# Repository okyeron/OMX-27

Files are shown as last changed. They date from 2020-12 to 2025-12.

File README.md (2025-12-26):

# OMX-27 version 3



OMX-27 is a compact DIY hardware MIDI controller and sequencer with RGB LED backlit mechanical key switches.

Version 3 of the hardware is based on the RP2040 microprocessor

Kits and specs are [available here](https://www.denki-oto.com/).

Information and code for earlier heardware versions is included in the [Archive](Archive/ReadMe.md) directory.

Dimensions:  313mm x 65mm  

## Docs

[New Documentation](https://okyeron.github.io/OMX-27/docs/)

[Old Documentation](<Docs.md>)

## Firmware 

Kits are shipped with the current firmware already flashed.

The OMX-27 firmware is Open Source and current uses PlatformIO (Arduino)

See [below](<#Firmware-Development>) to compile the firmware yourself.  

## Build

[Build Guide](<build/Build-Kit.md>)

## Web Configurator

[Online Configurator](https://okyeron.github.io/OMX-27/webconfig/index.html)

## BOM

OMX-27 v3 comes with SMD parts pre-assembled. Some alternate thru-hole parts are listed in the [Bill of Materials](<build/BOM.md>) for reference 

## Firmware Development  

Currently the firmware is best worked on with PlatformIO and VSCode. This may change in future.

### PlatformIO / VSCode

Ensure Homebrew in installed. [Instructions](https://brew.sh/)  
Install PlatformIO CLI tools. [Detailed Instructions](https://platformio.org/install/cli)

```sh
# Mac OSX
brew install platformio

# check out the project
git checkout https://github.com/okyeron/OMX-27.git

# go to the project directory
cd OMX-27-RP2040

# compile the project (this may take a while the first time)
pio run

# upload to hardware (press reset and boot and release reset before boot)
pio run -t upload
```

(optional) Install PlatformIO IDE VSCode extension. [Instructions](https://platformio.org/platformio-ide)

Install EditorConfig extension for your text editor. [Instructions](https://editorconfig.org/)
 
To open the project in VSCode :
- open a new window
- select the PlatformIO icon from the Primary Side Bar (left toolbar)
- use the "Pick a folder" button to select the OMX-27 folder you created above

## FAQ

Q: What key switches are recommended?  
A: The board uses a dual-footprint for either Cherry MX or Kailh Choc V1 switches. 

Q: Can I use other key switches?  
A: Yes - as long as they have the same footprint as Cherry MX or Kailh Choc V1 switches and a window/opening for the LED to shine through. NOTE - __Cherry Low Profile__ or__ Kailh Choc V2__ switches have a different footprint and will not work.

Q: What about recommended Keycaps if I want to customize?  
A: Also listed in the [BOM](<build/BOM.md>). It depends on which switches you use. You want a "shine thru" cap with a window for the LED.

Q: Does this project require soldering?  
A: Yes. Thru-hole soldering is required (Pots and switches).  

Q: Can I get the Gerbers or order the pcbs myself?  
A: No. Not open source at this time.

Q: Can I get some of those windowed keycaps you're using?  
A: Yes (send me an email).

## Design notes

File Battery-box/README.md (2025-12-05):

# Optional battery

A lipo battery can be added to OMX-27 v3.   

[This battery from tinycircuits is recommended](https://tinycircuits.com/products/lithium-ion-polymer-battery-3-7v-290mah). Also available from [Mouser](https://www.mouser.com/ProductDetail/TinyCircuits/ASR00007?qs=5aG0NVq1C4wXuuIqe7syiw%3D%3D) or [Digikey](https://www.digikey.com/en/products/detail/tinycircuits/ASR00007/7404517). [Octopart link](https://octopart.com/asr00007-tiny+circuits-84715901)  

The battery plug on the PCB is a JST SH connector (2 pin, 1.0 mm pitch) or you can solder the battery wires directly to the PCB. Please note the PCB markings for polarity. Looking down at the device, the red (+) terminal is on the left.  

A quick test gave about 4 hours of constant use on a single charge of the 290mah battery.  

3D printable battery box models are available below:

The parts are designed to use heat-set inserts for mounting - I used M2.5 4mmx4mm inserts - and then you can just use the same screws inserted from the bottom to attach everything.  

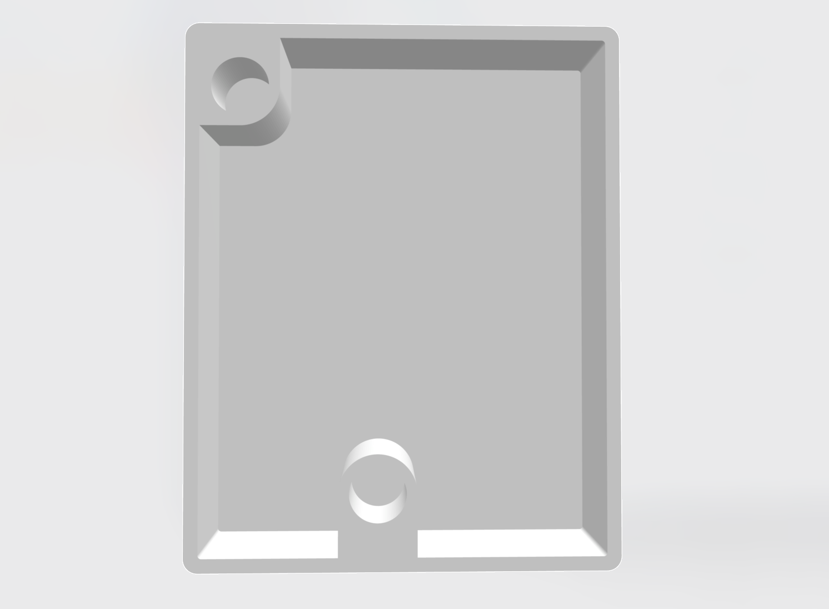
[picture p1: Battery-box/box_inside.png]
<# alt text #> box_inside


[Rectangular box](omx-27_battery_box_1a.stl)
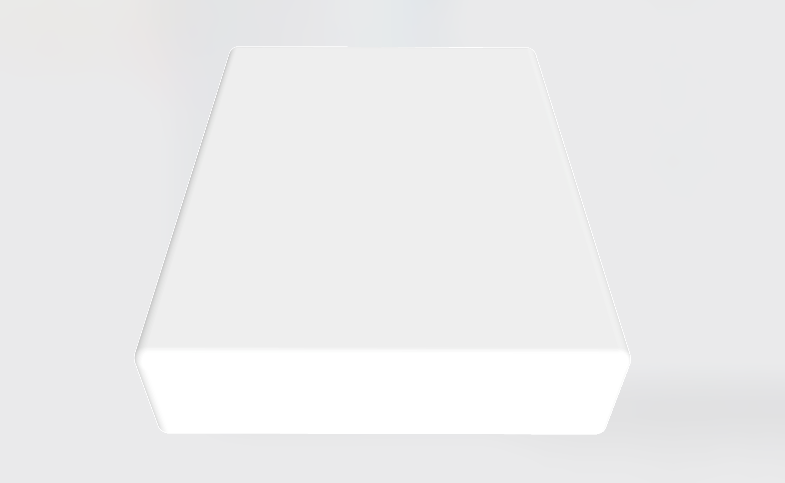
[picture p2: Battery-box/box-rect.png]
<# alt text #> box-rect


[L-shaped box](omx-27_battery_box_1b.stl)
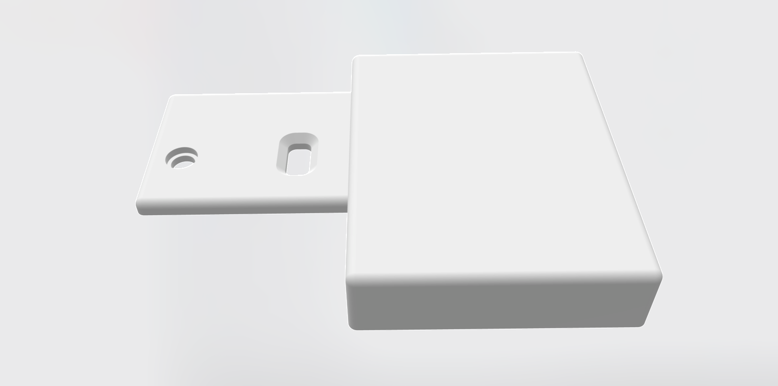
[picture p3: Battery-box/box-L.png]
<# alt text #> box-L


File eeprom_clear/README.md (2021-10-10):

# eeprom-clear

Quick sketch to reset the Teensy eeprom.

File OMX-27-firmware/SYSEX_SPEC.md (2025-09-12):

# OMX Sysex spec

The OMX-27 interfaces with its editor via MIDI Sysex. This document describes the supported messages.

_Work in progress, porting from 16n faderbank editor_

## `0x1F` - "1nFo"

Request for OMX-27 to transmit current state via sysex. No other payload.

## `0x0F` - "c0nFig"

"Here is my current config." Only sent by OMX-27 as an outbound message, in response to `0x1F`. Payload of 32 bytes, describing current EEPROM state.

## `0x0E` - "c0nfig Edit"

~~"Here is a new complete configuration for you". Payload (other than mfg header, top/tail, etc) of 80 bytes to go straight into EEPROM, according to the memory map described in `README.md`.~~ not implemented

## `0x0D` - "c0nfig edit (Device options)"

"Here is a new set of device options for you". Payload (other than mfg header, top/tail, etc) of 32 bytes to go straight into appropriate locations of EEPROM, according to the following map:
```
	//  64 bytes of data:
	//  0 - EEPROM VERSION
	//  1 - Current MODE
	//  2 - Sequencer PlayingPattern
	//  3 - MIDI mode MidiChannel 
	//  4 - 28 - Pots (x25 - 5 banks of 5 pots)
	//  29 - MIDI Macro Channel
	//  30 - MIDI Macro Type
	//  31 - Scale Root
	//  32 - Scale Pattern, -1 for chromatic
	//  33 - Lock Scale - Bool
	//  34 - Scale Group 16 - Bool
	//  35 - midiSettings.defaultVelocity
	//  36 - clockConfig.globalQuantizeStepIndex
	//  37 - cvNoteUtil.triggerMode
	// 	38 - actvie pot bank
	
	//  XX - 63 - Not yet used

```
Example: 
`F0 7D 00 00 0D 09 00 00 00 15 16 17 18 07 1D 1E 1F 20 21 22 23 24 25 26 27 28 29 2A 2B 5B 5D 67 68 69 00 00 00 F7`

## `0x0C` - "c0nfig edit (usb options)"

~~"Here is a new set of USB options for you". Payload (other than mfg header, top/tail, etc) of 32 bytes to go straight into appropriate locations of EEPROM, according to the memory map described in `README.md`.~~ not implemented

## `0x0B` - "c0nfig edit (trs options)"

~~"Here is a new set of TRS options for you". Payload (other than mfg header, top/tail, etc) of 32 bytes to go straight into appropriate locations of EEPROM, according to the memory map described in `README.md`.~~ not implemented

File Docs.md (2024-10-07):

# OMX-27 Documentation

# Table of contents
1. [Concepts](#concepts)
   1. [Layout](#layout)
   2. [Encoder](#encoder)
   3. [AUX Key](#auxkey)
   4. [Potentiometers](#potentiometers)
   5. [Key Switches](#keyswitches)
   6. [Changing Modes](#changingmodes)
   7. [Sub-Modes](#subparagraph1)
   8. [Saving Session State](#savingsess)
2. [Modes](#modes)
   1. [MI - Midi Keyboard](#mimode)
   2. [DRUM - Drum Keyboard](#drummode)
   3. [CH - Chord Keyboard](#chordsmode)
   4. [S1 - Sequencer 1](#s1mode)
   5. [S2 - Sequencer 2](#s2mode)
   6. [GR - Grids Sequencer](#gridsmode)
   7. [EL - Euclidean Sequencer](#elmode)
   8. [OM - Organelle Mother](#organellemode)
   9. [Screensaver](#screensaver)
3. [Hardware](#hardware)

# Concepts 

OMX-27 is a MIDI Keyboard and Sequencer. Both USBMIDI (in/out) and hardware MIDI out (via 1.8" TRS jack) are supported. Various "modes" can be accessed with the encoder and specific functions, parameters or sub-modes can be accessed with the encoder or key-presses/key-combinations.

Sequencer modes have 8 patterns (tracks). Sequencer modes currently send MIDI clock and transport control (start/stop) by default.

CV pitch output is limited to about 4.3 octaves.

USBMIDI should be plug-and-play with any USBMIDI compatible host. iPad works great with the camera connection kit or a [lightning to usb micro cable](https://www.amazon.com/gp/product/B09KLXNYHL). Hardware MIDI TRS output jack is switchable between Type-A and Type-B.

## Layout 

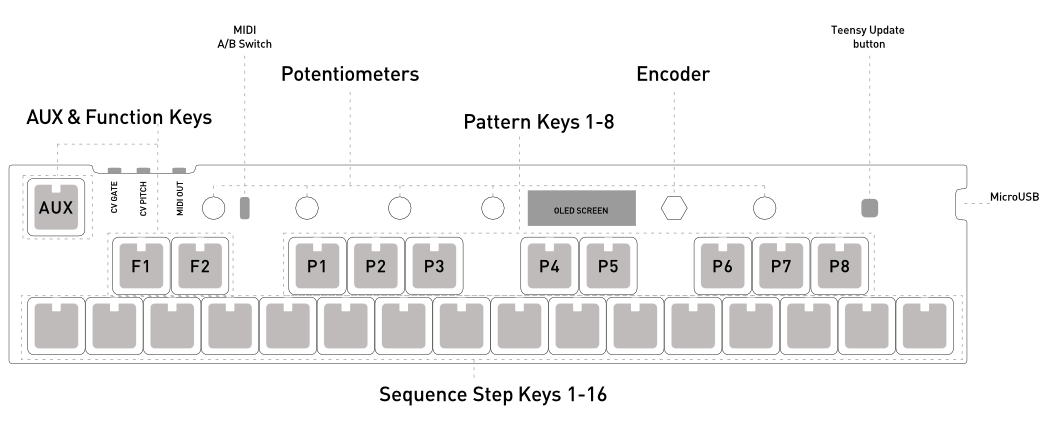
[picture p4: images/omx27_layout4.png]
omx27_layout3


## Encoder 

The encoder is the knob directly to the right of the display.

You can use the encoder to modify parameters and change the selected parameter and page. 

Short press the encoder once to toggle between selecting parameters and editing them. The selected parameter will be highlighted to reflect which mode you are in. 

Long press the encoder to change to a different mode. Once in mode selection, turn the encoder, then short-press to enter the selected mode.

## AUX Key 

The top left key is the AUX Key. 

In the MIDI Keyboard and Chords modes, holding this key gives you access to shortcuts. 

In the sequencer modes, this key is a dedicated start stop button. 

This key is also used in many places to quickly edit a parameter. To do this, hold down aux and turn the encoder to quickly edit the selected parameter without needing to press the encoder. If the encoder was already pressed, it is locked in edit mode and the aux shortcut won't work until you exit by pressing the encoder again.

If you are in a submode, the AUX Key can be used to exit out to the main mode. 

## Potentiometers 

The OMX-27 has 5 potentiometers which are mapped to send continuous controller MIDI messages (CCs). There are 5 banks of CCs available. You can switch banks using the PBNK parameter in the MI and DRUM Modes. 

Bank A is selected by default with the CCs set to controller numbers 21, 22, 23, 24 and 7 (volume). 

The CC's can also be reconfigured on device in the [CC Config page](#ccconfig), which is found on the last page of the MI Mode parameters. You can also configure the CC banks all at once via the [web configurator](https://okyeron.github.io/OMX-27/webconfig/index.html).

## Key Switches 

The functions of the key switches changes depending on which mode you are in. 

In MI Mode, the key switches work like a normal MIDI keyboard. 

In other modes, the keys have specific functions depending on the mode or submode. Most key interactions should also light up that key's LED.

In this documentation keys will be referred to by number, from left to right and position, top or bottom. Mentions of "White" or "Black" keys are in reference to a standard piano keyboard layout.

### "Black keys" (sharp/flat keyboard keys)

The top row (black) keys are referenced as **Top 1-10**.

The first 2 black keys are Function Keys (FUNC)
- F1 - First black key
- F2 - Second black key

FUNC keys are used to perform various shortcuts depending on the mode. 

The other black key functions depend on the current mode.

### "White keys" (bottom row)

The bottom row (white) keys are referenced as **Bottom 1-16**.

These have different functions depending on the current mode. For example, in sequencer modes, these are the sequencer step on/off keys.

## Changing Modes 

The OMX-27 has multiple modes. Each is independent - only one mode can be used at a time. 

Long press the encoder to change modes. 

## Sub-Modes 

Certain actions will cause you to enter a sub-mode, some examples could be editing MidiFX, configuring the pots, or saving/loading presets. If you are in a sub-mode, the AUX key will typically be flashing or red. A quick press of the AUX key will exit the sub-mode. 

## Macro-Modes 

Macro modes are like sub-modes in that they are an alternate mode. Macro-modes can take over the keys, display, encoder, and pots. 

Macro modes are specialized modes designed to be used to control external gear like the M8, Norns, and Deluge. 

You can enter and exit macro modes by double clicking the AUX key in the root level mode. 

Learn more about macro modes [here](#mimacromodes)

## Saving Session State 

To save your current session to memory, first enter Mode Select by holding the encoder. While this is active press AUX to save. 

The next time you restart your device, your last active mode will be loaded, and saved patterns and settings will be recalled. 

Saving is a long operation and not recommended to do while in the middle of a performance. 

---

# Modes 

The OMX-27 has multiple modes. Each is independent - only one mode can be used at a time. 

Long press the encoder to change modes. 

The current modes are:  
- [MI - Midi Keyboard](#mimode)
- [DRUM - Drum Keyboard](#drummode)
- [CH - Chords](#chordsmode)
- [S1](#s1mode) - A step sequencer with 8 patterns that can be up to 64 steps. Only one pattern can be active at a time  
- [S2](#s2mode) - The same as S1 but all 8 patterns are active  
- [GR - Grids Sequencer](#gridsmode) (A rhythm sequencer based on Mutable Instruments Grids)  
- [EL - Euclidean Sequencer](#elmode)
- [OM - Organelle Mother](#organellemode)

## MI - MIDI 

MIDI Keyboard. This mode makes the 26 keys act like a normal musical keyboard on a chromatic scale. 

### AUX Key: 

The top left key standing by it's lonesome is the AUX Key. While holding down this key, the other 26 keys will no longer play musical notes and instead give you access to quick shortcuts. 

Holding the AUX key will let you quickly edit the selected parameter. To do this, hold down aux and turn the encoder to quickly edit the selected parameter without needing to click the encoder. If the encoder was already clicked, it is locked in edit mode and the aux shortcut won't work until you exit by pressing the encoder again.

If you are in a submode like editing midi fx or the arp, the AUX Key can be used to exit out to the main mode. 

### KEYS & LEDS

Each of the 26 keys will play a note on the chromatic scale. The keys will light up when pressed. They will also light up to show incoming midi notes. 

If a scale is enabled, the keys that are in the scale will be lit up. 

### KEYS & LEDS - AUX Button Held

Hold down the AUX key to access quick functions. 

#### Top Keys
- **[1] Previous Parameter** : Selects the previous parameter in the menu
- **[2] Next Parameter** : Selects the next parameter in the menu

##### MidiFX
Select which midifx slot to send the keyboard notes to.
Double click or long hold a MidiFX key to enter the MidiFX sub-mode and edit the effects.
See [MidiFX](#midifx) for more info. 

- **[5] MidiFX Off** : Notes from the drum key will be sent directly out
- **[6] MidiFX 1**
- **[7] MidiFX 2**
- **[8] MidiFX 3**
- **[9] MidiFX 4**
- **[10] MidiFX 5**

#### Bottom Keys
##### The Highest Highs and Lowest Lows
- **[1] Octave Down**
- **[2] Octave Up**

##### Arpeggiator
- **[12] Edit Params** : Enters a pass through arp edit sub-mode allowing you to edit arp values and also play the keyboard. You can also edit the arp in the MidiFX sub-mode but will need to exit the sub-mode to play the keyboard.
- **[13] Change Pattern** : Cycles through arpeggiator patterns  
- **[14] Change Octave** : Cycles through arpeggiator octave ranges  
- **[15] Toggle Hold** : Toggles the arpeggiator hold function  
- **[16] Power** : Toggles the arpeggiator on and off  

### Menu Pages

**Page 1 - Midi Out:**
- `OCT`: Current Octave  
- `CH`: Active MIDI Channel 
- `VEL`: The velocity level for midi notes 

**Page 2 - Inspect:**
Not editable, this shows which notes and CC's have been sent. 
- `P CC` : Pot CC, this is the CC number of the last pot that was used. 
- `P Val` : This is that last CC value of the last pot that was used. 
- `NOTE` : This is the number of the last note that was sent. Note that notes generated by MidiFX will not be seen here. 
- `VEL` : This is the velocity of the last note that was sent. 

**Page 3 - Midi Tools:**
- `RR`: RoundRobin MIDI Channel distribution
- `RROF`: RR offset value   
- `PGM`: MIDI program change  
- `BNK`: MIDI bank select.

**Page 4 - Pots & Macros:**
- `PBNK`: Potentiometer bank select
- `THRU`: When "On" incoming USBMIDI is passed to TRS MIDI Out.
- `MCRO`: MIDI Macro Mode Select (default is OFF)
- `M-CH`: MIDI Macro Mode Channel

**Page 5 - Scales:**
- `ROOT` : Select the root note for scale mode
- `SCALE` : Select a scale or turn off scale mode
- `LOCK` : Locks to the active scale. If this is enabled, you can only play notes in the scale
- `GROUP` : Groups all the notes of the scale across the lower row of 16 keys. 

**Page 6 - Config:**
- `CC` : Function, press down on the encoder to use. This enters the configuration tool for setting up the CC values for each pot bank.

### Musical Scales

Scales can be turned on using the 5th parameter page. When a scale is enabled, the keys in the scale light up, and the root notes light up a brighter color. You can still play chromatically and out of key. 

Enabling the 'LOCK' param makes it so only the notes in the scale send midi notes out. 

Turning on the 'GROUP' parameter maps the scale across the lower row of 16 keys. The root note starts on bottom key 2 which would normally be a C in chromatic mode. 

These scale settings also control the scale of the Scaler MidiFX when they are set to use the global scale. 

### CC Configuration Submode 

This mode lets you change the CC values that the potentiometers send out. 

Bottom Keys 1-5 let you quickly change the selected bank.  

Press the AUX key to exit. 

### MidiFX 

MidiFX are effects that can be applied after midi data is generated by playing keys or a sequencer and before any midi data goes out of the device. 

MidiFX can currently only be used within the: MIDI Keyboard (MI), Chords (CH) and Euclidian (EL) modes.

MidiFX currently only work on internally generated midi, but may support external midi coming in from USB in the future. 

MidiFX are arranged in groups of 8 MidiFX. A group of 8 is called a MidiFX Group. In the MI Mode, midi notes generated by playing the keyboard can only be routed to one MidiFX Group. In the sequencer modes, midi notes can be routed to different MidiFX groups by track. 

Think of a MidiFX group as a pedalboard for Midi. Midi data comes in from the left and go to MidiFX slot 1, then out of slot 1 to slot 2, until slot 8, then out of the device. 

You can change the active MidiFX group in the MI Mode and the Chords modes by holding aux and pressing one of the Top Keys 6-10. 

To enter the MidiFX submode, hold AUX, then hold or double click on a MidiFX Key(Top Keys 6-10). 

Top Key 1: Copy  
Top Key 2: Paste  
Top Key 1 + 2: Cut  
Top Keys 3 - 10: Select a MidiFX slot  
Bottom Keys: Add or change the type of MidiFX for a slot. You must hold down the MidiFX slot key in order to change.   

To move a MidiFX slot around, you can either cut and paste, or you can hold a MidiFX slot key and turn the encoder.  

There are several different MidiFX available for each slot. Select a MidiFX slot, and you can edit the parameters for that instance of a MidiFX.  

Each MidiFX type has a chance parameter. If this is less than 100%, than there is a chance this effect will not be applied.  

Available MidiFX:  
- Chance: Uses randomness to determine if a note passes through: 100% or gets killed: 0%  
- Transpose: Transpose midi notes by semitones or octaves  
- Randomizer: Randomize notes by range, octaves, velocities, and note lengths.  
- Harmonizer: Generate multiple notes from a single note. Great for 1 key chords, or to randomly play chords by setting it's chance parameter to less than 100%  
- Scaler: This forces notes into a specific scale.  
   - By default this uses the global scale. Modifying the root and scale pattern parameters changes the global scale.   
   - You can turn 'GLBL' to off to make this MidiFX instance use it's own unique root and scale pattern.   
- Make Mono: This forces polyphonic midi notes into monophonic.   
- Arpeggiator: This is an advanced arpeggiator. An arpeggiator MidiFX is automatically  added to a MidiFX group if you use any of the arpeggiator AUX quick keys.  
   - Try combining the arpeggiator with other MidiFX either before or after the arpeggiator for interesting effects.  
   - Arpeggiators are reasonably resource intensive, try to avoid using more than 3 of them in a MidiFX group for optimal performance.  

### Arpeggiator 

The arpeggiator is an advanced arpeggiator with many different combinations of patterns, Mod Patterns, and Transpose patterns. 

The arpeggiator is actually a MidiFX and is only available in the modes that support MidiFX: MIDI Keyboard (MI), Chords (CH), and Euclidian Sequencer (EL).

In MIDI Keyboard and Chords modes, holding AUX allows you to quickly change basic settings of the arpeggiator. In order to access the more advanced functionalities, you need to access the arpeggiator parameters by either entering the MidiFX Group submode or by accessing the Arpeggiator pass-through mode by using AUX + Bottom Key 12.

The arpeggiator sends clock when in use.

#### Arp Menu Pages:

**Page 1 - Arp Settings 1:**
- `MODE`: Arpeggiator mode: On, 1-Shot, Once, Hold  
- `PAT`: The pattern of the arpeggiator  
- `RSET`: Determines what will cause the arpeggiator to reset  
- `CHC%`: How likely an incoming note will be used with the arpeggiator. Try playing with in the euclidean sequencer mode  

**Page 2 - Arp Settings 2:**
- `RATE`: How fast the arpeggiator plays  
- `RANG`: How many octaves to advance through  
- `GATE`: How long a note coming out of the arpeggiator is  
- `BPM`: Controls the master tempo  

**Page 3 - Arp Settings 3:**
- `ODIST`: How many semitones to consider an octave. Set to -12 to make the arpeggiator go downwards. Set to a semitone offset if you like to get weird  

**Page 4 - Inspect:**
These are not modifyable  
- `VEL` : Velocity based on first notes that turn on the arp  
- `CHAN` : First note that starts the arp sets the channel  
- `MIDI` : If midi data is output
- `CV` : If CV data is output  

**Page 5 - Mod Pattern:**
- Each of the 16 steps can be used to modify the arp pattern in various ways  

**Page 6 - Transpose Pattern:**
- Each of the 16 steps can be used to transpose notes in semitones 
- Recommend trying to use for some cool one key bass patterns  

### MIDI Macro Modes 

Midi macro modes are specialized Midi controller modes designed to be used with specific hardware that can be controlled via Midi. 

If a midi macro is selected, you can double click the AUX key to enter the midi macro mode, and double click the AUX key to exit the macro mode.

Midi macro modes send control midi commands on the Midi Macro channel, which is `M-CH` in the parameters.

Macro modes are supported in the MI and DRUM modes. 

#### M8 Macro Mode

From MI Mode, be sure `M8` is selected from the `MCRO` parameter and then double click the AUX button to enter Macro Mode.

`M-CH` should be set to the same value as the Control Map Channel in the M8 MIDI settings screen. Default is set to channel 10.  

Double click the AUX button again to exit Macro Mode.

The M8 macro mode has two pages, which change what the Keys do.

* Mute Solo Page:

The bottom row of keys correspond to mutes (orange) and solos (red). The top "black keys" are as follows:  

```
Orange - release all mutes  
Lime - go to mixer screen  
Cyan - snapshot load/paste *   
Magenta - snapshot save/enter selection mode *  
Red - release all solos  
Yellow - waveform display  
Blue - play  
```
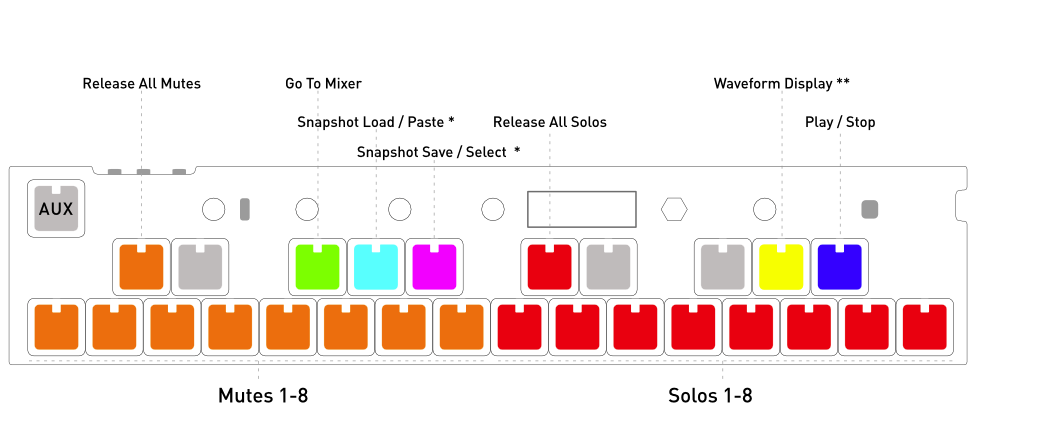
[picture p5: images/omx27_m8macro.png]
omx27_m8_macro_mode


When M8 is selected from the `MCRO` parameter - potentiometers send on the `M-CH` MIDI channel in both regular keyboard mode and in the macro mode. However, notes played on keys send on the currently selected `CH` MIDI channel.

**Notes:**
* M8 must be on the Mixer view for snapshots.  
* Snapshot Load uses the M8 key combo [SHIFT]+[OPTION]. On any view with a grid (song, chain, phrase, table, etc.) this key enters selection mode.  
* Snapshot Save uses the M8 key combo [SHIFT]+[EDIT]. On any view with a grid this key pastes the copied contents from selection mode.  

* Control Page:

This page lets you navigate the M8 using the keys on the device instead of the keys on the M8.

Top Key 1 and Bottoms Keys 1-3: These correspond to the directional arrow keys. 

Top Key 4: Option Key
Top Key 5: Edit Key
Bottom Key 6: Shift Key
Bottom Key 7: Play Key

The right half of the Keyboard is a 1-octave midi keyboard that sends notes on the same midi channel as when not in macro mode. 

#### Norns Macro Mode

The Norns macro mode gives you the ability to control the Monome Norns using the OMX-27. In this mode, you can control the three buttons and three encoders using the OMX-27. This is useful if your norns is not located close by and you would like to control it.

Find the `MCRO` parameter in the menu and select `NRN` to enable the Norns Macro mode. 

Double click the AUX button to enter Macro Mode. Double click the AUX button again to exit Macro Mode.

##### Norns Setup
In order for this to work, you will need to setup the [qremote mod](#https://llllllll.co/t/qremote/57549) on your norns. 

Obtain the mod here: https://llllllll.co/t/qremote/57549

or install in Maiden
`;install https://github.com/Quixotic7/qremote`

Enable the mod in the mod menu of norns, connect your OMX-27 to the norns and restart. The easiest way to connect the OMX-27 is to simply use a USB port on the norns. 

The qremote mod will default to using midi channel 10. If you are using defaults, make sure your OMX-27 Macro Channel `M-Chan` is set to 10. 

Use the default configuration for encoders and buttons:

The default cc’s for the encoders are 58, 62, & 63

The default cc’s for the buttons are 85, 87, & 88

You can change these in the parameter menu. Or edit the script to change the defaults.

##### Norns Buttons
These act the same as if pressing the buttons on the Norns.
- **[Top 3] B1**
- **[Bot 4] B2**
- **[Bot 5] B3**

##### Norns Encoders
Use the OMX-27 Encoder to control one of the Norn's encoders. Since the OMX-27 only has one encoder, shortcut keys are used to determine which encoder will be controlled.
- **[Top 5] Enc 1**
- **[Bot 6] Enc 2**
- **[Bot 7] Enc 3**

##### Norns Navigation
The keys of the OMX-27 are used to emulate up/down left/right keys useful for menu navigation. These work by controlling encoder 1 or encoder 2, sending one tick either clockwise or counter-clockwise. 
- **[Top 1] Up**
- **[Bot 1] Left**
- **[Bot 2] Down**
- **[Bot 3] Right**

#### Deluge Macro Mode

The latest Deluge Community Firmware has added a new feature called Midi-Follow. 

https://github.com/SynthstromAudible/DelugeFirmware/blob/community/docs/features/midi_follow_mode.md

This mode provides default CC mappings to control many of the synth parameters with a midi controller and to be able to play the active instrument without needing to midi learn everything. 

This Macro Mode provides parameter banks to control every available parameter on the Deluge using the 5 pots of the OMX-27. The Deluge will also send back the values of the parameters to the OMX-27 which will update the values in each bank on the OMX-27. This will only work if you are connected via USB as the OMX-27 does not have TRS Midi-in. Values are updated when changing them from the gold knobs, or from edit view, when entering a clip view, or when changing a synth or kit.

##### Deluge Setup

Download and install the latest Deluge Nightly Firmware: https://github.com/SynthstromAudible/DelugeFirmware/releases . This Midi-Follow feature is not included in the 1.0.1 release. There is also a new beta build released which should have the feature, but it is not confirmed. 

To install the FW, place the `.bin` file on your sd card, ensuring there are no other `.bin` files. Carefully reinsert the SD Card in the Deluge, if it is misangled it can fall into the device. Turn on the Deluge while holding the shift key. 

Hold Shift + Click the main Select Knob, find Midi, click the Select Knob, find "MIDI-FOLLOW", click the select Knob, find "CHANNEL", click the select Knob, set each channel to something, I recommend channel 10. Also from the "MIDI-FOLLOW" level, select "FEEDBACK" and set the channel to 10 as well. 

For further help see https://github.com/SynthstromAudible/DelugeFirmware/blob/community/docs/features/midi_follow_mode.md 

##### OMX Setup

Find the `MCRO` parameter in the menu and select `DEL` to enable the Deluge Macro mode. Change Macro Channel `M-CH` to 10 or whatever you set your Deluge to.

Double click the AUX button to enter Macro Mode. Double click the AUX button again to exit Macro Mode.

##### KEYS & LEDS
The keyboard is split into two halves. 

The right octave of the keyboard works the same as the midi keyboard from MI Mode and will inherit it's settings. 

The left half of the keyboard is dedicated to selecting different banks of parameters. 

Some keys will have multiple banks assigned to them, to access the other banks, click the key a second time. 

- **[Top 1] Env 1**
- **[Top 2] Env 2**
- **[Top 3] LPF**
- **[Top 4] HPF**
- **[Top 5] EQ**
- **[Bot 1] Master**
- **[Bot 2] OSC 1**
- **[Bot 2] FM 1** : Click the key a second time
- **[Bot 3] OSC 2**
- **[Bot 3] FM 2** : Click the key a second time
- **[Bot 4] LFO Delay Reverb**
- **[Bot 4] ModFX** : Click the key a second time
- **[Bot 5] Distortion Noise**
- **[Bot 6] Arp Sidechain**
- **[Bot 7] Custom 1** : Bank of 5 parameters you can midi learn to whatever
- **[Bot 7] Custom 2** : Click the key a second time

##### KEYS & LEDS - AUX Button Held

###### Select a parameter
This will select a parameter. If you click the encoder to enter edit mode the encoder can be used to change the value without needing to pickup the pot. 
- **[Top 1] Param 1**
- **[Top 2] Param 2**
- **[Top 3] Param 3**
- **[Top 4] Param 4**
- **[Top 5] Param 5**

###### Change octave
This effects the keyboard on the right half.
- **[Bot 1] Octave Down**
- **[Bot 2] Octave Up**

###### Lock the AUX View
This locks the AUX view, allowing you to use the AUX shortcuts without holding down the AUX key. To unlock, use the AUX button again or press the lock AUX key. 
- **[Bot 4] Lock AUX**

###### Revert Values
This will revert the values of the current bank to their previous state. The previous state is saved whenever the bank is changed, or when the values are updated from incoming Midi from the Deluge. This is fun to play with with the effects, crank up the bitcrush, delay, or reverb temporally, then press this button to revert it back to what it previously was. 
- **[Bot 8] Revert Bank**

##### POT Pickups
Depending on which bank is selected, the OMX-27 will send out different CC's for each of the 5 potentiometers. When a change is detected on a pot, the screen will update to show the name of the current bank, parameter, and value that is being sent. 

In the MI and Drum modes, the pot values that are sent jump to the current position of the pot. In the Deluge Macro, you will need to pickup the value before it is sent. The small triangle on the screen represents the current raw value of the pot, the horizontal bar represents the value for that parameter. You will need to turn the knob left or right to pickup the value. 

The Deluge can also be setup to pickup, however this macro will work best if the Deluge is set to jump. 

##### Encoder
The encoder can be used to send out values without needing it to be picked up. To edit a parameter, click the encoder, then turn. There is not currently a visual representation to provide feedback for this. If you click the encoder again, you can scroll to change which parameter in the bank to control. You can also use the AUX shortcuts to quickly jump to parameters, or lightly wiggle a knob. 

---

## DRUM - Drum Keyboard 

This mode shares a lot in common with the MI mode. The main difference is that instead of each key being a key on a chromatic keyboard, each of the 26 keyboard keys can be assigned to send out a unique note, velocity, and midi channel. This is useful if you want to use the OMX to play an external drum machine or samples, or multiple drum machines on different  midi channels, or for any purpose you'd like really, feel free to get creative!

The grouping of 26 keys is called a "Drum Kit" and you can store up to 8 different drum kits on the OMX. 

Press any key to play it. A note on will be sent when pushed and a note off will be sent once released. 

**Selected Drum Key** - This is the last key that was pressed down, it is visually represented by a flashing LED.

The first two pages on the OMX display can be used to change the settings for the selected drum key. Each key can be configured to send a unique note number, velocity, midi channel, and be routed to one of the 5 MidiFX slots. Yes, you can use multiple MidiFX at once. You could have one drum key be routed to MidiFX 1 which has an arp to play a bassline, another key could go to MidiFX 2 with a different arp to play a melody, then another key could be setup to play a kick drum which is routed to MidiFX 3 which has a randomizer enabled to randomly vary the velocity each time it is played. Go wild, get creative, there are no bounds, welcome to OMX!

### Menu Pages
**Page 1 - DrumKey 1:**
Values apply to the selected drum key
- `NOTE` : Midi note number that the drum key will send
- `CH` : Midi Channel that the drum key will send
- `VEL` : Velocity of the note the drum key sends
- `FX#` : Number of the MidiFX slot that the note is sent to

**Page 2 - DrumKey 2:**
- `HUE` : Changes the color of the selected drum key
- `HUE RND` : Function, press down on the encoder to use. This will randomize all the hues in the current drum kit.

**Page 3 - Scales:**
This changes the current scale settings. While a scale won't normally apply to the drum kit, the scale settings are shared globally with the MidiFX. So if you are using a scale MidiFX, this makes it easy to change up the scale without needing to edit the MidiFX. 
- `ROOT` : Root note of the scale. 
- `SCALE` : Which scale to use.
- `LOCK` : Only notes in the scale can be played, has no effect on the drum kit keys. 
- `GROUP` : Groups the notes in keyboard view accross the lower keys, no effect on the drum kit keys. 

**Page 4 - Inspect:**
Not editable, this shows which notes and CC's have been sent. 
- `P CC` : Pot CC, this is the CC number of the last pot that was used. 
- `P Val` : This is that last CC value of the last pot that was used. 
- `NOTE` : This is the number of the last note that was sent. Note that notes generated by MidiFX will not be seen here. 
- `VEL` : This is the velocity of the last note that was sent. 

**Page 5 - Pots & Macros:**
Settings for the potbank, midi, and macro modes. 
- `PBNK` : Pot Bank - Determines which potbank is active. 
- `THRU` : Midi Thru - If this is on, incoming midi from USB will be sent out the TRS midi jack. 
- `MCRO` : Macro - Determines which macro is active. Macros can be entered by double clicking the AUX key. 
- `M-CH` : Macro channel - Determines which midi channel is used by the macro. 

**Page 6 - Config**
- `CC CFG` : Function, press down on the encoder to use. This enters the configuration tool for setting up the CC values for each pot bank.

### KEYS & LEDS - Main Screen
Each key represents a drum pad in your drum kit. 

Pressing a key will send a note on. Releasing it will send a note off. Which note is sent for each key can be configured by pressing the key, then editing it's varaibles in page 1 and 2 of the menu.

The flashing key is the Selected Drum Key. 

Each key can be any color determine by the HUE variable of each drum key. 

### KEYS & LEDS - AUX Button Held
Hold down the AUX key to access quick functions. 

#### Top Keys
- **[1] Previous Parameter** : Selects the previous parameter in the menu
- **[2] Next Parameter** : Selects the next parameter in the menu

##### saving and loading drum kits
- **[3] Load Kit** : Use this to load a kit
- **[4] Save Kit** : Use this to save a kit

##### MidiFX
Unlike the MI Keyboard mode, the midifx slot only applys to the selected drum key.
See MidiFX for more info. 
- **[5] MidiFX Off** : Notes from the drum key will be sent directly out
- **[6] MidiFX 1**
- **[7] MidiFX 2**
- **[8] MidiFX 3**
- **[9] MidiFX 4**
- **[10] MidiFX 5**

#### Bottom Keys
##### Quickly switch kits
- **[1] Load Prev Kit** : Loads the next kit out of 8, any changes to the current kit will be autosaved
- **[2] Load Next Kit** : Loads the previous kit out of 8, any changes to the current kit will be autosaved

##### Arpeggiator
- **[12] Edit Params** : Enters a pass through arp edit sub-mode allowing you to edit arp values and also play the keyboard. You can also edit the arp in the MidiFX sub-mode but will need to exit the sub-mode to play the keyboard.
- **[13] Change Pattern** : Cycles through arpeggiator patterns  
- **[14] Change Octave** : Cycles through arpeggiator octave ranges  
- **[15] Toggle Hold** : Toggles the arpeggiator hold function  
- **[16] Power** : Toggles the arpeggiator on and off  

### Potentiometers

---

## CH - Chords 

Ever wanted to play insanely complex chords with the click of a button? Well now you can! In Chord mode, the bottom 16 keys can each be assigned to play a unique chord. 

### UI Views

There are two UI views: "Split" and "Full". This can be changed on page 2. By default, the UI layout is in "Split Mode" meaning the right half of the keyboard works like a 1 octave keyboard and the left half will give you 8 chords that can be played. In "Full" mode, each of the 16 bottom keys will play chords.

### Key Modes

There are several different modes available which can be switched using the top keys 3, 4, & 5.

- **[Top 3] Play Mode**
- **[Top 4] Edit Mode**
- **[Top 5] Strum Mode**

#### Play Mode
- **[Top 3] Play Mode**

This mode is where you want to be if you would like to play chords and the keyboard(Split UI Mode) at the same time. Switching to this mode will bring the menu to the first page, displaying a keyboard that shows the notes of the last chord key that was pressed. You can still edit chords through the menu by switching pages.

#### Edit Mode
- **[Top 4] Edit Mode**

This mode is for editing the available chords and will bring the menu to the chord edit page. 

When in the edit mode and in the "Split" UI view, you can hold down a chord key on the left half and press a key on the right half to set the root note for basic chords. For interval chords, the right half will not change anything. 

The first two top keys, key 1 and key 2 act as function keys F1 and F2 in this mode.

- **[Top 1 - F1] Edit Chord** : Holding F1 and pressing a chord key will enter a edit chord submode.   
- **[Top 2 - F2] Copy Chord** : Holding F2 and pressing a chord key will save the selected chord to the newly selected chord slot. 

#### Strum Mode
- **[Top 5] Strum Mode**

This mode allows you to strum chords using the encoder. The UI view will change to "Full" in this mode. 

To use this mode hold down a chord key and turn the encoder CW or CCW. Only the last pressed chord will be strummed. Multiple chords will not be strummed. 

##### Strum Pot Parameters. 
In strum mode, the 5 pots are used to change the behaviour of the strum. 

- **[Pot 1] Sens - Sensitivity** : This determines how much the encoder needs to be turned to trigger a new note
- **[Pot 2] Wrap** : If this is off, the chord can be strummed once, if this is on, the chord will wrap back to the beginning like an arpeggio. 
- **[Pot 3] Increment / Octave** : This is only valid if Wrap is on. If it is, each time the chord wraps the notes will increase by an octave. This value determines how many octaves will be added before resetting. 
- **[Pot 4] Sustain** : This value determines how long each strum note will be played for. 
- **[Pot 5] Not Assigned**

### Chord Key Settings

A chord key is either bottom key 1-8 in "Split" UI mode or bottom key 1-16 in "Full" UI Mode. Pushing a chord key will play a chord, and releasing the key will stop playing the chord. Multiple Chord Keys can be pressed at once, and also combined with the 1 Octave midi keyboard on the right half in "Split" UI mode. 

Each chord key can have a unique chord type, velocity, midi channel, and be routed to one of 5 MidiFX(#midifx) slots. 

The last chord key that was pressed becomes the selected chord key. This is visually represented on the LEDs as that key will stay lit up

**Page 4 - Chord Key Settings:**
These parameters apply to the selected chord key
- `TYPE` : Determines the chord type: Basic`BASC` or Interval`INTV`, see section below on chord types. 
- `MIFX` : Which [MidiFX](#midifx) will this chord be sent to? 
- `VEL` : Velocity of the notes in the chord
- `MCHAN` : Midi channel of the notes that this chord gets sent to

### Chord Types

Two types of chords are currently available: Basic and Interval. Basic chords don't have many settings and are quick to tweak. Interval chords have a lot more options and are linked to the current global musical scale. 

#### Basic Chords 
These chords have no relation to the current global musical scale. 

All the parameters are shown on a single page that will show 4 ghosts. 

- `NOTE` : Determines the root note of the chord
- `OCTAVE NUMBER` : Determines the octave of the root note
- `GHOSTS` : The ghosts determine how the chord is voiced. Each ghost represents the order of the notes in the chord. The vertical position of a ghost determines the velocity of that notes. A large white ghost will play a note in the same octave as the root note. A large black ghost will play a note one octave below. A short white ghost will play a note one octave above. 
- `SCALE` : Determines the scale of the chord. The last scale is called "Custom" and will let you manually set the notes in the chord. 

##### Custom Chords
If `SCALE` is set to `Custom` an additional page in the menu will be revealed. In this page you can program up to 6 notes. 

The first 4 notes will be modified +- an octave, or turned off based on your `GHOST` settings

The value of each note in a custom chord is defined as a semitone from the root note of the chord. For a C Maj basic triad chord, you would set this to `RT +4 +7` . `RT` means root note. 

#### Interval Chords 
These chords are linked to the current global musical scale. If you play an interval chord and it does not sound good, start by seeing if you have a global scale enabled, and make sure it's not chromatic. 

##### Interval Menu Page 1
- `#NTS` - Number of notes : How many notes to play, 1 - 4
- `DEG` - Degree : Determines which degree of the the current global scale to start the chord on. If the global scale was C Maj, then Deg 0 would play a chord that starts on C, Deg 1 would play a chord that starts on D, Deg 6 would play a chord that starts on B. 
- `OCT` - Octave : The octave of the chord is determined by the global octave +- this value. 
- `TPS` - Transpose : This will transpose the chord by a seminote. Do note that if you transpose a interval chord it will no longer be in scale. 

##### Interval Menu Page 2
- `SPRD` - Spread : This determines how many octaves the chord is spread out across the keyboard. 
- `ROT` - Rotate : This rotates the notes of the chord. for a C Maj Triad, rot of 0 will play C E G, rot of 1 will make E the lowest note, playing E G C+1oct, rot of 2 will make G the lowest note
- `VOIC` - Voicing : Changes the voicing of the chord. Still stays in scale, but will shift notes or add additional notes. 

##### Interval Menu Page 3
- `UPDN` - Spread Up & Down : This will spread the notes out in a negative octave and positive octave. 
- `QRTV` - Quartal Harmony : This enables Quartal Harmony. I have no idea what this is doing music theory wise, but it sounds cool. Technically it's bumping the first note up two octaves, the third note up one octave, and the fourth note down 1 octave. It's supposed to separate the notes by 4ths. 

### Menu Pages

##### Menu Page 1 - Keyboard
This page will display a keyboard on the screen showing which notes are being played from the last chord key that was pressed. 

##### Menu Page 2 - Chord Mode Settings
- `UI` : Change the UI View from `SPLIT` or `FULL`. Split view adds a 1-octave midi keyboard on the right half of the keys. in Full view, all 16 of the bottom keys play chords.

##### Menu Page 3 - Keyboard Midi Settings
These settings apply to the 1-octave keyboard on the right side if the UI View is in `SPLIT` view. Each chord has unique settings.
- `OCT`: Current Octave. This value also changes the base octave used by interval chords
- `CH`: Active MIDI Channel 
- `VEL`: The velocity level for midi notes 

##### Menu Page 4 - Pots and Macros
- `PBNK`: Potentiometer bank select
- `THRU`: When "On" incoming USBMIDI is passed to TRS MIDI Out.
- `MCRO`: MIDI Macro Mode Select (default is OFF)
- `M-CH`: MIDI Macro Mode Channel

##### Menu Page 5 - Scale Settings
The scale settings apply to the 1-octave keyboard on the right side if the UI View is in `SPLIT` view and also will effect the interval chord keys. 
A scale should be set to something other than chromatic to get good results from interval chords. 
- `ROOT` : Select the root note for scale mode. This changes what note the interval chords will play. 
- `SCALE` : Select a scale or turn off scale mode
- `LOCK` : Locks to the active scale. If this is enabled, you can only play notes in the scale
- `GROUP` : Groups all the notes of the scale across the lower row of 16 keys. 

##### Menu Page 6 - Chord Key Settings
This changes the settings of the selected chord key. See [Chord Key Settings](#chordkeysettings)

##### Menu Page 7 - Basic or Interval Chord Key Settings
These pages will be different depending if the selected chord key is set to Basic or Interval.
See [Basic Chords](#basicchords) or [Interval Chords](#intervalchords)

### KEYS & LEDS - AUX Button Held
Hold down the AUX key to access quick functions. 

#### Top Keys
- **[1] Previous Parameter** : Selects the previous parameter in the menu
- **[2] Next Parameter** : Selects the next parameter in the menu

#### Saving and loading
- **[3] Load Bank**
- **[4] Save Bank**

##### MidiFX
This sets the MidiFX slot that either the keyboard in split UI view is being sent to, or the selected chord key is being sent to. Whichever key was last used determines this. You can also change the midifx slot a chord key is sent to from the menu, see [Chord Key Settings](#chordkeysettings)
Hold or double click a MidiFX key to enter the MidiFX submode. 
See [MidiFX](#midifx) for more info. 
- **[5] MidiFX Off**
- **[6] MidiFX 1**
- **[7] MidiFX 2**
- **[8] MidiFX 3**
- **[9] MidiFX 4**
- **[10] MidiFX 5**

#### Bottom Keys
##### Change Octave
This changes the global octave. This value will change the octave of the midi keyboard in split view and also change the base octave of interval chords.
- **[1] Prev Octave**
- **[2] Next Octave**

##### Arpeggiator
This effects the Arpeggiator on the currently selected MidiFX slot that the midi keyboard is being sent to.
- **[12] Edit Params** : Enters a pass through arp edit sub-mode allowing you to edit arp values and also play the keyboard. You can also edit the arp in the MidiFX sub-mode but will need to exit the sub-mode to play the keyboard.
- **[13] Change Pattern** : Cycles through arpeggiator patterns  
- **[14] Change Octave** : Cycles through arpeggiator octave ranges  
- **[15] Toggle Hold** : Toggles the arpeggiator hold function  
- **[16] Power** : Toggles the arpeggiator on and off  

### Saving and Loading
- **[AUX + Top 3] Load Bank**
- **[AUX + Top 4] Save Bank**

Use these shortcuts to save and load banks of chords. There are 8 available banks. If you load a bank other than the current one, the current bank will be autosaved. You can revert changes to your current bank by loading the same bank again. 

---

## S1 - Sequencer 1 

Step sequencer - One pattern active at a time.

Layout: 

### "Black keys" (sharp/flat keyboard keys)

The first 2 black keys are Function Keys (FUNC)
- F1 - First black key
- F2 - Second black key

The next 8 are Pattern Keys and they select the active sequence pattern (P1-P8).

Hold a key (long press) to access parameters for that pattern. This is "Pattern Params".

### "White keys" (bottom row)

Sequencer Step Keys - These are your sequencer step on/off keys.

Hold a key (long press) to access parameters for that step. This is "Note Select / Step Parameters". F1 + Step Key is also a quick shortcut.

Keys/Commands:   
 - AUX is Start/Stop  
 - Start/Stop sends MIDI transport control, and MIDI clock when running  
 - Pattern Key: Selects playing pattern  
 - F1 + AUX: Reset sequences to first/last step  
 - F2 + AUX: Reverse pattern direction  
 - F1 + Pattern Key: Enter __Step Record__ (transport must be stopped)  
 - F2 + Pattern Key: Mute that pattern  
 - F1 + Step Key: Enter __Note Select / Step Parameters__  
 - Long press a Step Key: Enter __Note Select / Step Parameters__   
 - Long press a Pattern Key: Enter __Pattern Parameters__  
 - AUX-key exits sub-modes  
 - Hold F1 + F2: first 4 "white keys" select "page" of the current pattern (depending on pattern length)  

Parameters:  
(see below) 

### Note Select / Step Parameters

Long press a step key to enter this mode. Here you can change the note values (note number, velocity, note length and octave), set CC parameter-lock values with the knobs, and set step parameters (step events, step probability, trig conditions).

While in Note Select, the rightmost and leftmost keys will blink (orange or blue)- these 2 keys will shift the current octave up or down.

Press AUX to exit Note Select.  

Parameters:  

Page 1:  
- `NOTE`: midi note number  
- `OCT`: octave  
- `VEL`: note velocity  
- `LEN`: note length in steps (1-16)   

Page 2:  
- `TYPE`: step event type (see below)  
- `PROB`: percentage of the step triggering  
- `COND`: trig conditions (see below)  

Page 3: (set CC parameter-locks)  
- `L-1`: pot 1 p-lock value for this step  
- `L-2`: pot 2 p-lock value for this step  
- `L-3`: pot 3 p-lock value for this step  
- `L-4`: pot 4 p-lock value for this step  

Touching any potentiometer while in Note Select will set that p-lock value.

To reset/erase a p-lock - Highlight the parameter and turn the encoder to the left.

#### Step Events (TYPE):
"-" mute
"+" play
"1" reset to first step
">>" set parttern direction forward
"<<" set parttern direction reverse
"#?" jump to random step number
"?" set random event (of any of the previous events) for that one step

#### Trig conditions - A/B Ratios (COND):__
Play that step on the A cycle of B total cycles (or bars) of the pattern. Default is 1:1 (every time).
First number - play step on that cycle thru the pattern
Second number - resets the counter after that pattern cycle.

So 1:4 would play on the first cycle, not play on the next three and then reset (after the 4th cycle). 3:8 would play only the 3rd cycle and reset after the 8th.

#### Step Record

(SH-101-ish style note entry)

Holding F1 + a Pattern Key will enter Step Record Mode.

Enter notes from the keyboard and the sequence step will automatically advance to the next step. Change knob 1-4 positions to set a CC parameter lock for that step. Knob #5 (far right) will enter a velocity value for that step (there is no visual feedback when entering values from the knobs.

If you want to skip steps while entering notes, use the encoder button to select the STEP parameter and rotate to the step you want to change/update. While a step is selected, you can also record plocks/velocity for that step with the knobs without changing the note value. 

There are two pages of parameters in Step Record. First is the current octave (OCT), step number (STEP), note-value (NOTE), and pattern number (PTN). Second shows the step event parameters TYPE, PROB and COND as described above.

Press AUX to exit Step Record.

Keys/Commands:  
- Potentiometers 1-4 set a CC parameter lock  
- Potentiometers 5 sets a step velocity   
- AUX exit this sub-mode  

### Pattern Parameters

Long press Pattern Key to enter Pattern Params Mode.

Turning the encoder will show different pages of parameters.

A short-press on the encoder will select the active parameter for editing. Press the encoder repeatedly until nothing is selected to change pages.

Press AUX to exit Pattern Parameters.

Parameters:  

Page 1:  
- `PTN`: selected pattern  
- `LEN`: pattern length  
- `ROT`: rotation  
- `CH`: midi channel   

Page 2 (see Sequence Reset Automation below):  
- `START`: steart  
- `END`: end  
- `FREQ`: frequency  
- `PROB`: probability   

Page 3:  
- `RATE`: default note length (1/64th to whole note)    
- `SOLO`: MIDI solo   

Keys/Commands: 
- Step Keys set pattern length  
- F1 + pattern copies pattern  
- F2 + pattern pastes pattern (to other pattern slot)  
- F1 + F2 + pattern clears the pattern back to GM drum map default (and clears all plocks)  

(you can paste multiple times - paste buffer should stay the same until you copy again)

MIDI solo:
Set a pattern to MIDI solo and you can play the keyboard while that pattern is selected.

Note - once in MIDI solo, you will only be able to change the active pattern by using the encoder knob.

### Pattern Parameters: Sequence Reset Automation

This is located on the second page of pattern parameters

The goal of this "Sequence Reset Automation" feature was developed in the spirit of classic sequencers that can generate more complex sequences from simpler ones by setting any step in a given sequence to trigger a "reset" based on some constraint (i.e., number of cycles, probability, random).

Note - This behavior is a pattern-based solution. You can also execute step-based resets in Step Parameters.

Settings:

- START (Currently 0 - PatternLength-1): Use this to set the start step in current pattern to reset to for beginning a new cycle.

- END (Currently 0 - PatternLength-1): Use this to set the last step in current sequence to end/reset pattern cycles. This in essence is the step that will be used to trigger resets.

- FREQ of trigger reset (i.e., every X sequence cycle iterations)

- PROB of triggering reset (percentage)

NOTE: Setting STEP = 0 and PROB = 1 dictates random trigger steps which can lead to interesting results by jumping to random position/step.

---

## S2 - Sequencer 2 

Step sequencer - All patterns active.

Keys/Commands:   
 - AUX is Start/Stop  
 - Start/Stop sends MIDI transport control, and MIDI clock when running  
 - Pattern Key: Selects active pattern  
 - Encoder changes "page" for sequence parameters (with no parameter highlighted)  
 - Short-press encoder to highlight active parameter to edit  
 - F1 + AUX: Reset sequences to first/last step  
 - F2 + AUX: Reverse pattern direction  
 - F1 + Pattern Key: Enter __Step Record__    
 - F2 + Pattern Key: Mute that pattern  
 - F1 + Step Key: Enter __Note Select / Step Parameters__  
 - Long press a Step Key: Enter __Note Select / Step Parameters__   
 - Long press a Pattern Key: Enter __Pattern Parameters__  
 - AUX-key exits sub-modes  
 - Hold F1 + F2: first 4 "white keys" select "page" of the current pattern (depending on pattern length)  

Parameters:  
- `PTN`: selected pattern  
- `TRSP`: transpose (by semitones)  
- `SWNG`: swing  
- `BPM`: tempo   

- `SOLO`: set the current pattern to MIDI Solo  
- `LEN`: pattern length  
- `RATE`: default note length (1/64th to whole note)  
- `CV`: enable to send CV from this pattern   

In the sequencer modes, the default setup is a GM Drum Map with each pattern on a consecutive midi channel. So that's notes 36, 38, 37, 39, 42, 46, 49, 51 on channels 1-8.

---

## GR - Grids Sequencer 

An adaptation of the Mutable Instruments "Topographic drum sequencer" module.

See the original [Grids Manual](https://mutable-instruments.net/modules/grids/manual/) [or a video ?] for more.

Grids is a 4-channel/instrument MIDI trigger generator specialized in the creation and sculpting of rhythmic patterns. The "grid" refers to a map or library of preset drum patterns arranged in a 5x5 grid - which you can steer using X/Y controls.

Typical drum use would be Bass Drum, Snare, Closed HiHat, Open HiHat (The default note numbers are mapped to these in the GM drum map).

### Quick Keys
Grids has many quick keys. Pressing these keys quickly jumps the display to select a specific parameter which can be adjusted with the encoder.

#### Keys/Commands:   
 - AUX is sequencer Start/Stop  
 - Pots 1-4 control "event density" (probability) of 4 instruments - values are shown on display  
 - Pot 5 sets resolution (1/2, 1, 2)
 - Bottom row keys 1-8 are quick-keys for X/Y values - hold a key and turn encoder to change that instrument's X or Y value. You can hold multiple keys to change X/Y on multiple instruments at the same time  
 - LEDs on Keys 9-12 show trigger activity of the playing pattern  
 - Lighted Keys 13,14,16 are quick keys for ACNT/XAOS/BPM
 - Pattern keys (black keys) can load "snapshots" of density/x/y settings
 - F2 + Pattern saves a "snapshot" current state of that pattern. Patterns do not automatically save, this is a performance feature, allowing you to load a pattern, tweak it, then quickly load back to it's original state  

#### Instrument View Mode:
- F1 + Keys 1-4 jump to Instrument View. This shows the current pattern on that instrument (over 2 pages since patterns are 32 steps) and playhead. The LED render of the pattern will update to show each page while playing   
- Top row lighted keys(A#1, C#2, D#2, F#2) are quick-keys for ACNT/X/Y/XAOS
- First 4 keys of bottom row will not be specially lit since they are rendering the pattern, but will allow you to quickly select a different instrument  
- F2 is a quick key to jump to params page to set Note Number, MIDI Channel and BPM  
- Key 3(F#1) in Instrument View is a quick key for Midi Channel for the instrument  
- AUX-key exits Instrument View 

#### Midi Keyboard Mode:
- F1 plus bottom key 16 enters into the Midi Keyboard for sending CCs or playing over the top of the sequencer. Everything works the same as mode MI  
- Hold Aux and bottom key 16 to exit out of the Midi Keyboard mode  

### Menu Pages
Page 1 Event Densities:
- `DS 1`: event density - instrument 1  
- `DS 2`: event density - instrument 2  
- `DS 3`: event density - instrument 3  
- `DS 4`: event density - instrument 4  

Page 2:
- `NT 1`: note number - instrument 1  
- `NT 2`: note number - instrument 2  
- `NT 3`: note number - instrument 3  
- `NT 4`: note number - instrument 4  

Page 3:
- `ACNT`: accent amount (larger number is more variation) - applies to all instruments   
- `X `: X amount for selected instrument  
- `Y `: Y amount for selected instrument  
- `XAOS`: chaos amount - applies to all instruments  

Page 4 - Main Mode:
- `BPM`: tempo  

Page 4 - Instrument View Active:
- `NT -`: note number for active instrument  
- `M-CHAN`: midi chanel for active instrument  
- `BPM`: tempo

---

## EL - Euclidian Sequencer 

---

## OM - Organelle Mother 

Pretty much the same as MI, but with the following tweaks for Organelle Mother on norns/fates/raspberry-pi.

- AUX key sends CC 25 (127 on press, 0 on release)
- Encoder turn sends CC 28 (127 on CW, 0 on CCW)

---

## Screensaver 
After a default timeout (3 minutes), the display will be blanked and in MI Mode a "screensaver" animation will show on the LEDs. The rightmost pot (#5) can be turned to adjust the color. Touching any keys or any of the other pots will exit the screensaver.  

In S1/S2 the screen will blank, but there is no LED animation.

---

# Hardware 

## MIDI Switch for the mini TRS output jack connection

A hardware switch on the device will let you swap between Type-A and Type-B for the hardware MIDI TRS output jack.

Products That Use Type-A mini TRS Jack Connections
- ADDAC System products
- Arturia BeatStep (not to be confused with the BeatStep Pro)
- Dirtywave M8
- IK Multimedia products
- inMusic (Akai) products
- Korg products
- Line 6 products
- little Bits w5 MIDI module
- Make Noise 0-Coast

Products That Use Type-B mini TRS Jack Connections
- Arturia BeatStep Pro
- Faderfox products
- Novation products
- Polyend products
- 1010music Original Series 1 modules, Series 2 modules, Blackbox, MX4 and Euroshield

See [https://minimidi.world](https://minimidi.world) or [https://1010music.com/stereo-minijacks-midi-connections-compatibility-guide](https://1010music.com/stereo-minijacks-midi-connections-compatibility-guide) for more information

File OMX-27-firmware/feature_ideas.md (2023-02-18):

```
// Memory
// Clean slate no MidiFX
```
==== memory report ====
free: 29 Kb (45.9%)
stack: 1 Kb (1.6%)
heap: 2 Kb (2.9%)
``

// 25 Arps
```
==== memory report ====
free: 17 Kb (26.7%)
stack: 2 Kb (3.1%)
heap: 13 Kb (20.7%)
```

// 5 Arps
==== memory report ====
free: 26 Kb (40.3%)
stack: 2 Kb (3.1%)
heap: 13 Kb (20.7%)

```
==== memory report ====
free: 27 Kb (42.3%)
stack: 2 Kb (3.1%)
heap: 13 Kb (20.7%)
```

Bugs:
Arps don't work in MidiModeception

What's next:

- Chord Split Mode
- Midi Channels For Chords
- Hold Chord Turn set chord
- Chord Keyboard Display
- Default chords to something playable. 

Adafruit DMA neopixel 1.3.0
Adafruit NeoPixel 1.10.5

/Applications/Teensyduino.app/Contents/Java/hardware/tools/arm/bin/../lib/gcc/arm-none-eabi/5.4.1/../../../../arm-none-eabi/lib/armv7e-m/libc_nano.a(lib_a-signalr.o): In function `_kill_r':
Multiple libraries were found for "Adafruit_NeoPixel.h"
signalr.c:(.text._kill_r+0xe): undefined reference to `_kill'
 Used: /Users/quixotic7mini/Documents/Arduino/libraries/Adafruit_NeoPixel
/Applications/Teensyduino.app/Contents/Java/hardware/tools/arm/bin/../lib/gcc/arm-none-eabi/5.4.1/../../../../arm-none-eabi/lib/armv7e-m/libc_nano.a(lib_a-signalr.o): In function `_getpid_r':
 Not used: /Applications/Teensyduino.app/Contents/Java/hardware/teensy/avr/libraries/Adafruit_NeoPixel
Multiple libraries were found for "MIDI.h"
 Used: /Applications/Teensyduino.app/Contents/Java/hardware/teensy/avr/libraries/MIDI
signalr.c:(.text._getpid_r+0x0): undefined reference to `_getpid'
 Not used: /Users/quixotic7mini/Documents/Arduino/libraries/MIDI_Library
Multiple libraries were found for "Adafruit_SSD1306.h"
 Used: /Users/quixotic7mini/Documents/Arduino/libraries/Adafruit_SSD1306
collect2: error: ld returned 1 exit status
 Not used: /Users/quixotic7mini/Documents/Arduino/libraries/Adafruit_SSD1306_Wemos_Mini_OLED

Ideas:
Aux + Encoder to quickly switch modes. Modular setup in which You can combine sequencers, keyboards etc. 

"Was messing around with the Grids mode, and thought it would be nice if the four buttons that blink showing the different 'hits' could also act as mutes."

- DONE - Move MidiFX easily rather than cut/paste

- DONE -Quickkeys for arps. 

- DONE - Way to adjust midifx and play keyboard at same time. 

DONE - "feedback dialogs when selecting FXgroup or FX-off might be nice"

- Save / recall arp settings. 

- S1/S2 - Active step mode
    This would add an additional view in which steps can be turned on or off. 
    Steps that are off get ignored as if they did not exist. 
    Allows for fun performance manipulation of sequence without changing it. 

- S1/S2 pattern gate feature

- DONE - Arpegiator

- Add MidiFX to Seq, Chord, and Grids Modes

- Chord LED feedback

- Auto strum - Does Arp MidiFX Accomplish this? Maybe a arp submode? 

- Earthsea sequencer, add into midi and chord modes, simple records what you play then plays back in natural time or quantized. 

- Pot CC Presets
    These would be templates for quickly setting cc's to work with a specific synth like a mm2 or digitone. 

    Might be easier to just have multiple banks of pot presets. 

    A key shortcut for changing banks would be nice. 

- Try and make UI more consistent between modes

- Show something on screen to indicate you're in a submode and can press aux to exit. 

- Save single mode to sysex and load from sysex

- Add midi channels to chords

- Full manual chord note input

Waldorf Arp notes

The arpeggiator uses a so-called note list that can store up to 16 notes. 

Sort Order is set to Num Lo>Hi, the list is rearranged so that the lowest note is placed at the first position, the second lowest note at the next

Mode
	off
	on
	one shot
	hold
	
Step Len
	if Length is set to legato, all arpeggio notes are played without pauses between each step and Arp Steplen therefore has no effect.

Range
	octaves
	
Patterns

x-xxx-xxx-xxx-xx
x-x-x--xx-x-x--x
x-x-x-xxx-x-x-xx
x-xxx-x-x-xxx-x-
x-x-xx-xx-x-xx-x
xx-x-xx-xx-x-xx-
x-x-x-x-xx-x-x-x
x-x-x-xx-x-xx-x-
xxx-xxx-xxx-xxx-
xx-xx-xx-xx-xxx-
xx-xx-xx-xx-x-x-
xx-xx-x-xx-xx-x-
x-x-x-x-xx-x-xxx
x--x--x--x--x--x
x-x-x-x-x--xx-x-

Max Notes

Step length

Direction

	up
	down
	alt up
	alt down
	
Sort Order
	as played 
	reversed 
	Num Lo>Hi 
	Num Hi>Lo 
	Vel Lo>Hi 
	Vel Hi>Lo
	
Velocity
	randomize like grids?
	
Swing?

Same Note Overlap

Pattern Reset
	With Pattern Reset, you can decide if the note list is also restarted from the beginning when the rhythm pattern is reset.
	
	If Off is selected, the note list is not restarted, so that there is no synchronization between rhythm and note list. E.g., when you have a pattern where four steps are set and you play three notes, the pattern and the note list are repeated differently.
	
	If On is selected, the note list will be restarted as soon as the rhythm pattern is restarted.

Arpeggiator Edit Menu Step Data
	
Arp Accent 

Arp Glide

Arp Step

	• If * is selected (asterisk symbol), the Arpeggiator plays the step unaltered. The note list is advanced beforehand, except when you press a new chord.

	• If `off` is selected (empty space), the Arpeggiator plays nothing at this step position. When Length or Steplen is set to legato, the previous step that isn’t set to Off is still held to create the legato effect. The note list is not advanced.

	• If - is selected, the Arpeggiator plays the same note as it had to play in the previous step that was set to * or ˆ. With this setting, you can repeat a particular note of the note list several times. The note list is not advanced.

	• If < is selected, the Arpeggiator plays the very first note of the note list. This might be interesting if you want to only play the "root note" of a chord in a bass sound. The note list is not advanced.

	• If > is selected, the Arpeggiator plays the very last note of the note list. The note list is not advanced.

	• If <> is selected, the Arpeggiator plays a chord with two notes, the first and the last one of the note list. This means that you have to play at least two notes to hear the effect. Otherwise, you would hear only one note anyway. The note list is not advanced.

	• If (notes) is selected (notes symbol), the Arpeggiator plays a chord with all notes from the note list. This means that you have to play at least two notes to hear the effect. The note list is not advanced.

	• If ? is selected, the Arpeggiator plays a random note from the note list. This doesn’t mean that it creates any random note, it only uses one note of the note list at will. The note list is not advanced.

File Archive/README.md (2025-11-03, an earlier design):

# OMX-27 HARDWARE VERSIONS 1 and 2  

Mechanical key switch midi keyboard and sequencer. Based on Teensy 3.2 and Cherry MX RGB key switches.

Full kits and partial kits are [available for sale here](https://www.denki-oto.com/).

Dimensions:  313mm x 65mm  

## Firmware 

Kits are shipped with a blank Teensy. You will need to flash the firmware to the device.

### Load pre-compiled firmware w/ TyUpdater

Download the correct OMX-27 firmware "hex" file from the [GitHub Releases page](https://github.com/okyeron/OMX-27/releases) page or the Firmware-Hexes directory in this repo.

NOTE - 2023 boards with Teensy 4.0 have a different firmware and will have a "T4" suffix.

Get TyTools [from GitHub here](https://github.com/Koromix/tytools/releases). More info here (https://koromix.dev/tytools).

Copy TyUploader to your machine and open it. Be sure your OMX-27 is plugged in. It should show up in the TyUpdater application.

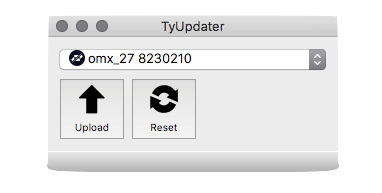
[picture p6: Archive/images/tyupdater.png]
tyupdater


Click the Upload button and select the firmware hex file you want to upload. This should upload the firmware and the OMX-27 should reboot. That's it.

### Teensyduino (compile yourself)

Install Teensyduino from the [PJRC website](https://www.pjrc.com/teensy/teensyduino.html).

In Teensyduino Library Manager - check to be sure these are installed and on the most recent versions.

__Libraries:__  
Adafruit_Keypad  
Adafruit_NeoPixel  
Adafruit_SSD1306  
Adafruit_GFX_Library  
U8g2_for_Adafruit_GFX  
Adafruit_FRAM_I2C  
Adafruit_MCP4725



Also check to be sure MIDI Library (by Francois Best / fortyseveneffects) is updated to 5.02 (I believe this is installed by default with Teensyduino)

Set the following for the Teensy under the Tools menu:

__Board:  Teensy 3.2/3.1__  or __Board:  Teensy 4.0__  
__USB Type: MIDI__  
__CPU Speed: 120 MHz (overclock)__  

Open the sketch at `OMX-27-firmware/OMX-27-firmware.ino`, click verify to ensure it all compiles and upload to flash the firmware to the hardware, pushing the button on the Teensy first.

### PlatformIO / VSCode (optional)

Ensure Homebrew in installed. [Instructions](https://brew.sh/)  
Install PlatformIO CLI tools. [Detailed Instructions](https://platformio.org/install/cli)

```sh
# Mac OSX
brew install platformio

# check out the project
git checkout https://github.com/okyeron/OMX-27.git

# go to the project directory
cd OMX-27

# compile the project (this may take a while the first time)
pio run

# upload to hardware (don't forget to push button on Teensy)
pio run -t upload

# use serial monitor for debugging
pio device monitor

# clear FRAM/EEPROM
pio run -t clear-storage
```

(optional) Install PlatformIO IDE VSCode extension. [Instructions](https://platformio.org/platformio-ide)

Install EditorConfig extension for your text editor. [Instructions](https://editorconfig.org/)
 
Note: when making changes using the PlatformIO toolchain, please ensure the sketch still builds on Teensyduino before opening a PR.

## BOM

[Bill of Materials](<build/BOM.md>)

## Build

[Build Guide](<build/Build-Kit.md>)

## Docs

[Documentation](<Docs.md>)

## Web Configurator

[Online Configurator](https://okyeron.github.io/OMX-27/webconfig/index.html)

## FAQ

Q: What key switches are recommended?  
A: Any RGB switches with a Cherry MX footprint can be used - I'm using Cherry MX RGB and these are linked in the [BOM](<build/BOM.md>). Different varieties are available (Red, Brown, etc.)

Q: Can I use other key switches?  
A: Yes - as long as they have the same footprint as Cherry MX switches and a window/opening for the LED to shine through. Low profile keys like the Cherry Low Profile or Kailh Choc switches have a different footprint and will not work.

Q: What about recommended Keycaps?  
A: Also listed in the [BOM](<build/BOM.md>). You want an MX stem cap, with translucency or a window for the LED to shine through. DSA profile caps work well.

Q: Does this project require soldering?  
A: Yes. Thru-hole soldering is required along with some easy SMD (LEDs and jacks).

Q: What's with these LEDs?   
A: This project uses SK6812-MINI-E reverse mount LEDs. They are somewhat hard to find, so I'll try to offer them included with kits. They are easy to solder, even if you've not done much SMD.

Q: Can I get the Gerbers or order the pcbs myself?  
A: No. Not open source at this time.

Q: Can I get some of those windowed keycaps you're using?  
A: Yes (send me an email).

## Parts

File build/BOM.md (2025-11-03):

# OMX-27 v3 BOM

OMX-27 v3 comes with SMD parts pre-assembled. Some alternate/replacement parts are listed here for reference 

| Mouser  | QTY | Part | Value | Package |
|-----|:--:|-----|-----|-----|
|[688-RK09K1130A5R](http://www.mouser.com/Search/ProductDetail.aspx?R=688-RK09K1130A5R)|5|VR1-VR4,VR6|10K linear |9MM_SNAP-IN_POT*|
|[652-PEC11R-4015F-S24](http://www.mouser.com/Search/ProductDetail.aspx?R=652-PEC11R-4015F-S24)|1|VR5|PEC11 + SWITCH|Encoder with Switch|
|[540-MX3A-L1NA](http://www.mouser.com/Search/ProductDetail.aspx?R=540-MX3A-L1NA)|27|K1-K27|CHERRY-MX|CHERRY-MX RGB Silent Red \***|
| (alt) |27|K1-K27|Kailh Choc V1|Kailh Choc V1 Red \***|
|  |1| |OLED - 128x32 I2C display| \**See below|

\* POTS - I used trimmer type pots because they're a little more low profile. But you can use alpha pots (10K linear) or whatever you have around.

\** OLED - 128x32 I2C display (SSD1306) with pin order ( GND, VCC, SCL, SDA )  
example search terms:  "0.91" 128x32 IIC I2C White OLED LCD Display DIY Module For Arduino"  

---
### Optional battery

A lipo battery can be added. 

[This battery from tinycircuits is recommended](https://tinycircuits.com/products/lithium-ion-polymer-battery-3-7v-290mah). Also available from [Mouser](https://www.mouser.com/ProductDetail/TinyCircuits/ASR00007) or [Digikey](https://www.digikey.com/en/products/detail/tinycircuits/ASR00007/7404517)

The battery plug on the PCB is a JST SH connector (2 pin, 1.0 mm pitch) or you can solder the battery wires directly to the PCB. Please note the PCB markings for polarity.

A 3D printable battery box is also available. [Model link]

---
### \*** Key switches: 

Cherry MX or Kailh Choc V1 switches can be used for the build. Denki-oto kits default to Cherry MX RGB Silent Red or Kailh Choc V1 Red switches and will have a different keyplate and spacer setup depending on the switch choice.

Switches can be best obtained from various online keyboard shops like [mechanicalkeyboards.com](https://mechanicalkeyboards.com/).  

### Keycaps - Choc: 

Choc Kits come with FK MBK "Dot Glow" keycaps. 

Nice blank Choc keycaps with shine-thru are hard to find. A translucent white MBK keycap made with POM material looks great with backlighting.  Search online keyboard shops in your country for "MBK POM"

FK offers a [Custom Service](https://fkcaps.com/custom/) if you wanted to create your own. 

---

### Keycaps - MX: 

Any MX-compatible keycaps will work, but you'll want one designed for backlighting, such as a "backlit two-shot", "translucent", "shine-through", or "windowed".  

I like the DSA profile caps for this application.

I have the DSA windowed keycaps in various colors available for sale in sets [on my shop](https://www.denki-oto.com/store/p62/OMX-27_Keycap_sets.html#/).

Signature Plastics sells the keycap I use in a Light or Dark grey - [DSA "Dolch" Keyset (Two Shot) "Windowed" Keys](https://spkeyboards.com/products/dsa-dolch) (choose the __LED Keys__ option).  
These come in a pack of 4 keycaps. You will need 7 packs (@ ~$60 total).  

[Flashquark Translucent DSA Keycaps](https://flashquark.com/product/translucent-dsa-keycaps/) (in Black, White, Clear, Blue, Red) - __50 per pack__. ($12.99-$15.99 per pack)

[Blue Hat 1U DSA Blank Printed Keycaps PBT Keycaps](https://www.amazon.com/gp/product/B07SJKMNWC) (Gray Translucent) - __37 per pack__. ($15.55 per pack and prime shipping)  
(about the same as the black ones from Flashquark above)

[Maxkeyboard Black Translucent MX Blank](https://www.maxkeyboard.com/black-translucent-cherry-mx-blank-keycap-set-for-esc-w-a-s-d-or-e-s-d-f-and-arrow-keys.html) (pack of 9). ($21 for 3 packs)

---

### Knobs

So many opinions about knobs. 

Micro knobs (Befaco Style) can be found at these places:  
https://www.thonk.co.uk/shop/tall-trimmer-toppers/   
https://www.thonk.co.uk/shop/micro-knobs/  
https://www.thonk.co.uk/shop/tall-trimmer-toppers/

---

### USB Cable: 

I recommend using a right angle extension cable [like this one from Amazon](https://www.amazon.com/gp/product/B015PSU5F6/)  

Be sure you have a good, known working, __USB DATA CABLE__ and not just a charging cable.

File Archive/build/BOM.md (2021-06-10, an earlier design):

# OMX-27 BOM

| Mouser  | QTY | Part | Value | Package |
|-----|:--:|-----|-----|-----|
|[RC0805FR-1047RL](http://www.mouser.com/Search/ProductDetail.aspx?R=RC0805FR-1047RL)|2|R7 R8|47R|0805|
|[603-RC0805FR-0710KL](http://www.mouser.com/Search/ProductDetail.aspx?R=603-RC0805FR-0710KL)|2|R1 R2|10K|0805|
|[652-CR0805-FX2202ELF](http://www.mouser.com/Search/ProductDetail.aspx?R=652-CR0805-FX2202ELF)|2|R4 R6|22K|0805|
|[RC0805FR-1056KL](http://www.mouser.com/Search/ProductDetail.aspx?R=RC0805FR-1056KL)|2|R3 R5|56K|0805|
|[80-C0805C104J5RACLR](http://www.mouser.com/Search/ProductDetail.aspx?R=80-C0805C104J5RACLR)|28|C1-C29|100nF|0805|
|[710-885382207006](http://www.mouser.com/Search/ProductDetail.aspx?R=710-885382207006)|2|C30, C31|10nF|0805|
|[621-1N4148W-F](http://www.mouser.com/Search/ProductDetail.aspx?R=621-1N4148W-F)|27|D1-D27|1N4148 Diode|SOD-123|
|[SJ-3523-SMT-TR](http://www.mouser.com/Search/ProductDetail.aspx?R=SJ-3523-SMT-TR)|1|J1|SJ-3523-SMT-TR|3.5 mm jack stereo|
|[490-MJ-3523-SMT-TR](http://www.mouser.com/Search/ProductDetail.aspx?R=490-MJ-3523-SMT-TR)|2|J2,J3|MJ-3523-SMT|3.5 mm jack mono|
|[540-MX3A-L1NA](http://www.mouser.com/Search/ProductDetail.aspx?R=540-MX3A-L1NA)|27|K1-K27|CHERRY-MX|CHERRY-MX RGB Silent Red \*|
|[595-TLV9062IDR](http://www.mouser.com/Search/ProductDetail.aspx?R=595-TLV9062IDR)|1|U1|SOIC127P600X175-8N|TLV9062IDR|
|[AYZ0202AGRLC](http://www.mouser.com/Search/ProductDetail.aspx?R=AYZ0202AGRLC)|1|S1|DPDT Switch|SWITCH-DPDT-SMD-AYZ0202|
|[688-RK09K1130A5R](http://www.mouser.com/Search/ProductDetail.aspx?R=688-RK09K1130A5R)|5|VR1-VR4,VR6|10K|9MM_SNAP-IN_POT*|
|[652-PEC11R-4015F-S24](http://www.mouser.com/Search/ProductDetail.aspx?R=652-PEC11R-4015F-S24)|1|VR5|PEC11+SWITCH|Encoder with Switch|
| [aliexpress](https://www.aliexpress.com/item/4000475685852.html?spm=a2g0s.9042311.0.0.601b4c4dcyhOZn) / [ebay](https://www.ebay.com/itm/100-2000pcs-SK6812-MINI-E-LED-CHIP-SK6812-3228-4pin-dream-color-LEDS-DC5V/224140435419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)|27|LED1-LED27|SK6812MINIE|SK6812-MINI-E|
| [PJRC Store](https://www.pjrc.com/store/teensy32.html) |1| |TEENSY 3.2||
|  |1| |OLED - 128x32 I2C display| \**See below|
|  | | |header pins| \***See below|

\* POTS - I used trimmer type pots because they're a little more low profile. But you can use alpha pots or whatever you have around.

\** OLED - 128x32 I2C display (SSD1306) with pin order ( GND, VCC, SCL, SDA )  
example from eBay:  
"0.91" 128x32 IIC I2C White OLED LCD Display DIY Module For Arduino"  
https://www.ebay.com/itm/293660021494  

\*** Headers:
1X04 (oled) 
1x14 x 2 (teensy) 
1x01 (teensy dac pin) 

TIP: Get 1x40 breakaway headers and cut what you need.  

[Mouser Cart (work in progress)](https://www.mouser.com/ProjectManager/ProjectDetail.aspx?AccessID=13c0107d30) - __DOES NOT include Teensy, OLED, LEDs or headers__

Mounting Hardware is NOT LISTED

Knobs are up to you.

---
### \* Key switches: 

Any of the Cherry MX RGB switches will work. Red/SilentRed/Blue/Brown/Black/SpeedSilver.  
Red is linear (45g). Blue is clicky & tactile (50g). Brown is tactile (45g). Black is similar to Red but 60g actuation force. SpeedSilver (shorter key travel for gamers) are linear and __Expensive__( 45g)

Cherry MX RGB part numbers:  

| name  | part num | type | actuation |
|-----|----|-----|----|
|SilentRed |[MX3A-L1NA](https://www.mouser.com/ProductDetail/CHERRY/MX3A-L1NA/?qs=F5EMLAvA7IA6PAS7ry3I9w%3D%3D)| linear | (45g) |
|Red	|MX1A-L1NA| linear | (45g) |
|SilentBlack |[MX3A-11NA](https://www.mouser.com/ProductDetail/CHERRY/MX3A-11NA/?qs=F5EMLAvA7ICizK1XKjfN9w%3D%3D)| linear | (60g) |
|Black	|MX1A-11NA| linear | (60g) |
|Brown	|[MX1A-G1NA](https://www.mouser.com/ProductDetail/540-MX1A-G1NA/)| tactile | (45g) |
|Blue	|MX1A-E1NA| clicky & tactile | (50g) |
|Silver	|[MX1A-51NA](https://www.mouser.com/ProductDetail/CHERRY/MX1A-51NA/?qs=F5EMLAvA7IB4ByA0zXdBkg%3D%3D)| linear | (45g) |

Reference: https://www.mouser.com/pdfDocs/cherrykeyswitches.pdf

### Keycaps: 

Any MX-compatible keycaps will work, but you'll want one designed for backlighting, such as a "backlit two-shot", "translucent", "shine-through", or "windowed".  

I like the DSA profile caps for this application.

[DSA "Dolch" Keyset (Two Shot) "Windowed" Keys](https://pimpmykeyboard.com/dsa-dolch-keyset-two-shot/) (choose the __LED Kit__ option).  
These come in a pack of 4 keycaps. You will need 7 packs (@ ~$70 total).  

[Flashquark Translucent DSA Keycaps](https://flashquark.com/product/translucent-dsa-keycaps/) (in Black, White, Clear, Blue, Red) - __50 per pack__. ($12.99-$15.99 per pack)

[Blue Hat 1U DSA Blank Printed Keycaps PBT Keycaps](https://www.amazon.com/gp/product/B07SJKMNWC) (Gray Translucent) - __37 per pack__. ($15.55 per pack and prime shipping)  
(about the same as the black ones from Flashquark above)

[Maxkeyboard Black Translucent MX Blank](https://www.maxkeyboard.com/black-translucent-cherry-mx-blank-keycap-set-for-esc-w-a-s-d-or-e-s-d-f-and-arrow-keys.html) (pack of 9). ($21 for 3 packs)

### Knobs

So many opinions about knobs. 

Micro knobs (Befaco Style) can be found at these places:  
https://www.thonk.co.uk/shop/tall-trimmer-toppers/   
https://www.thonk.co.uk/shop/micro-knobs/  
https://www.thonk.co.uk/shop/tall-trimmer-toppers/

### USB Cable: 

I recommend using a right angle extension cable [like this one from Amazon](https://www.amazon.com/gp/product/B015PSU5F6/)  

Be sure you have a good, known working, USB DATA CABLE and not just a charging cable.

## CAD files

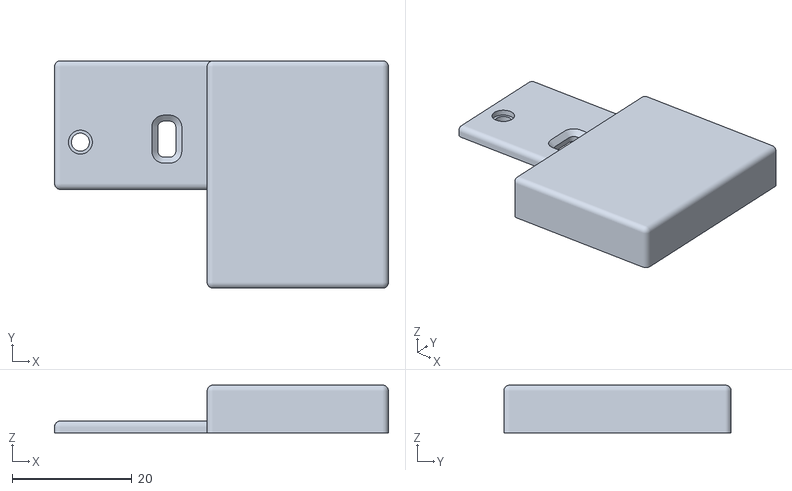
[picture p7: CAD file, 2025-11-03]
Battery-box/omx-27_battery_box_1b.stl
55.8 x 38.0 x 8.00

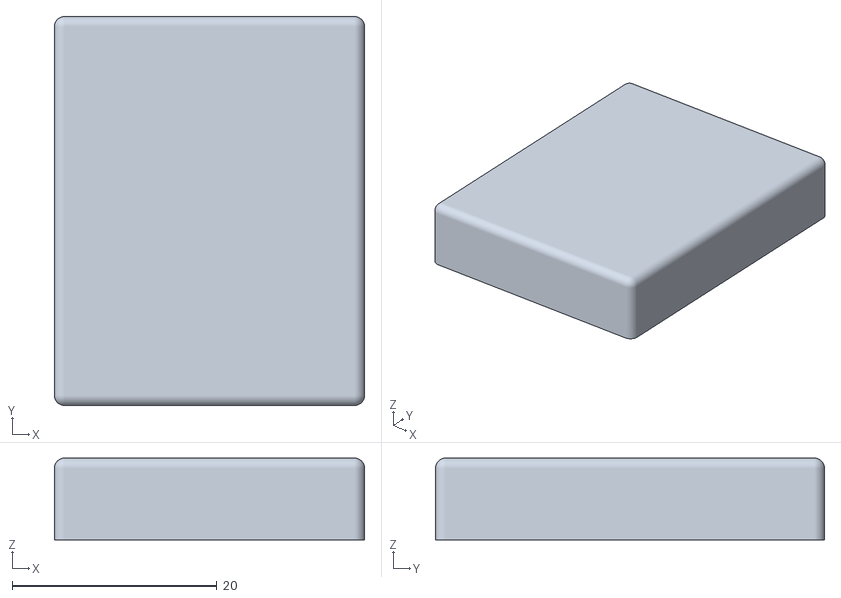
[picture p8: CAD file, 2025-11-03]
Battery-box/omx-27_battery_box_1a.stl
30.3 x 38.0 x 8.00

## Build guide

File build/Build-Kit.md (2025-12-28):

# OMX-27 version 3

### PLEASE READ THIS ENTIRE GUIDE FIRST

##  Before you start

### Notes / Reminders

- Kit PCBs have been flashed and tested. They should be fully functional. The microprocessor, LEDs, OLED, etc. are already assembled. Thru-hole soldering is required for the pots, encoder and switches.

- For the Cherry MX kit - the keyswitches are snapped into the keyplate first (before soldering them). 

- For the Choc kits - the keyplate fits over the switches and it can be attached later.  

- Don't forget to put the spacer layer(s) in-between the main PCB and the keyplate before you solder all the switches.

### Soldering Tips

I work with a fine point or chisel tip on my iron at 380C-400C. With this setup I typically hold the iron on a pad for about 2 seconds and then apply a bit of solder and then hold the iron there for anything 2-3 seconds. You want to watch for the solder to flow around the joint, but not to hold the iron there forever.

See [Adafruit's guide to excellent soldering](https://learn.adafruit.com/adafruit-guide-excellent-soldering) for lots of good tips and tricks.

# Build Video

[Build/assembly](https://www.youtube.com/watch?v=Nn4loqqdX9o) 

---

# Kit Build Instructions

The microprocessor, LEDs, OLED, etc. are already assembled. Thru-hole soldering is required for the pots, encoder and switches. 

## POTS AND ENCODER

Snap pots and encoders into place and solder.

You may need to gently squeeze the snap-in mounting pins together a tiny bit to get the pots to snap into place.

Note - You don't need loads of solder on the lugs - just enough to keep them in place.

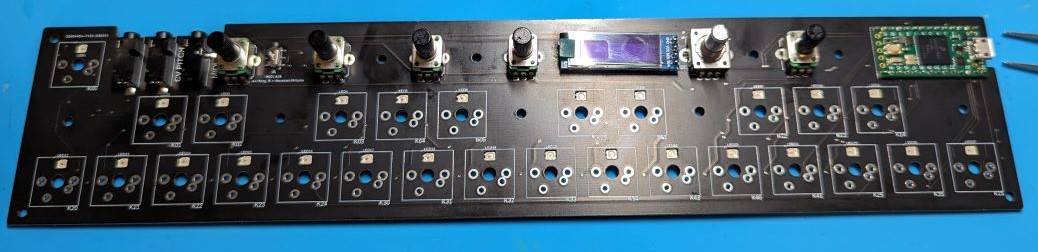
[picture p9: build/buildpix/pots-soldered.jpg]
pots soldered


---

## STOP HERE AND TEST

At this point you can do a quick test.  

Plug into USB power and the OLED should display the startup routine. Then the LEDs will light up in a "rainbow" pattern and the main screen will show on the display. Turn the encoder to the right to get to the second page and you can test each of the pots - which should show the CC number and value on the display.  

If you get random values for the CCs, you may need to check and reflow the solder on the potentiometer pins.

If the display does not light up or you don't see LEDs light up when you connect to USB power, double check the Power Switch on the right edge of the device. The "On" position is towards the USB port.

---

# Continue building

## Case Parts

__Carefully__ remove the paper backing from the acrylic base plate and set it aside.

If the brown paper backing material does not come off easily, you can often rub your finger along the surface to get the paper backing to "roll up" a bit 

Cherry MX kits have __two__ foam spacer layers. The Choc kit has __one__ foam spacer layer.

For the Cherry MX kit, you will need the PCB "keyplate" for the next step. For the Choc kit, set the keyplate aside until later.

## Key Switch Prep (MX Kit)

Check the orientation of the switches. The pins go towards the bottom-half and the LED window is at the top.  

Snap all the key-switches into the keyplate (from the top - keyplate top has text labels for the MIDI anc CV jacks). 

The switches may be a tight fit in the keyplate. Be sure they are snapped all the way into place.

Set the two black foam spacer layers on the main PCB and align it around the various components. Then set the keyplate with switches into place to be sure all the pins line up and everything is nice and flat. 

Inspect from the bottom that you have 2 pins sticking out for each switch. You may need to gently bend key-switch pins into place if they got slightly bent in transport.

Use the three of included case screws/nuts to fix everything together for soldering. I suggest using the holes down the middle of the case. This will ensure the key switches are held in place for soldering and that everything will remain flat.

## Key Switch Prep (Choc Kit)

Check the orientation of the switches. The pins go towards the bottom-half and the LED window at the top.  

Insert all the key-switches into the PCB.

## Switch Soldering

I suggest going thru and tack-soldering one pin for each switch (just enough solder to hold it in place). Then for each switch - use your not-soldering-iron hand to fully press each switch with your thumb on the bottom side, and re-heat the tacked solder joint. In some cases the swtich might not have been fully inserted and it will snap into place when you do this.

After all the switches look nice, make another pass and solder the other pin for each switch. Make a third pass and add a touch of solder if needed to the pins you tacked in place earlier.

## Assembly

Remove the screws/nuts if you used them earlier and then reassemble with the bottom plate.

The nuts fit into the captive cutouts on the bottom plate.

There are three longer screws which are used for the USB protector.

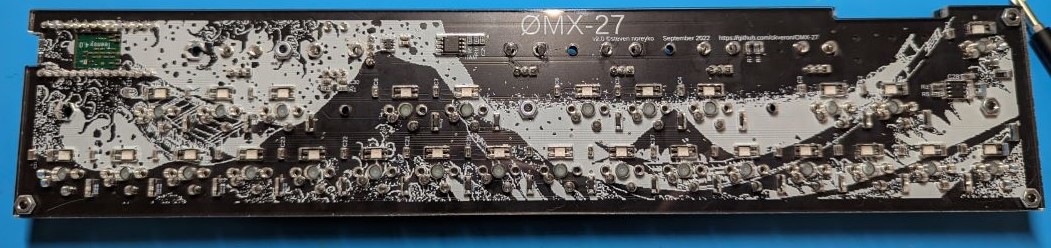
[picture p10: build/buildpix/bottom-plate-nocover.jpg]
bottom plate


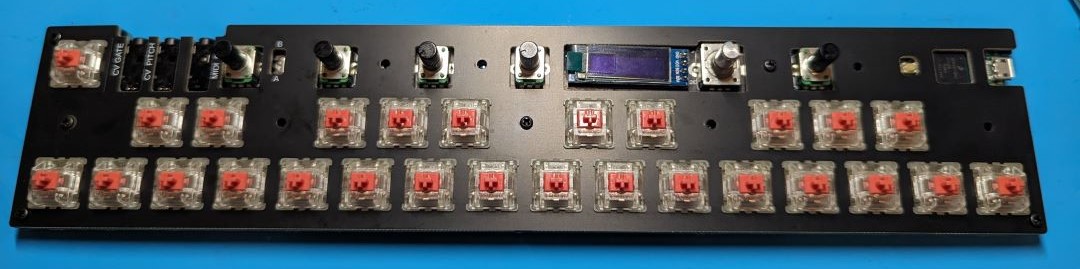
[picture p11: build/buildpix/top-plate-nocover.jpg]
top plate


### USB Protector/Cover

Add the cover plate with the three remaining (longer) screws/nuts.

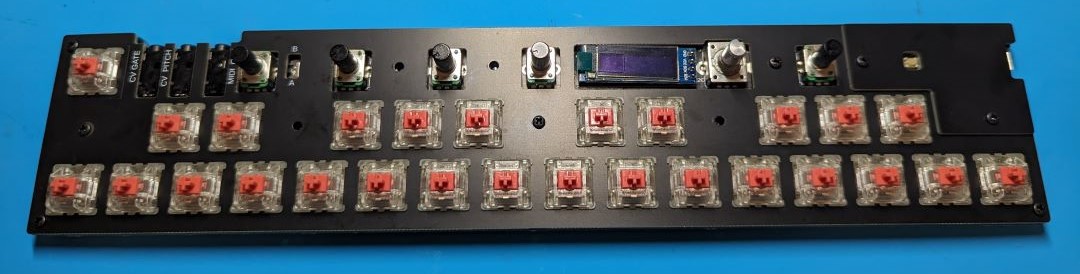
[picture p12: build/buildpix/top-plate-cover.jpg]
top plate cover


### Knobs

Push the knobs onto the pots, make sure the marking on the knob aligns with the marking on the pot. Be carefull not to press the knobs on too hard if you want to change them later. They can be difficult to remove if pressed on too hard.

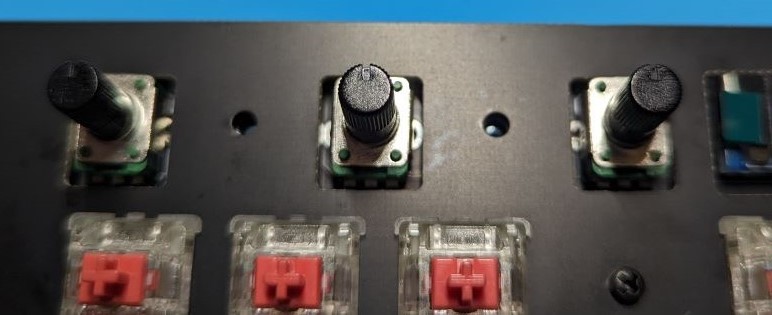
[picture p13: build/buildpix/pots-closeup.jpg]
pots closeup


### Keycaps

Then install the keycaps with the window on the top for the LEDs.

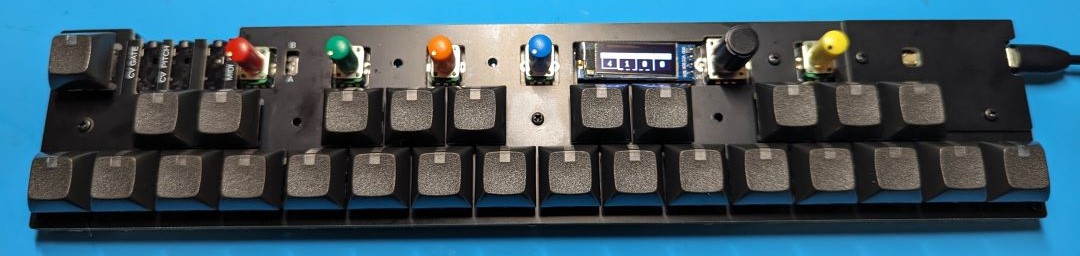
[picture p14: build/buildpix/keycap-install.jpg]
keycap-install


## MIDI test

You can use the [browser_test](../browser_test/index.html) script to show USB-MIDI input to your computer. Then you can check to be sure the pots are sending CCs and that you get MIDI note-ons/note-offs when you test each keyswitch's pads. Be sure you have the `oct` (octave) set to 4 on the display (change with encoder knob).

Also test the Hardware MIDI OUT 1/8" jack (with an appropriate adapter if needed) and a synth of your choice. Check the MIDI A/B switch position for your particular setup (try both to be sure you have the right one).

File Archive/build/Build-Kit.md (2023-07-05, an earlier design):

# OMX-27

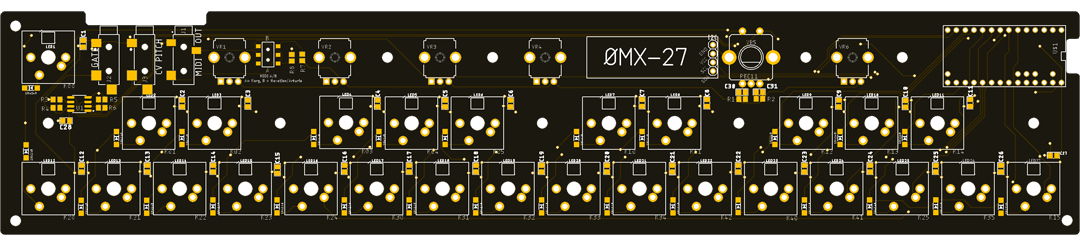
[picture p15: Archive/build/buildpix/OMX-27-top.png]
Top
  
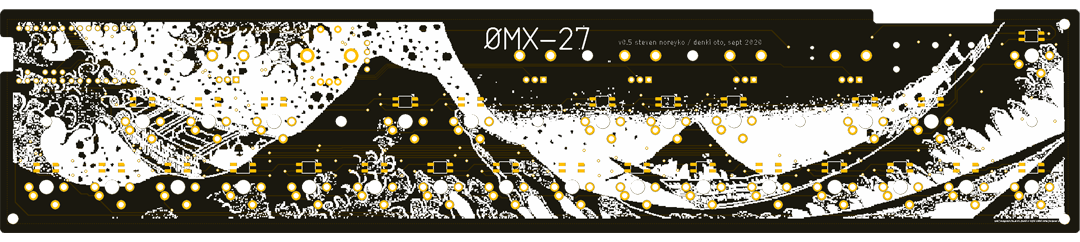
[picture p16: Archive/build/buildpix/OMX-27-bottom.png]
Bottom
  

# Before you start

## READ THIS ENTIRE GUIDE FIRST

Also - see these __Build Videos:__

[Part 1 - LEDs](https://youtu.be/UFm8Dfpjoz4)   
[Part 2 - Teensy](https://youtu.be/W-rJqxFzsLw) (Not yet updated for Teensy 4.0)      
[Part 3- Pots and Testing](https://youtu.be/rtUBW4xm9us)   
[Part 4 - Switches and Assembly](https://youtu.be/jUWWuaacoz4)   

The key-switches are going to be the VERY LAST thing you solder. __After you solder the switches in, everything on the inside is going to be inaccessible.__

Ideally you want to be able to test all the LEDs, the OLED, and the pots/encoder before putting the switches on.

I'd also suggest testing each switch connection with a piece of wire or tweezers so you can confirm the diodes/LEDs/caps are all soldered correctly.

Follow the order of operations here to make your life easier. __NOTE - the keyswitches are absolutely the last thing you solder.__ Make sure everything else looks good before you do the switches.

Also important - Keyswitches are snapped into the keyplate first (before soldering them). 

Don't forget to put the spacer layer in-between the main PCB and the keyplate before you solder all the switches.

### Soldering Tips

I work with a fine point tip on my iron at 400C. With this setup I typically hold the iron on a pad for about 2 seconds and then apply a bit of solder and then hold the iron there for anything 2-3 seconds. You want to watch for the solder to flow around the joint, but not to hold the iron there forever.

See [Adafruit's guide to excellent soldering](https://learn.adafruit.com/adafruit-guide-excellent-soldering) for lots of good tips and tricks.

Nice to have tools:
 - flush diagonal cutters  
 - tweezers  

---

# Build from Kit

### LEDs

The LEDs are __Reverse Mount__ and are soldered to the back-side of the PCB with the LED facing towards the top of the PCB. When looking at the back of the PCB as in the picture, the GND leg is the top right pad for each one (marked with a red triangle in the picture below). The LED itself has a "notched" leg for GND.

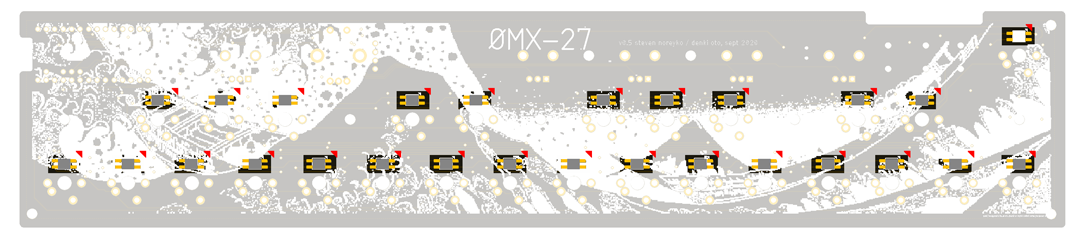
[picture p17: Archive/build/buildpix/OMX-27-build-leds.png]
led board locations


Set each LED into position (tweezers are handy for this) and __then double check the ground pin is in the right position__.  

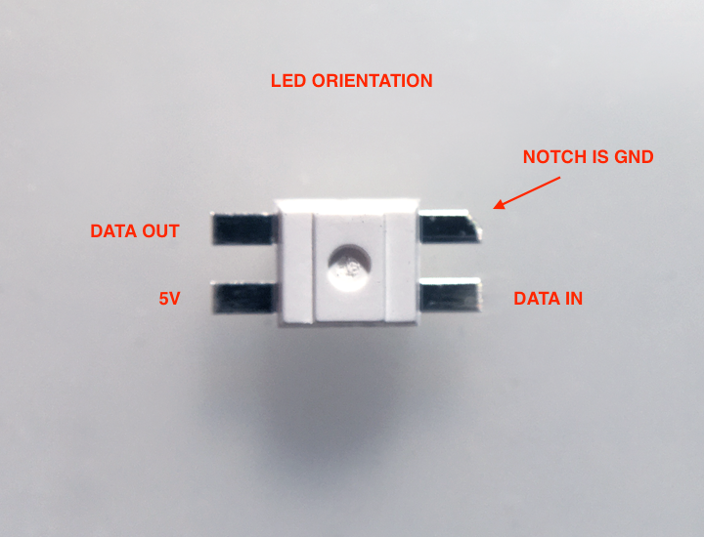
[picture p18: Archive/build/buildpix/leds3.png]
LEDs

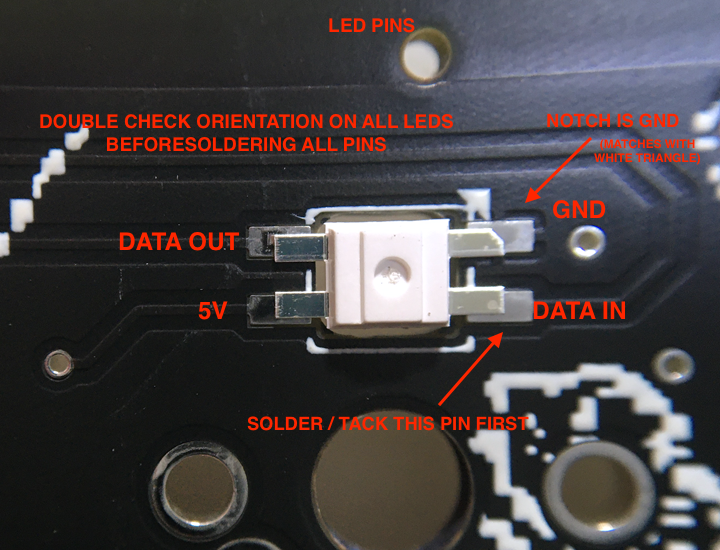
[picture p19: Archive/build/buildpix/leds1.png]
LEDs

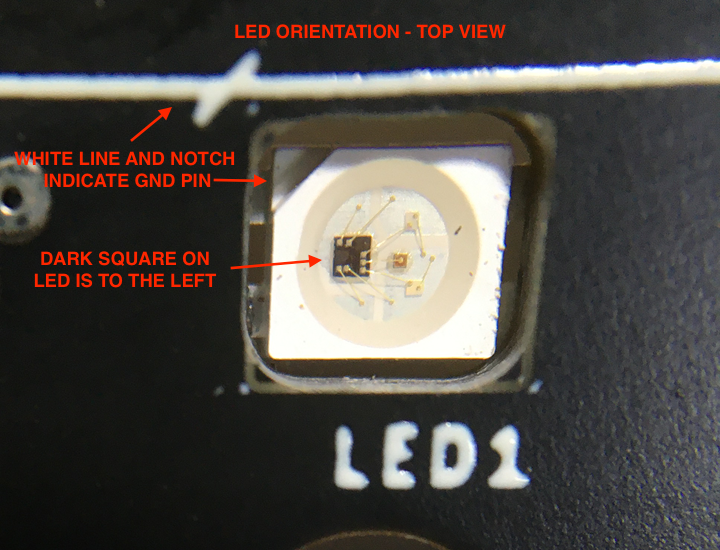
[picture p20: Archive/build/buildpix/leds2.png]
LEDs


Solder/tack the bottom right corner pad of each LED to hold each one in place. Then check the orientation of each LED to be sure they're nice and square in the hole. If not, warm up the solder there and reposition as needed.

After you're happy with the LEDs being in the proper positions - solder the rest of the pads.

### TEENSY

For the keyplate to fit properly, the Teensy MUST be flush-mounted to the top of the main PCB.

(Teensy 3.2 and PCB v1.5 only) An insulating kapton spacer is included with your kit . Use this between the bottom of the teensy and the main PCB to reduce the chances of unintended shorts.

See below for Teensy 4.0 instructions (2023 v2.0 boards).  

__Teensy 3.2 jig__  

Use the included acrylic jig to set up your Teensy like the following for soldering.  

Short side of the headers goes down to the jig and the long side up.  

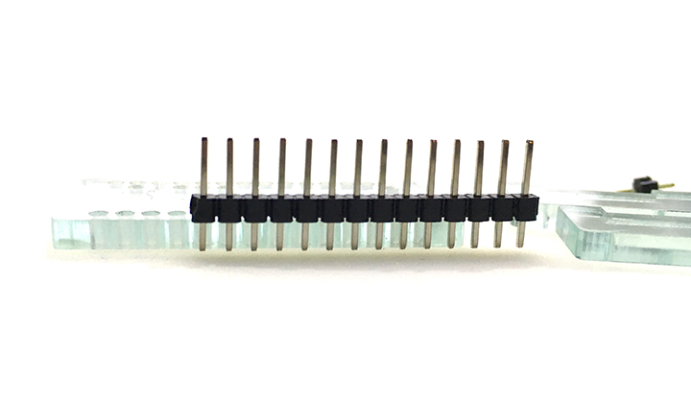
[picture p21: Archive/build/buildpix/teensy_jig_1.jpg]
teensy 3.2 jig


Add a 1x3 and 1x1 in the appropriate places. The 1x1 directly next to the 1x3 is not connected to anything so you can solder that or not (your choice).  

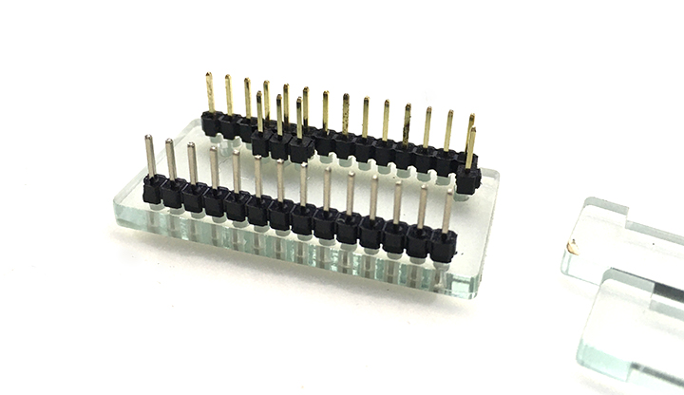
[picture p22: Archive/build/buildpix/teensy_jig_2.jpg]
teensy 3.2 jig

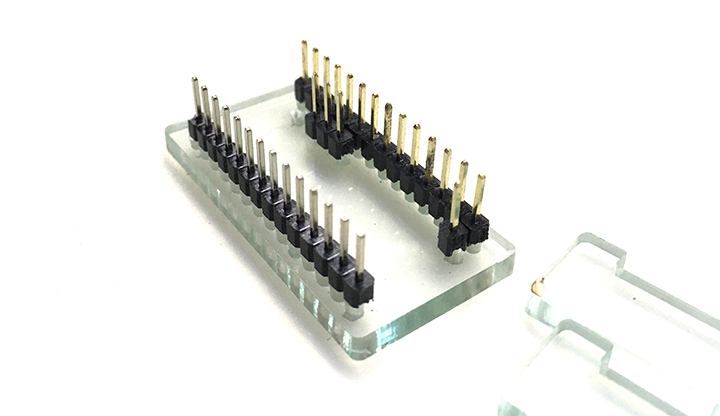
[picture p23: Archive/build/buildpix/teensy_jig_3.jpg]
teensy 3.2 jig


Add the two spacers  (maybe even tape those two together so they don't wiggle around.

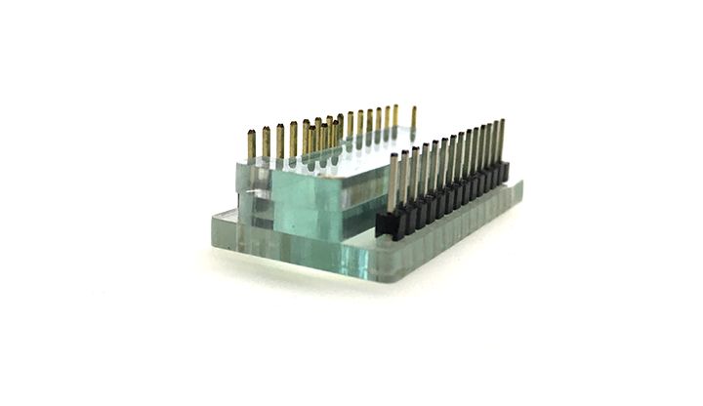
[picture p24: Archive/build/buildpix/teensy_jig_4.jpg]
teensy 3.2 jig


Drop the Teensy into place. There should just be a small amount of header sticking up from the Teensy at this point.  

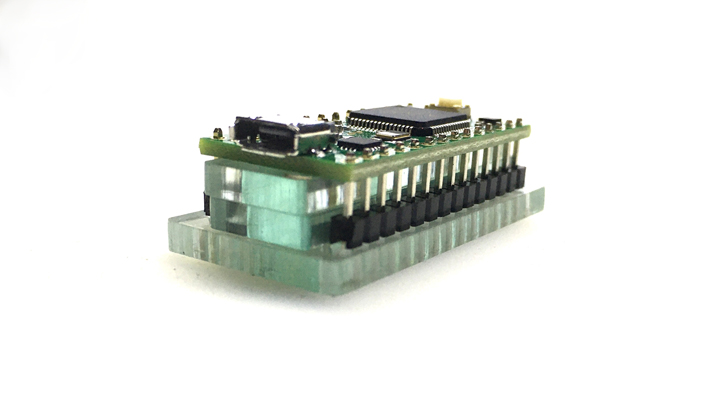
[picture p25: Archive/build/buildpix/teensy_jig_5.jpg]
teensy 3.2 jig


DON'T SOLDER A HEADER TO THE VUSB PIN - it's not used. This is the 1x1 pin/hole right next to the USB jack on the Teensy (on the inside row).

__Teensy 4.0 jig__  

The Teensy 4.0 version (board v2.0) only uses the 2 outer rows of pins. (4 less pins to solder!)

Note the plastic parts of the jig have an etched out area - this is to allow space for the components on the underside of the Teensy 4.0.  

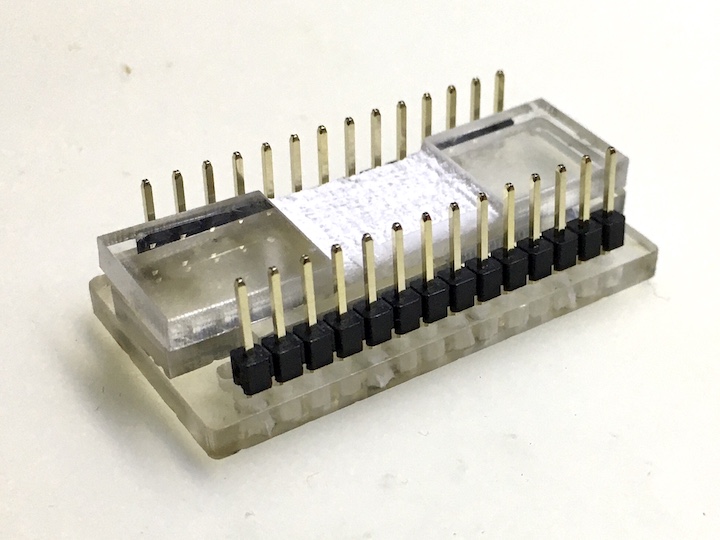
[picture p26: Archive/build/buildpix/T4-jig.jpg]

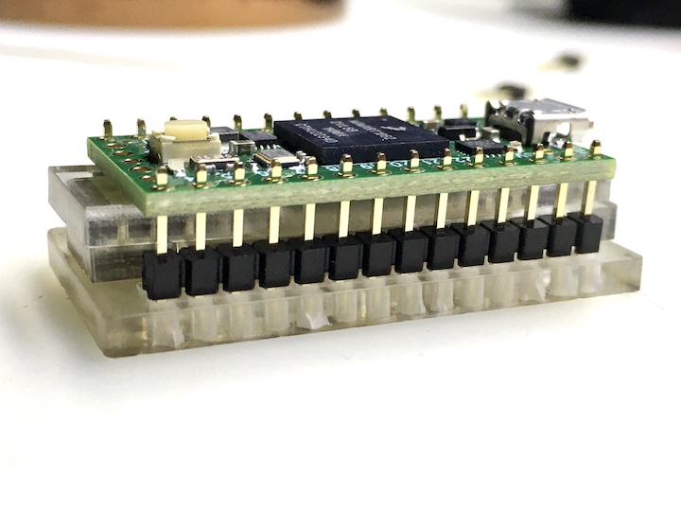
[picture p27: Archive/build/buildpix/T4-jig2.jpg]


__Soldering__  

Solder the pins to the Teensy first.

Then remove the jig and carefully remove the black plastic from the headers. __Hold onto the black spacers for the next step.__  

After you've removed the plastic, slide the thin yellow kapton spacer thingy onto the bottom of the teensy - this should end up between the teensy and the main board as an insulator. Then drop the Teensy onto the main board so it sits nice and flat. 

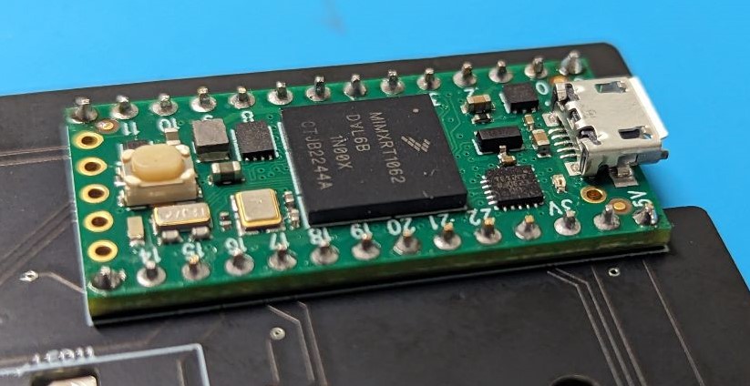
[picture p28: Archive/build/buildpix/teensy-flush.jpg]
teensy flush


To keep the pins from wiggling around while soldering the bottom, either 

 * Put a big piece of tape over the whole teensy to keep it in place and to keep the pins from getting pushed out
 
 * Or push the black plastic bits from the headers onto the pins to hold them in place while soldering
 
 * Or both

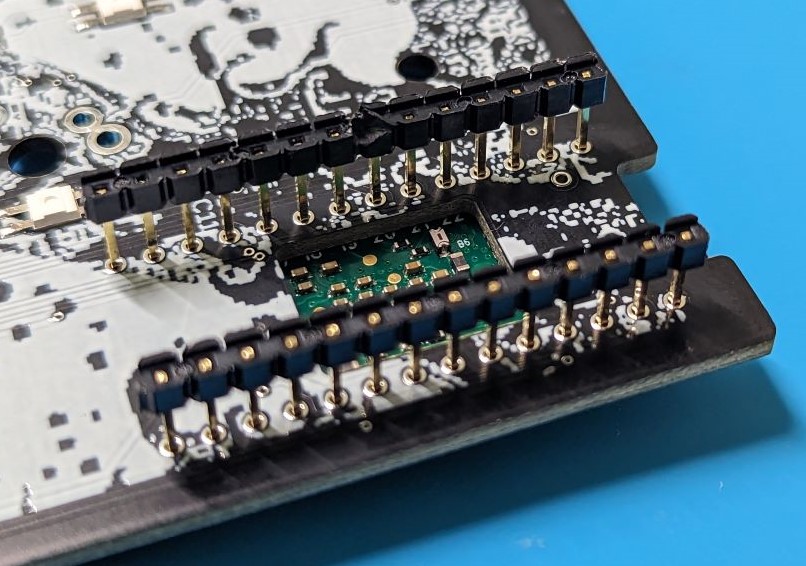
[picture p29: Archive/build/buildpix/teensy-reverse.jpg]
teensy reverse


Flip the board over and solder the pins to the bottom. Try to tack/solder one pin on either side in place while pushing your finger against the teensy to make sure it's absolutely flat against the main pcb.

Once you're happy with the flatness - solder the rest of the pins. Be careful not to push down on the pins while soldering.

Using flush cutters, trim the pins away. Be careful not to nick/scratch the pcb.

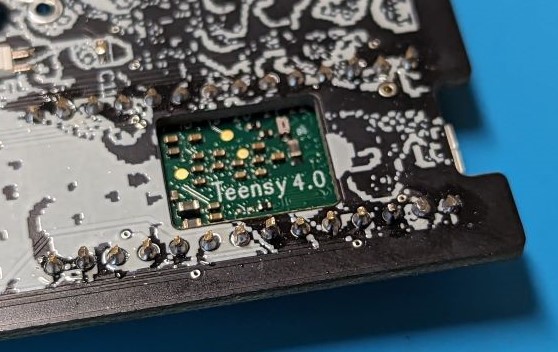
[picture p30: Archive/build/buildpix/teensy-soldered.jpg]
teensy soldered


### OLED

The OLED display sits on a regular header (not flush like the Teensy) the display should be close to level with the keyplate (the OLED glass will be about 0.5-1mm higher than the keyplate).

__TIP:__ I suggest using a section of the header plastic you removed from the Teensy headers as a spacer to hold up the other side of the OLED PCB. Glue or tape a 1x4 chunk of the header plastic to the back of the OLED pcb and this will keep it level and support it while you solder (and after).

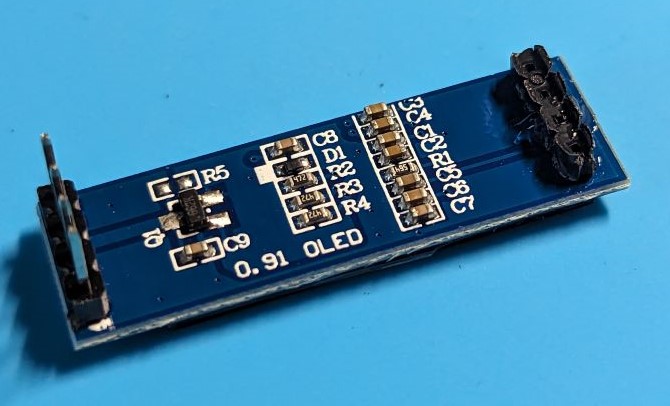
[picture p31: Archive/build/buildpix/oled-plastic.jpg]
oled plastic header

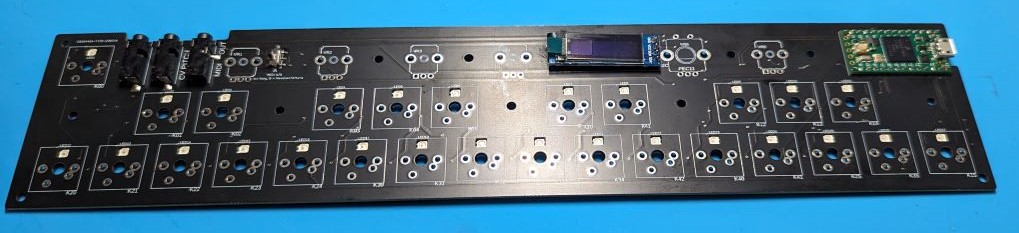
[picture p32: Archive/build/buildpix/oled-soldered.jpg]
oled soldered


Trim the headers on the top side of the OLED if you're worried about something shorting there.

### JACKS, POTS, ENCODER, ETC.

Snap pots and encoders into place and solder.

You may need to gently squeeze the snap-in mounting pins together a tiny bit to get the pots to snap into place.

pots soldered

---

# __STOP HERE AND TEST THINGS__

At this point you can flash the firmware and do some testing.  

See the instructions here (loading a HEX file) - https://llllllll.co/t/how-to-flash-the-firmware-on-a-teensy-micro-controller/20317 if you don't know how to flash firmware to a Teensy. 

The OLED should display something as soon as you plug into USB power.

### LED test

On startup all the LEDs should show a rainbow pattern.

If your LEDs work up to a certain point (e.g. LEDs 1-7 work, LED 8-27 don't):

- The problem is most likely a bad soldering joint on the erroneous LED itself, or on the LED that is RIGHT BEFORE this LED in the chain (in the above example, check LED 7 and 8). Carefully re-solder all connections again to fix the problem (melt the existing solder again, maybe apply some more, make sure it flows nicely between LED and PCB pad)

- Check that the orientation of the LED is correct (see pictures above)

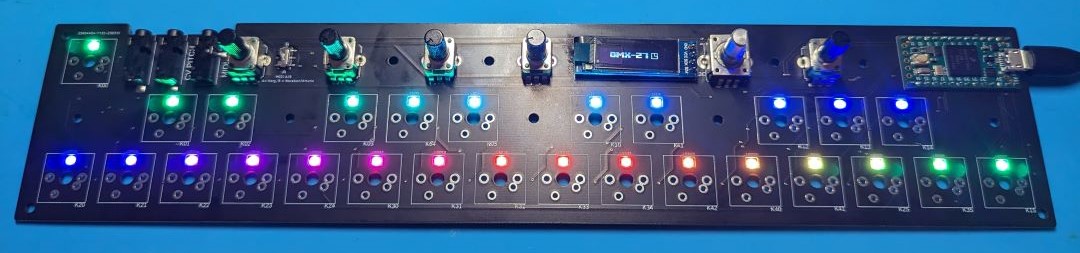
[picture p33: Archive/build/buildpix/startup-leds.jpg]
startup leds


### Switch contact test - AKA "the tweezer test"

You will want to test the pads for each keyswitch on the PCB using tweezers or a piece of wire (a piece of wire will work much better than tweezers!). This is also a second check that the LED for that switch is working correctly.

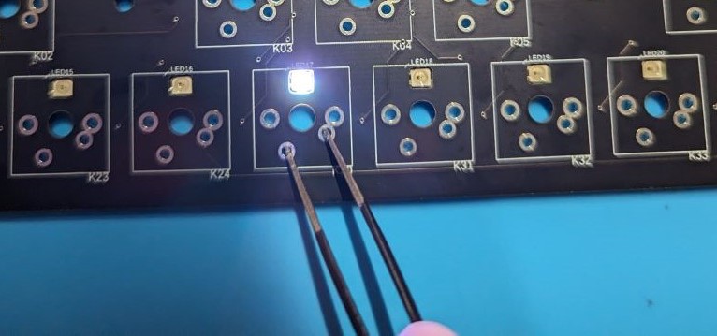
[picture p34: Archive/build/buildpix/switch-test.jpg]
switch-test


When you test the AUX key (top left-most key) - this will light up a total of 15 LEDs on the board. This is normal. 

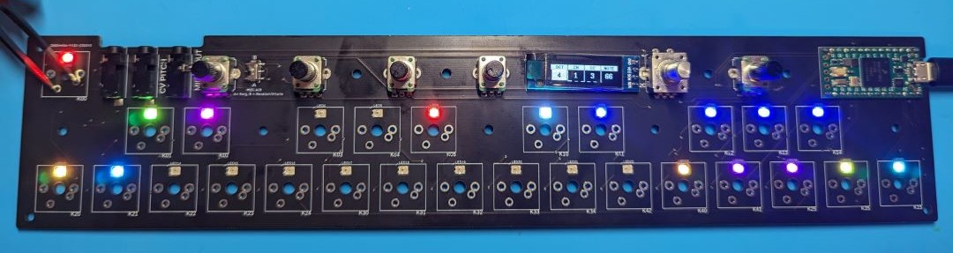
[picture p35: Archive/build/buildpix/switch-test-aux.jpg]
switch test aux


If the LEDs do not light up for each switch contact, check the LEDs again first. A good test is to remove power and re-plug to see if the rainbow LED pattern shows on startup. If all the LEDs are working OK examine the diode adjacent to that switch position and be sure the soldering looks OK.

Note - There are groups of Rows and Columns for sets of switches. If you get a group lighting up, it may be a corresponding pin on the Teensy for that row or column. Ask on Discord if you're stuck here.  

### MIDI test

Use the [browser_test](../browser_test/index.html) script to show USB-MIDI input to your computer. Then you can check to be sure the pots are sending CCs and that you get MIDI note-ons/note-offs when you test each keyswitch's pads. Be sure you have the `oct` (octave) set to 4 on the display (change with encoder knob).

Also test the Hardware MIDI 1/8" jack with an appropriate adapter and synth. Check the A/B switch position for your particular setup (try both to be sure you have the right one).

---

# Continue building

### Acrylic Case Parts

__Carefully__ remove the paper backing from the acrylic parts - the spacer and the back plate. Then set these aside for the next step. 

The spacer layer is pretty fragile - try not to break it. However, even if it does break, it might be fine since this sits in-between the other layers.

### Key Switches

Check the orientation of the switches. The pins go towards the bottom-half and the LED window at the top.  

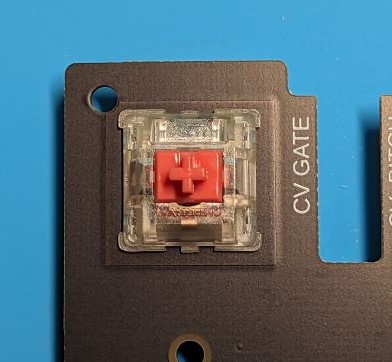
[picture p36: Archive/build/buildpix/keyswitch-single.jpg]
keyswitch single


Snap all the key-switches into the keyplate (from the top). 

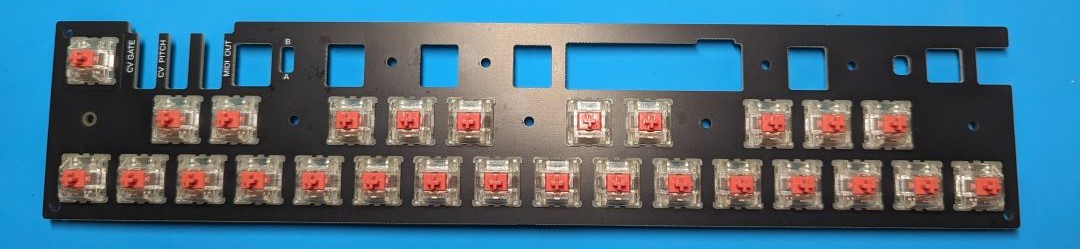
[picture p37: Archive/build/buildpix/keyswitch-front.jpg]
keyswitchs front


The switches may be a tight fit. Be sure they are snapped all the way into place.

Set the black acrylic spacer layer on the main PCB and align it around the various components. Then set the keyplate with switches into place to be sure all the pins line up and everything is nice and flat. You may need to gently bend key-switch pins into place if they got slightly bent in transport.

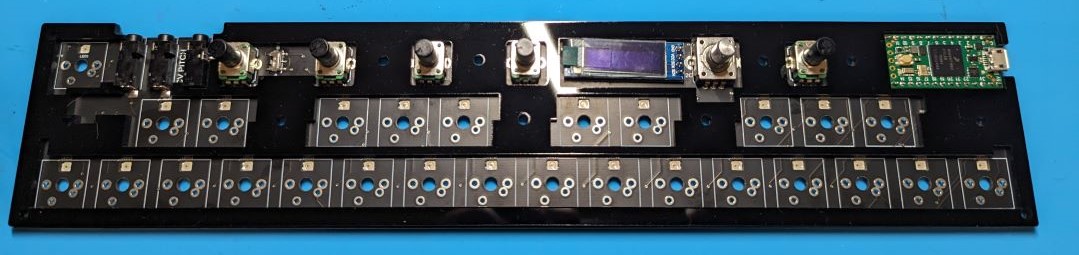
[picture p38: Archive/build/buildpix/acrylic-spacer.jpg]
acrylic-spacer

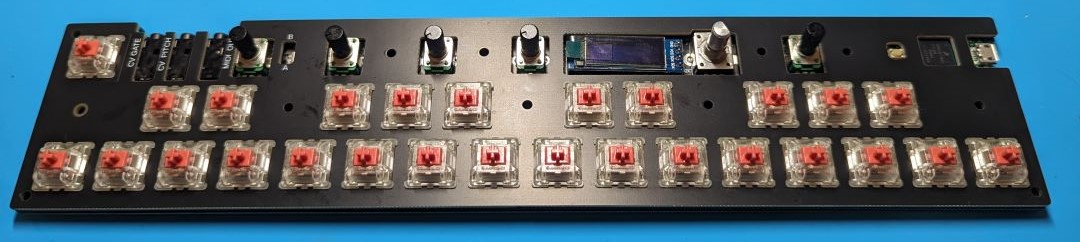
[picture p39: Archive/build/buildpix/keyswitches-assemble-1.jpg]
keyswitches assemble


Use the included case screws/nuts to fix everything together for soldering. I suggest using the holes down the middle of the case. This will ensure the key switches are held in place for soldering and that everything will remain flat.

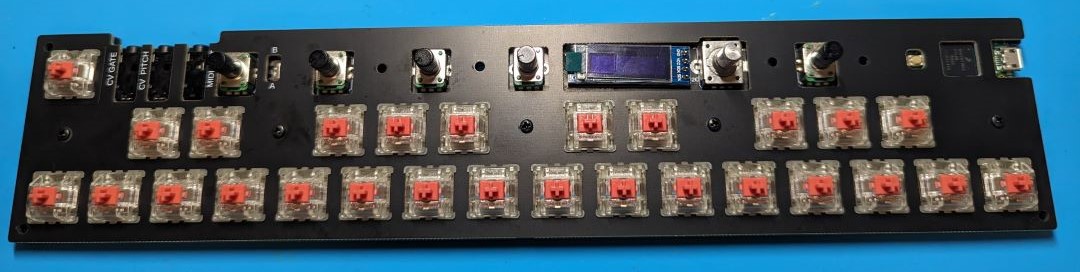
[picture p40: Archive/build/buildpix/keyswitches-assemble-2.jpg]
keyswitches assemble


Solder all the switches.

### Bottom Plate

Then remove the screws/nuts and then reassemble with the bottom plate.

The nuts fit into the captive cutouts on the bottom plate.

bottom plate

top plate

### Teensy Cover

Add the teensy cover plate with the two remaining screws/nuts.

top plate cover

### Pot Knobs

Push the knobs onto the pots, make sure the marking on the knob aligns with the marking on the pot.

pots closeup

### Keycaps

Then install the keycaps with the window on the top for the LEDs.

keycap-install

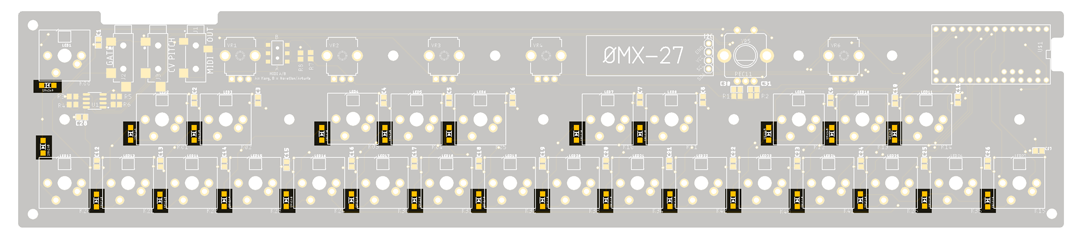
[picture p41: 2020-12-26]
build/buildpix/OMX-27-build-diodes.png

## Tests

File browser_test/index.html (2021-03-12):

# OMX-27 MIDI test

This test page requires a WebMIDI compatible browser. We recommend Google Chrome.

Connect your device via USB _or_ hardware MIDI, not both

MIDI Input: MIDI Output:

1

1

1

1

1

potentiometers

cc:

0

val:

0

notes

note:

0

vel:

0

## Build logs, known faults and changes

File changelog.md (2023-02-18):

# Change log

```
### 1.12.15 beta
### EEPROM VERSION 28
*** Warning!!!: This will clear your global save state if EEPROM version is different from your firmware***
-
- Moving to beta! Only bugfixes and very small features to be added.
-
- BugFix: Fixes crash when changing the arp pattern
-
- Euclidean Mode:
- - Mix page now quickly mutes/unmutes euclidean sequencers
- - Euclidean triggers now rendered to LEDs
- - Better display rendering while playing
- - Euclidean mutes and midifx slots now get saved/loaded
- - UI Messages for F1/F2 keys
- - Mix and Edit Modes:
- - - Hold F1: Mute Euclidean Sequencer
- - - Hold F2: Paste Euclidean Sequencer
- - - Hold F3: Cut Euclidean Seuqncer
- - - Euclidean Sequencer is automatically copied from last selected Euclidean Sequencer
-
- Arpeggiator:
- - Now keeps track of modified notes, so you can move the arp midifx to any position
- - Add MidiFX in front of it without stuck notes. 
- - Arps all properly are syncing in Euclidean mode. 
- - - Try using multiple arps on different Euclidean sequencers, change their parameters,
- - - mod & transpose patterns, rates, for fun and profit. 
- - - works best if you set them to hold.
- - - Try putting a randomize midifx in front of arps and a scaler midifx after
-
- Transpose MidiFX:
- - Octave parameter now does stuff. 
-
- MidiFX Mode:
- - Holding Aux now works in MidiFX mode. 
- - Hold aux to quickly edit parameters
- - quick click the aux to exit MidiFX mode. 
- - Double clicking a MidiFX slot can now be used to enter the MidiFX mode
- - - This is faster than holding(Which also still works)
```

```
### 1.12.14 alpha
### EEPROM VERSION 27
*** Warning!!!: This will clear your global save state if EEPROM version is different from your firmware***
-
- Adds Transpose MidiFX
-
- Adds octave distance param to arp. Determines how many semitones range should consider an octave. 
- - Set to -12 to make the arp go fully downward. 
- - Try using a small amount like +3 semitones combined with a scaler MidiFX after arp
-
- Scaler MidiFX now defaults to using the global scale. If Global Scale is enabled, changing the root and scale in params
- - changes the global ones. 
- - Set Global Scale to false to force to a different scale. 
-
- Arps will now send clock when started and stop clock once stopped. 
- - If multiple arps are active, clock will be started with first arp and stopped with last arp. 
- - Multiple arps will be synced to each other. 
```

```
### 1.12.13 alpha
### EEPROM VERSION 26
*** Warning!!!: This will clear your global save state if EEPROM version is different from your firmware***
- Overlapping chord notes will not send note offs until both chords are released. 
- 
- Arp Improvements
- - Improves pattern playback while changing the held keys. 
- - Default mode will work like Ableton or Matriarch arps. 
- - Example, hold down CEGB, release G in second octave, will stay in second octave and play CEB. 
- - If holding CEGB, and it plays C-E-G, then add an F, it will account for this and play B next
- - Previously, the note index of held notes would not change in this scenario. 
- - So if you're at index 3 of CEGB, and it changes to CEFGB, the index would not be advance, and pattern would go back to F
```

```
### 1.12.11 alpha
### EEPROM VERSION 26
*** Warning!!!: This will clear your global save state if EEPROM version is different from your firmware***
- Adds custom chords to basic chords. 
- - Change the chord type to the last one called "Custom"
- - Now there will be an additional page
- - Dial in up to 6 note offsets in semitones. Offset of "0" will play the Root Note of chord and will display as "R"
- - You can only play the root note in the first slot, otherwise "0" disables the chord note. 
- - The first 4 notes will be modified by the balance parameter. Set balance to 4 white dudes to play all 4 notes. 
- - The keyboard view either by F1 + Chord or right side in split mode can help show which notes are playing. 
-
- Fixes display messages from aux quick-keys not displaying when in keyboard or basic chord pages. 
-
- Slight arp improvements
```

```
### 1.12.10 alpha
### EEPROM VERSION 25
*** Warning!!!: This will clear your global save state if EEPROM version is different from your firmware***
- Quick arp fix
```

```
### 1.12.9 alpha
### EEPROM VERSION 25
*** Warning!!!: This will clear your global save state if EEPROM version is different from your firmware***
- Improves chord UI
- Fixes notes sometimes getting stuck on if changing chord parameters while also playing a chord. 
- Changing basic chord parameters in chord edit mode will now replay the chord with new params. 
- Adjust params in play mode to silently adjust. 
```

```
### 1.12.8 alpha
### EEPROM VERSION 25
*** Warning!!!: This will clear your global save state if EEPROM version is different from your firmware***
- It's a surprise. 
```

```
### 1.12.7 alpha
### EEPROM VERSION 25
*** Warning!!!: This will clear your global save state if EEPROM version is different from your firmware***
- Pots now send CC's in chord mode. 
```

```
### 1.12.6 alpha
*** Warning!!!: This will clear your global save state***
- Improves chord mode
- Split UI Mode: Enabled by default
- Basic Chord Types
- - Each chord can be either basic or interval
- - Interval is like previous mode
- - Basic is a root note, chord type, octave, and balance
- - - Balance will change inversion of chord by either incrementing notes by octave, decrementing by an octave or playing all. 
- - - Also changes the velocity of notes that are not the root note. 
-
- Split UI:
- - Play normal keys on right side of keyboard
- - Play chords on the left
- - If the mode is in edit mode, you can quickly hold a basic chord and set the root note on the left. 
- - - Only happens while holding the chord. 
- - If in play mode, the right side does not modify the chord
-
- Each chord can have it's own Midi Channel and be set to a specific midi fx. 
- Holding aux changes the MidiFX slot for the split keyboard. 
- If you are wondering why the arpeggiator is not starting and stopping, it's because
- the chord you are playing is set to a different midifx index than what is selected in aux
- hold aux and select the midifx slot the chord is set to, then the arp hotkeys will work for
- that chord. 
-
- The split keyboard can also have it's own midi channel. 
-
- Cute animations
- 
- Hold F1 + Chord to enter chord edit mode. 
- This mode is different based on whether the chord is basic or an interval
- In basic mode you can play root chord notes and will see the notes of the chord light up. 
- 
- Default chord config is set to basic chords that are mapped with the root notes in C Major. 
-
- While holding aux or a chord, the selected parameter can be quickly edited to avoid having to click encoder. 
- - holding aux does the same in MI mode. 
```

```
### 1.12.5 alpha
*** Warning!!!: This will clear your global save state if FW < 1.12.2***
- Improves the UI of the MidiFX
- Jumps straight into midifx param view, gets rid of the confusion of two views
- Prevents accidentally changing the type of the selected midifx slot
- You now need to hold down the key for the slot in order to change the type
- New UI when holding down a midi fx slot.
- Holding down a midi fx slot and turning the encoder will move it around. 
- Just hold down a midifx slot key
- - You know you want to. 
- LED Colors for the midifx slots now better represent which midifx are in the slots. 
```

```
### 1.12.4 arp preview
*** Warning!!!: This will clear your global save state if FW < 1.12.2***
- Makes grids pots less grainy
- Grids pots now have high resolution. 
- Girds Pots will stick around mid-point 127
- Threshold needs to be met after loading grids settings to modify density values
- - This is to prevent the values from randomly jumping to value of current pot position
```

```
### 1.12.3 arp preview
*** Warning!!!: This will clear your global save state if FW < 1.12.2***
- Adds Aux hotkeys for controlling the arp
- Key 26: Toggles Arp On and Off
- Key 25: Toggles Hold On and Off
- Key 24: Changes the Arp Octave Range
- Key 23: Changes the Arp Pattern
- Key 22: Enters arp param view
- Arp Param view lets you change the arp parameters and also play the keys
- - Aux to go back to the normal params
- Same hotkeys for Chords Mode and MI modes
- If there is no arp in your current MidiFX slot and arp will be auto-added for you. 
```

```
### 1.12.2 arp preview
*** Warning!!!: This will clear your global save state***
- Saving and loading arpeggiator configs
- Copy pasting arpeggiators
- Arps have chance param now
- MidiFX and arps work in Chord Mode now
- - Use in same way as MI by holding aux key
- Arps work in euclidean mode
- Midifx like harmonizer and randomize in front of the arp can cause arp to get stuck on when used in MI and Chord modes.
- - Turn arp mode to off then back on if this happens. 
- - Recommend trying this with the euclidean sequencer. 
- - MidiFX after the arp are fun and won't cause arp to be stuck on
```

```
### 1.12.1 arp preview
*** Warning!!!: Might clear your global save state***
- Adds the arpeggiator MidiFX
- Arpeggiator currently only works in MI mode. 
- Enter MidiFX mode by holding AUX + MidiFX Mode Key
- Arps for MidiFX groups are currently always running, so if you have multiple arps with hold on
- Things can get weird. 
- Try adding MidiFX before and after arp for fun and profit!
```

```
### 1.11.7 alpha
*** Warning!!!: Will clear your global save state***
- Adds note lengths below 1 to the sequencer. 
- Noteoffs improvement to avoid stuck notes at fast bpms and small note lengths. 
- Reduced struct size of grids saves and euclid saves
```

```
### 1.11.6 alpha
*** Warning!!!: Will clear your global save state***
- Adds swing to grids sequencer
-
- Adds cut/paste step feature to S1 and S2
- - Selecting a step by holding it or F1 plus a step will copy it to a buffer
- - 
- - Hold F2:
- - - Select an unlit step to paste the buffer to that step
- - - Select a lit(unmuted) step to "Cut"(Copies and mutes)
- - - - Simply paste back to that step or unmute if you want to undo
- - 
- - This was inspired by my cut paste feature in GridStep for norns and makes it very quick to shuffle notes around! 
- -
- Fixes bugs by using F1 + step to enter step
- - Notes won't change
- - Works with multiple pages
```

```
### 1.11.5 alpha
*** Warning!!!: Will clear your global save state***
- Adds note lengths to grids sequencer
- Change via GATE param in Instrument view, configurable per instrument
- Fixes labels not always displaying correctly in grids mode
- Adds quickkeys for note length, BPM, and note number to Instrument view
```

```
### 1.11.4 alpha
*** Warning!!!: Will clear your global save state***
- Adds note length control
- Changes octave increment to a value
```

```
### 1.11.3 alpha
*** Warning!!!: Will clear your global save state***
- Adds encoder strum mode to Chords Mode
- Press C#2 to enter mode
- Hold chord and turn encoder
- Pots change Sensitivity, Wrap, and Increment
-
- Changed header format to not interfere with sysex
```

```
### 1.11.2 alpha
***Warning: Will clear your global save state***
- Adds ability to paste chords by holding F2 and selecting a destination
- Adds 3 modes to switch between using F#1,G#1,A#1
- Modes are: Play, Edit, Preset
- Adds 8 presets which save all 16 chord configurations to a slot. 
- Page one now displays the notes of a chord. 
- Press A#2 in Chord edit mode to quickjump to chord notes page. 
- Rotate parameter was not working correctly and did nothing. Now it will rotate and increase octave of rotated notes. 
```

```
### 1.11.1 alpha
***Warning: Will clear your global save state***
- Adds new Chord Mode
- Chords from chords mode will get saved with global save
- Scale settings now also get saved with global save
- Lower 16 keys play chords. 
- Each Chord can be configured by pressing it and using params or in chord edit mode
- Hold F1 + a chord key to jump into chord edit mode
- Chord Edit Mode:
-  Lower Right 8 keys set degree and play the chord
-  Right 4 keys set the base amount of notes in chord
-  Lower Key 5 toggles Spread Up Down - spreads notes in both directions
-  Lower Key 6 toggles Quartal Voicing
-  Key 1 quickselects Root Note
-  Key 2 quickselects Scale Pattern
-  Key 3 quickselects Chord Octave Offset, hold and use lower keys to change value
-  Key 4 quickselects Chord Transpose, hold and use lower keys to change value
-  Key 5 quickselects Chord Spread, hold and use lower keys to change value
-  Key 6 quickselects Chord Rotation, hold and use lower keys to change value
-  Key 7 quickselects Chord Voicing, hold and use lower keys to change value

- Spread:
   Spreads the notes accross note range by lowering or increasing each note of the chord by an octave

- Rotation:
   Changes the order of the notes in the scale

- Voicings:
   0 = none - based off numNotes
   1 = powerChord
   2 = sus2
   3 = sus4
   4 = sus2 + sus4
   5 = add 6th
   6 = add 6th and add 9th
   7 = Kenny Barron Jazz Minor 11th
```

```
### alpha10
- Adds 5 global midifx shared between euclidean sequencer and MI modes. 
- Quickly switch midifx mode in MI mode using aux plus upper 5 keys. 
- Improved MidiFX UI. 
- MidiFX slots in a midifx group increased from 4 to 8
- MidiFX and Euclidean sequencer states are saved with global save
- Cut/copy/paste MidiFX slots in a MidiFX group using F1 and F2 keys. 
```

```
### alpha9
- Adds Norns macro mode
- Adds second page to m8 mode for remote or headless control
```

```
### alpha8
- Reduces number of euclids to 8. Resource problems with 16, pots not updating correctly
- Adds modes: MIX, EDIT, PATTERN
- Hold F2 + select save slot to save. Press key to load. Same concept as grids. 
- Knobs only work to adjust euclid pattern in edit mode. 
- Future plans for MIX mode, but doesn't do much currently. 
```

```
### alpha7
- Increases number of euclids to 16 and MidiFX for euclidean seq mode to 5 for fun and profit. 
- Select a euclid in lower 16. Assign it to 1 of the 5 midi FX in blue on top row
- Hold down on a midifx to enter submode and adjust parameters. 
```

A light update tonight
```
### alpha6
- Adds new Harmonizer MidiFX
- ORIG plays original note if on, does not play if off. 
- Add up to 7 additional notes
- Play complex chords with ease!
```

```
### alpha5
Warning: Alpha build, UI not really fleshed out, might lock up, LEDs not fully implemented for Euclidean Mode
- Euclid UI improvements
- Can change variables for each euclid now like note number, midi channel, velocity
- LEDS should update correctly. 
```

```
### alpha4
Warning: Alpha build, UI not really fleshed out, might lock up, LEDs not fully implemented for Euclidean Mode
- Adds midiFX to MI mode
- Adds Make Mono MidiFX: stops polyphonic chords in their tracks, only one note can survive. 
```

```
### 1.8.1alpha
Warning: Alpha build, UI not really fleshed out, might lock up, LEDs not fully implemented for Euclidean Mode
- EuclideanMode: Adds Scaler MidiFX
```

```
### 1.8.0alpha
Warning: Alpha build, UI not really fleshed out, might lock up
- New euclidean sequencer mode
- MidiFX capabilities added
   - Chance MidiFX: This sets the probability that a note will play. 
   - Randomizer MidiFX: Randomized note number +-, octave +-, velocity +-, length, and chance that note is randomized. 

knobs change settings for active euclid sequencer
   - Knob 1: Rotation
   - Knob 2: Events
   - Knob 3: Steps
   - Knob 4: Gate
   - Knob 5: Sequence rate

Keys 1-4 change selected euclid sequencer. *NOTE* no LEDs for this ATM, screen will display square next to selected sequencer lane. 

Aux: Start / Stop playback. 

Encoder Push: Change between polymeter and polyrhtym mode, recommend pressing this first. 

## MIDIFX
Key 16 Lower: Enter MidiFX Mode

Aux: Exit MidiFX Mode

Keys 1-4: select FX slot. Params change based on selected midifx. 

Keys 9-16: select FX type for selected slot. 
```

### 1.7.7beta
- MI: Fixes normal midi notes being sent while in M8 midi macro mode. 

### 1.7.5beta
- Entering a new mode will set param and page to a default state and put param mode into param select. 
- GR: Using quickkeys in grids mode will now automatically put param mode into param edit. 
- GR: Grids LEDs will not render other leds when holding F1 to change the instrument. 
- S1/S2: Some cleaning of the sequencer mode code to make it easier to check current sequencer mode. 
- S1/S2: Fixed being able to enter patten params mode in S1 & S2 when in note select mode. 
- S1/S2: Adds display message when holding encoder to reset steps in step edit mode.
- S1/S2: Clearing a pattern (F1 + F2 + Pattern Key) in Pattern Params mode(hold pat key) now fully clears pattern. 

### 1.7.4beta
Fixes S1 S2 Bugs:
 - Step LEDs being off by one. Effected step record mode and sequencer reset
 - Note number of current step in step record being off
 - Being able to enter the pattern settings in step record mode if holding a pattern select key
 - Density not being able to be changed in other pages

 Adds Features:
 - Rendering of the step note in step record and note edit modes for S1 and S2
 - New interaction mode. Pressing encoder will toggle between selecting and editing parameters. 
    - This has been applied to all modes. 
    - Param selection vs editing is differentiated by a box highlighting the param in selection mode. 
 - New ParamManager class makes it very easy to manager pages and params. 
    - Big code improvement, however increased possibility that some things might not work right. 

### 1.7.x
Code refactor
Adds Grids sequencer

### 1.6.0
Add MIDI Macro sub-mode for M8 Tracker
Add screensaver and inactivity led animation for MI Mode
Documentation updates

### 1.5.x

Move sequencer into it's own header/source files 

Add SysEx functionality and webmidi configuration

Fix for sequencer pattern save

### 1.4.x

Pattern Length can now be up to 64 steps  

SEQ Mode Quick Keys - Hold F1 + F2  
- first 4 "white keys" select which "page" of the current pattern 

MIDI Mode Quick Keys - Hold AUX  
- first 2 "white keys" are octave up/down  
- first 2 "black keys" are move param selection on the display  

Add MIDI mode params for bank select and program change  

Add RoundRobin MIDI Channel distribution and RR offset value  

Add potentiometer bank select  (CC assignments are still hard coded)

### 1.3.x

Step probability (percentage)

Step Type (play, mute, forward, reverse, random step, random event)

Conditional trigs (elektron style)

Added led status for step events (pulsing)

Bug fix - disable key long press in pattern params

Bug fix - correct wrong velocity sent in playnote on pattern switching

Pot 5 will change/set step velocity in Step Record

### 1.2.x

MIDI-solo

Swing

Auto-reset in patterns

New display layout

Plocks in steprecord

### 1.1.x

Save pattern data

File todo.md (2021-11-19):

# TO-DO 

* Pattern saving w/ FRAM

* Reset copiedFlag/clearedFlag/pastedFlag after some timeout

* Play direction

* Additional mode for MIDI settings (channel, etc)?

* Change MIDI channel per pattern  

* UI

* Copy note to other steps - or assign same note to all steps?

* Panic/all-notes-off on AUX?

* what happens on CV when you have multiple keys pressed?

# NEEDS MORE TESTING

* Step recording (needs testing)
 
* transpose entire sequence (needs testing)

* Conditional triggers (see grid step on norns )

# BUGS

* Pattern params - pattern length leds not set to correct seq-page

* step record skipping steps - sometimes led stays on ??

* CV sequence running all day and twice, the sequencer just paused for awhile and then started up again

# IDEAS / FEATURE REQUESTS / WISH LIST

* chain patterns?

* Record CC automation (playback on clock ticks)

* supersteps ( lfo waveforms per step for CCs - with a bunch of preset waveforms?)

* randomize function (Random Patterns?)

* quantization for the live playing.

* quantize record 

* Arps

* midi delay?

* controllable sequence drift?. P1: probability of step drift, P2: direction and distance, P3: velocity, P4: set of quantizations.

* CV mode - like a single channel version of a 0-control? maybe presets on the "white" keys and LFO's on the "black"

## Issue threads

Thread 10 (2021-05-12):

BUG - Compiler complains about missing  ';'

szydek, 2021-05-12:
Env setup: using Teensyduino v1.53 to compile

First attempt compiling the latest main (OMX_VERSION = 1.1.0), I get an error about missing ";" for these "const int" lines:

https://github.com/okyeron/OMX-27/blob/94ae607654fbebe0e85c6e9f00224fd4771debda/config.h#L49-L51

I updated to the following which appeared to fix the issue:

```#elif MIDIONLY
	const int analogPins[] = {23,A10,21,20,16};  // on MIDI only boards
#else
	const int analogPins[] = {A10,22,21,20,16}; // on 1.0
#endif
```

I can raise a bugfix PR if someone else can verify the issue as well.

okyeron, 2021-05-12:
fixed in 95d4894d7ad085357656951fb42195b2ef7240f1

Closed 2021-05-12.

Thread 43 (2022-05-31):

Teensy 3.2 discontinued / largely globally unavailable

the4ndy, 2022-05-31:
Any plans to port this to another board like the LC or the 4.0 to make it more available? I am having trouble sourcing a Teensy 3.2 as most places indicate they are discontinued or globally on backorder :(

okyeron, 2022-06-04:
I have T3.2s in stock for kits right now.

Do you already have a kit and no Teensy?

Closed 2022-07-19.

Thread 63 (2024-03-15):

How to use PCB designs to order from another manufacturer?

michinger, 2024-03-15:
I am really exited about this project so I am trying to assemble all the parts myself because the kit is out of stock online + shipping to Europe is costly.

I am pretty inexperienced with electronics so I can't quite figure out how I could order your PCBs via an online manufacturer. I found the .ai files in the plates directory but it seems like the websites that let you upload PCB designs that I found only accept eagle, kicad or  gerber files.

Could you maybe help me out how i could best get my hands on a PCB with the provided files in the repo?

Appreciate the amazing work!

okyeron, 2024-03-24:
The PCB design is not open source or available to be manufactured

michinger, 2024-03-24:
Thanks for clarifying, I guess I've got to spend the extra bucks in that case. :)

Closed 2024-04-12.

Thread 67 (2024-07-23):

How does CV output work with Teensy 4?

kalj, 2024-07-23:
I am trying to understand how the CV pitch output is being done when using the recent Teensy 4-based boards? There is this code:

https://github.com/okyeron/OMX-27/blob/588e3eab88c297e596c8b28ddcf5ae5f893fba3c/OMX-27-firmware/src/config.h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

and

https://github.com/okyeron/OMX-27/blob/588e3eab88c297e596c8b28ddcf5ae5f893fba3c/OMX-27-firmware/src/config.cpp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

which suggests that with Teensy 4 (T4), a MCP4725 DAC at I2C address 0x60 is used, but judging by the BOM and the board pictures, it doesn't seem to be one on the board.

How does it work?

kalj, 2024-07-23:
I think I found the answer myself. On this picture, the board looks different and has two ICs (the opamp from before and the DAC). I assume some of the pictures are from a previous revision of the board.

Closed 2024-07-23.

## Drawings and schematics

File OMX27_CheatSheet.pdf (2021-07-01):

AUX & Function Keys | Pattern Keys 1-8
Potentiometers | Encoder

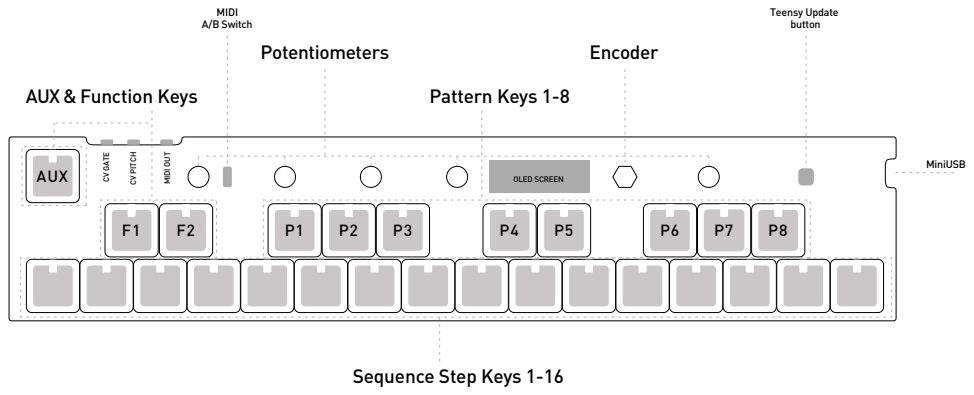
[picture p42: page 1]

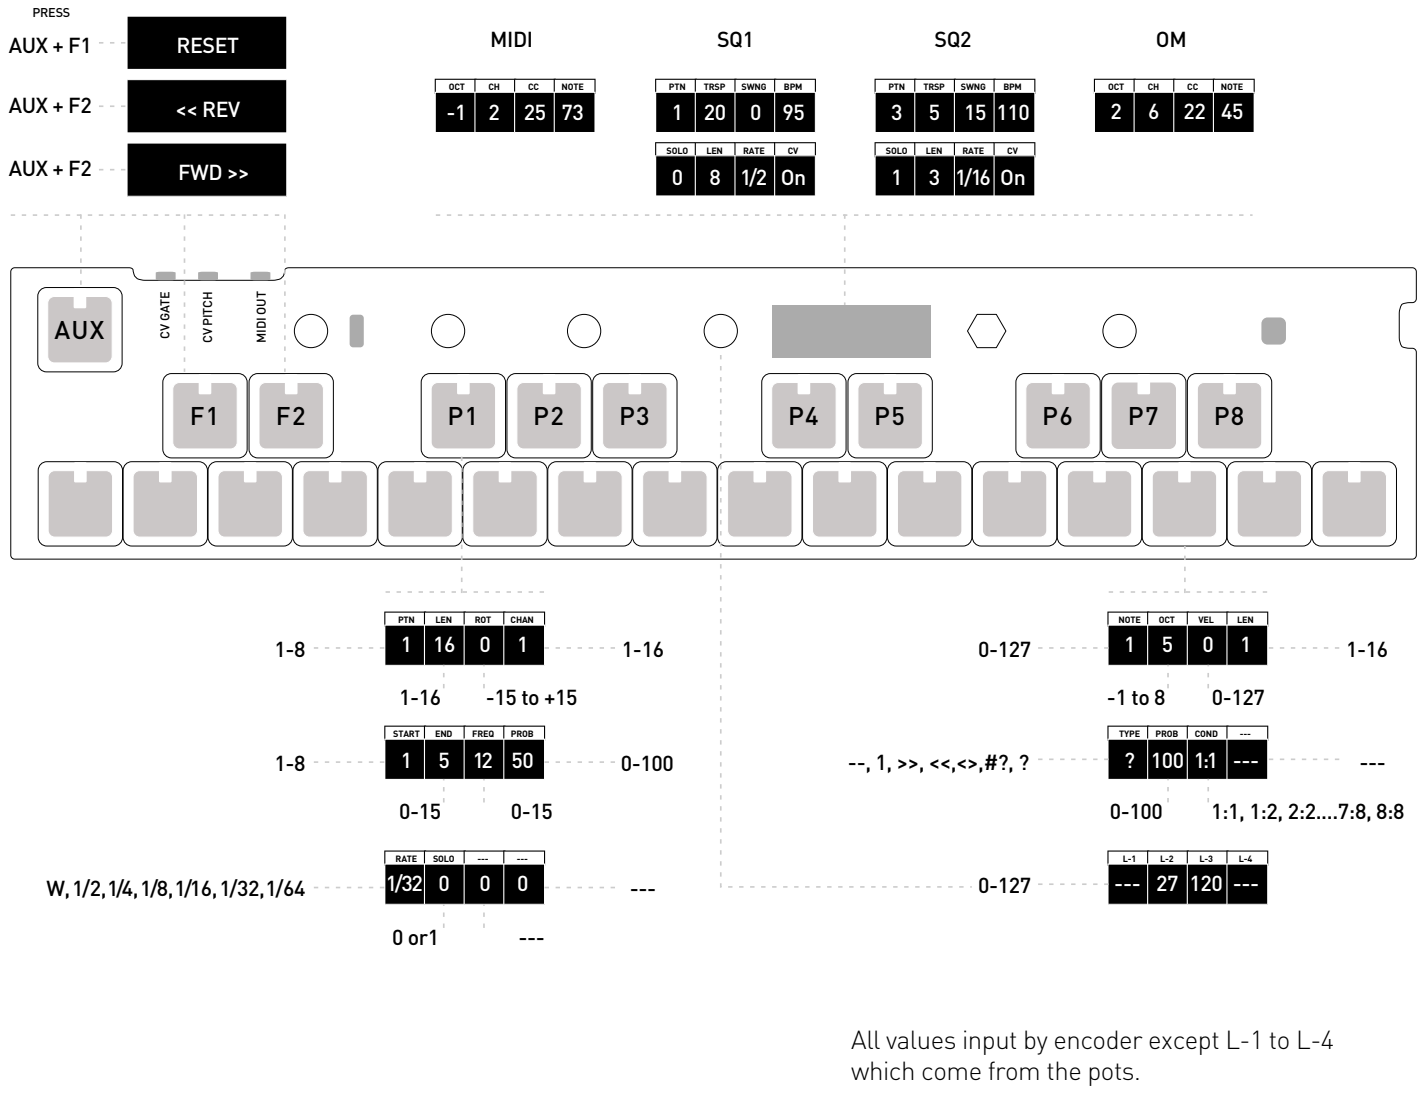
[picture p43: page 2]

All values input by encoder except L-1 to L-4
which come from the pots.

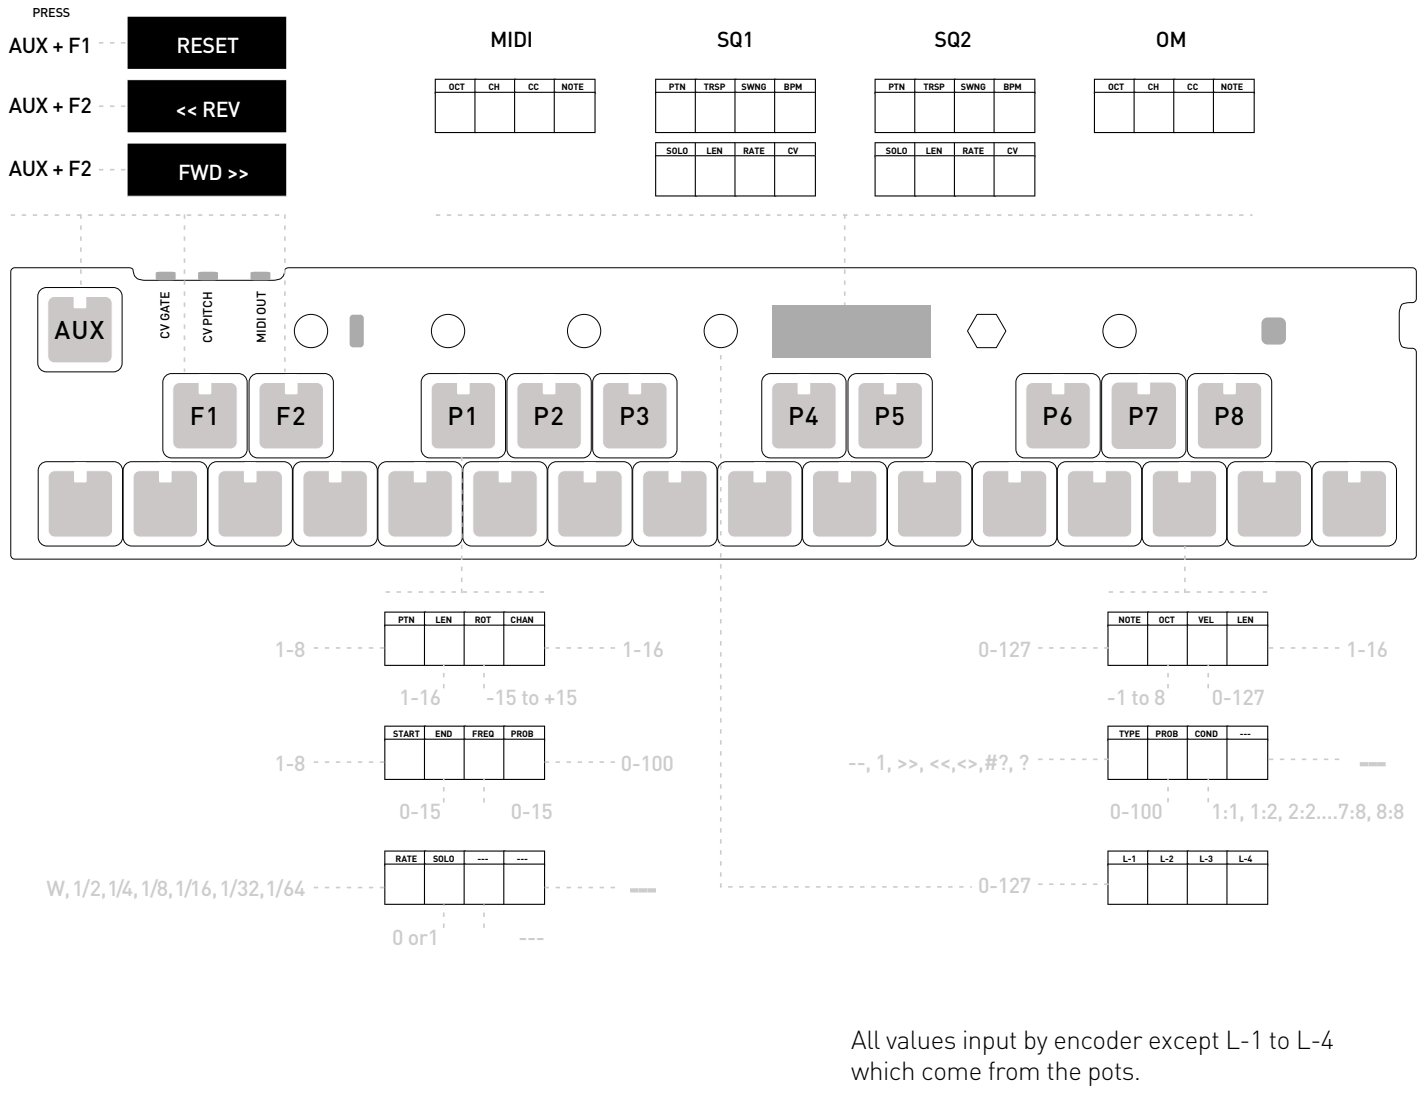
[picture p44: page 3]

All values input by encoder except L-1 to L-4
which come from the pots.

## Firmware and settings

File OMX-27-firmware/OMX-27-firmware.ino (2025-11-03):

// OMX-27 MIDI KEYBOARD / SEQUENCER

//	v1.14.0
//	Last update: Sept 2024
//
//	Original concept and initial code by Steven Noreyko
//  Additional code contributions:
// 		Matt Boone, Steven Zydek,
// 		Chris Atkins, Will Winder,
// 		Michael P Jones
//
//	Big thanks to:
//	John Park and Gerald Stevens for initial testing and feature ideas
//	mzero for immense amounts of code coaching/assistance
//	drjohn for support
//

#include <functional>
#include "src/consts/consts.h"
#include "src/globals.h"
#include "src/config.h"
#include <ResponsiveAnalogRead.h>
#include "src/midi/midi.h"
#include "src/consts/colors.h"
#include "src/ClearUI/ClearUI.h"
#include "src/modes/sequencer.h"
#include "src/midi/noteoffs.h"
#include "src/hardware/storage.h"
#include "src/midi/sysex.h"
#include "src/hardware/omx_keypad.h"
#include "src/utils/omx_util.h"
#include "src/utils/cvNote_util.h"
#include "src/hardware/omx_disp.h"
#include "src/modes/omx_mode_midi_keyboard.h"
#include "src/modes/omx_mode_drum.h"
#include "src/modes/omx_mode_sequencer.h"
#include "src/modes/omx_mode_grids.h"
#include "src/modes/omx_mode_euclidean.h"
#include "src/modes/omx_mode_chords.h"
#include "src/modes/omx_screensaver.h"
#include "src/utils/music_scales.h"
#include "src/hardware/omx_leds.h"
#include "src/midi/MIDIClockStats.h"

// Allows code to compile with smallest code LTO

#if BOARDTYPE != OMX2040
extern "C"
{
	int _getpid() { return -1; }
	int _kill(int pid, int sig) { return -1; }
	int _write() { return -1; }
}
#endif

// #define RAM_MONITOR
// #ifdef RAM_MONITOR
// #include "src/utils/RamMonitor.h"
// #endif

OmxModeMidiKeyboard omxModeMidi;
OmxModeDrum omxModeDrum;
OmxModeSequencer omxModeSeq;
#ifdef OMXMODEGRIDS
OmxModeGrids omxModeGrids;
#endif
OmxModeEuclidean omxModeEuclid;
OmxModeChords omxModeChords;

OmxModeInterface *activeOmxMode;

OmxScreensaver omxScreensaver;

MusicScales globalScale;

MIDIClockStats clockstats;

// storage of pot values; current is in the main loop; last value is for midi output
int volatile currentValue[NUM_CC_POTS];
int lastMidiValue[NUM_CC_POTS];

int temp;

Micros lastProcessTime;

uint8_t RES;
uint16_t AMAX;
int V_scale;

// ENCODER
#if BOARDTYPE == OMX2040
	Encoder myEncoder(25, 26); // encoder pins on hardware
	const int buttonPin = 20;
#else
	Encoder myEncoder(12, 11); // encoder pins on hardware
	const int buttonPin = 0;
#endif
int buttonState = 1;
Button encButton(buttonPin);

// long newPosition = 0;
// long oldPosition = -999;

#if BOARDTYPE == OMX2040
	char mfgstr[32] = "denki-oto";
	char prodstr[32] = "omx-27-v3";
	// MUX config
	const int muxMapping[5] = {2,3,0,1,4}; //{A2, A3, A0, A1, A4};
	const int mux_common_pin = 29;
	const int mux1 = 23;
	const int mux2 = 24;
	const int mux3 = 22;
	using namespace admux;
	Mux mux(Pin(mux_common_pin, INPUT, PinType::Analog), Pinset(mux1, mux2, mux3));

	// USB WebUSB object
	// Landing Page: scheme (0: http, 1: https), url
	// Page source can be found at https://github.com/hathach/tinyusb-webusb-page/tree/main/webusb-rgb
	Adafruit_USBD_WebUSB usb_web;
	WEBUSB_URL_DEF(landingPage, 1 /*https*/, "denki-oto-to-go-go.surge.sh/#/");

#endif

// KEYPAD
// initialize an instance of custom Keypad class
unsigned long longPressInterval = 800;
unsigned long clickWindow = 200;
OMXKeypad keypad(longPressInterval, clickWindow, makeKeymap(keys), rowPins, colPins, ROWS, COLS);

// setup EEPROM/FRAM storage
// Storage *storage;
// SysEx *sysEx;

#ifdef RAM_MONITOR
RamMonitor ram;
uint32_t reporttime;

void report_ram_stat(const char *aname, uint32_t avalue)
{
	Serial.print(aname);
	Serial.print(": ");
	Serial.print((avalue + 512) / 1024);
	Serial.print(" Kb (");
	Serial.print((((float)avalue) / ram.total()) * 100, 1);
	Serial.println("%)");
};

void report_profile_time(const char *aname, uint32_t avalue)
{
	Serial.print(aname);
	Serial.print(": ");
	Serial.print(avalue);
	Serial.println("\n");
};

void report_ram()
{
	bool lowmem;
	bool crash;

	Serial.println("==== memory report ====");

	report_ram_stat("free", ram.adj_free());
	report_ram_stat("stack", ram.stack_total());
	report_ram_stat("heap", ram.heap_total());

	lowmem = ram.warning_lowmem();
	crash = ram.warning_crash();
	if (lowmem || crash)
	{
		Serial.println();

		if (crash)
			Serial.println("**warning: stack and heap crash possible");
		else if (lowmem)
			Serial.println("**warning: unallocated memory running low");
	};

	Serial.println();
};
#endif

// ####### SEQUENCER LEDS #######

void changeOmxMode(OMXMode newOmxmode)
{
	//	Serial.println((String)"NewMode: " + newOmxmode);
	sysSettings.omxMode = newOmxmode;
	sysSettings.newmode = newOmxmode;

	if (activeOmxMode != nullptr)
	{
		activeOmxMode->onModeDeactivated();
	}

	switch (newOmxmode)
	{
	case MODE_MIDI:
		omxModeMidi.setMidiMode();
		activeOmxMode = &omxModeMidi;
		break;
	case MODE_DRUM:
		activeOmxMode = &omxModeDrum;
		break;
	case MODE_CHORDS:
		activeOmxMode = &omxModeChords;
		break;
	case MODE_S1:
		omxModeSeq.setSeq1Mode();
		activeOmxMode = &omxModeSeq;
		break;
	case MODE_S2:
		omxModeSeq.setSeq2Mode();
		activeOmxMode = &omxModeSeq;
		break;
	case MODE_OM:
		omxModeMidi.setOrganelleMode();
		activeOmxMode = &omxModeMidi;
		break;
	case MODE_GRIDS:
#ifdef OMXMODEGRIDS
		activeOmxMode = &omxModeGrids;
#endif
		break;
	case MODE_EUCLID:
		activeOmxMode = &omxModeEuclid;
		break;
	default:
		omxModeMidi.setMidiMode();
		activeOmxMode = &omxModeMidi;
		break;
	}

	activeOmxMode->onModeActivated();

	omxLeds.setDirty();
	omxDisp.setDirty();
}

// ####### END LEDS

// ####### POTENTIOMETERS #######
void readPotentimeters()
{
	for (int k = 0; k < potCount; k++)
	{
		int prevValue = potSettings.analogValues[k];
		int prevAnalog = potSettings.analog[k]->getValue();
#if BOARDTYPE == OMX2040
		temp = mux.read(muxMapping[k]);
// 		temp = 0;
#else
		temp = analogRead(analogPins[k]);
#endif
		potSettings.analog[k]->update(temp);
		// read from the smoother, constrain (to account for tolerances), and map it
		temp = potSettings.analog[k]->getValue();
		temp = constrain(temp, potMinVal, potMaxVal);
		temp = map(temp, potMinVal, potMaxVal, 0, 16383);
		potSettings.hiResPotVal[k] = temp;

		// map and update the value
		potSettings.analogValues[k] = temp >> 7;

		int newAnalog = potSettings.analog[k]->getValue();

		// delta is way smaller on T4 - what to do??
		int analogDelta = abs(newAnalog - prevAnalog);

		// if (k == 1)
		// {
		// 	Serial.print(analogPins[k]);
		// 	Serial.print(" ");
		// 	Serial.print(temp);
		// 	Serial.print(" ");
		// 	Serial.print(potSettings.analogValues[k]);
		// 	Serial.print("\n");
		// }

		if (potSettings.analog[k]->hasChanged())
		{
			// do stuff
			if (sysSettings.screenSaverMode)
			{
				omxScreensaver.onPotChanged(k, prevValue, potSettings.analogValues[k], analogDelta);
			}
			// don't send pots in screensaver
			else
			{
				activeOmxMode->onPotChanged(k, prevValue, potSettings.analogValues[k], analogDelta);
			}
		}

	}
}
// ####### END POTENTIOMETERS #######


void saveHeader()
{
	// 1 byte for EEPROM version
	storage->write(EEPROM_HEADER_ADDRESS + 0, EEPROM_VERSION);

	// 1 byte for mode
	storage->write(EEPROM_HEADER_ADDRESS + 1, (uint8_t)sysSettings.omxMode);

	// 1 byte for the active pattern
	storage->write(EEPROM_HEADER_ADDRESS + 2, (uint8_t)sequencer.playingPattern);

	// 1 byte for Midi channel
	uint8_t unMidiChannel = (uint8_t)(sysSettings.midiChannel - 1);
	storage->write(EEPROM_HEADER_ADDRESS + 3, unMidiChannel);

	for (int b = 0; b < NUM_CC_BANKS; b++)
	{
		for (int i = 0; i < NUM_CC_POTS; i++)
		{
			storage->write(EEPROM_HEADER_ADDRESS + 4 + i + (5 * b), pots[b][i]);
		}
	}
	// Last is 28

	uint8_t midiMacroChan = (uint8_t)(midiMacroConfig.midiMacroChan - 1);
	storage->write(EEPROM_HEADER_ADDRESS + 29, midiMacroChan);

	uint8_t midiMacroId = (uint8_t)midiMacroConfig.midiMacro;
	storage->write(EEPROM_HEADER_ADDRESS + 30, midiMacroId);

	uint8_t scaleRoot = (uint8_t)scaleConfig.scaleRoot;
	storage->write(EEPROM_HEADER_ADDRESS + 31, scaleRoot);

	uint8_t scalePattern = (uint8_t)scaleConfig.scalePattern;
	storage->write(EEPROM_HEADER_ADDRESS + 32, scalePattern);

	uint8_t lockScale = (uint8_t)scaleConfig.lockScale;
	storage->write(EEPROM_HEADER_ADDRESS + 33, lockScale);

	uint8_t scaleGrp16 = (uint8_t)scaleConfig.group16;
	storage->write(EEPROM_HEADER_ADDRESS + 34, scaleGrp16);

	storage->write(EEPROM_HEADER_ADDRESS + 35, midiSettings.defaultVelocity);

	storage->write(EEPROM_HEADER_ADDRESS + 36, clockConfig.globalQuantizeStepIndex);

	storage->write(EEPROM_HEADER_ADDRESS + 37, cvNoteUtil.triggerMode);

	storage->write(EEPROM_HEADER_ADDRESS + 38, potSettings.potbank);

	// 38 bytes
}

// returns true if the header contained initialized data
// false means we shouldn't attempt to load any further information
bool loadHeader(void)
{
	uint8_t version = storage->read(EEPROM_HEADER_ADDRESS + 0);

	char buf[64];
	snprintf(buf, sizeof(buf), "EEPROM Header Version is %d\n", version);
	// Serial.print(buf);

	// Uninitalized EEPROM memory is filled with 0xFF
	if (version == 0xFF)
	{
		// EEPROM was uninitialized
		// Serial.println("version was 0xFF");
		return false;
	}

	if (version != EEPROM_VERSION)
	{
		// write an adapter if we ever need to increment the EEPROM version and also save the existing patterns
		// for now, return false will essentially reset the state
		// Serial.println("version not matched");
		return false;
	}

	sysSettings.omxMode = (OMXMode)storage->read(EEPROM_HEADER_ADDRESS + 1);

	sequencer.playingPattern = storage->read(EEPROM_HEADER_ADDRESS + 2);
	sysSettings.playingPattern = sequencer.playingPattern;

	uint8_t unMidiChannel = storage->read(EEPROM_HEADER_ADDRESS + 3);
	sysSettings.midiChannel = unMidiChannel + 1;

	// Serial.println("Loading banks");
	for (int b = 0; b < NUM_CC_BANKS; b++)
	{
		for (int i = 0; i < NUM_CC_POTS; i++)
		{
			pots[b][i] = storage->read(EEPROM_HEADER_ADDRESS + 4 + i + (5 * b));
		}
	}

	uint8_t midiMacroChannel = storage->read(EEPROM_HEADER_ADDRESS + 29);
	midiMacroConfig.midiMacroChan = midiMacroChannel + 1;

	uint8_t midiMacro = storage->read(EEPROM_HEADER_ADDRESS + 30);
	midiMacroConfig.midiMacro = midiMacro;

	uint8_t scaleRoot = storage->read(EEPROM_HEADER_ADDRESS + 31);
	scaleConfig.scaleRoot = scaleRoot;

	int8_t scalePattern = (int8_t)storage->read(EEPROM_HEADER_ADDRESS + 32);
	scaleConfig.scalePattern = scalePattern;

	bool lockScale = (bool)storage->read(EEPROM_HEADER_ADDRESS + 33);
	scaleConfig.lockScale = lockScale;

	bool scaleGrp16 = (bool)storage->read(EEPROM_HEADER_ADDRESS + 34);
	scaleConfig.group16 = scaleGrp16;

	globalScale.calculateScale(scaleConfig.scaleRoot, scaleConfig.scalePattern);

	midiSettings.defaultVelocity = storage->read(EEPROM_HEADER_ADDRESS + 35);

	clockConfig.globalQuantizeStepIndex = constrain(storage->read(EEPROM_HEADER_ADDRESS + 36), 0, kNumArpRates - 1);

	cvNoteUtil.triggerMode = constrain(storage->read(EEPROM_HEADER_ADDRESS + 37), 0, 1);

	potSettings.potbank = constrain(storage->read(EEPROM_HEADER_ADDRESS + 38), 0, NUM_CC_BANKS-1);

	// digitalWrite(BLUELED, HIGH);
	return true;
}

void savePatterns(void)
{
	bool isEeprom = storage->isEeprom();

	int patternSize = serializedPatternSize(isEeprom);
	int nLocalAddress = EEPROM_PATTERN_ADDRESS;

	// Serial.println((String)"Seq patternSize: " + patternSize);
	int seqPatternNum = isEeprom ? NUM_SEQ_PATTERNS_EEPROM : NUM_SEQ_PATTERNS;

	for (int i = 0; i < seqPatternNum; i++)
	{
		auto pattern = (byte *)sequencer.getPattern(i);
		for (int j = 0; j < patternSize; j++)
		{
			storage->write(nLocalAddress + j, *pattern++);
		}

		nLocalAddress += patternSize;
	}

	if (isEeprom)
	{
		return;
	}
	// Serial.println((String)"nLocalAddress: " + nLocalAddress); // 5784
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
void loop()
{
	//	customKeypad.tick();
	keypad.tick();
	// clksTimer = 0; // TODO - didn't see this used anywhere

	Micros now = micros();
	Micros passed = now - lastProcessTime;
	lastProcessTime = now;

	sysSettings.timeElasped = passed;

	seqConfig.currentFrameMicros = micros();
	// Micros timeStart = micros();
	activeOmxMode->loopUpdate(passed);
	cvNoteUtil.loopUpdate(passed);

	if (passed > 0) // This should always be true
	{
		if (sequencer.playing || omxUtil.areClocksRunning())
		{
			omxScreensaver.resetCounter(); // screenSaverCounter = 0;
		}
		omxUtil.advanceClock(activeOmxMode, passed);
		omxUtil.advanceSteps(passed);
	}

	// DISPLAY SETUP -- why is this display. instead of omxDisp. ??
	display.clearDisplay();

	// ############### SLEEP MODE ###############
	//
	//	Serial.println(screenSaverCounter);
	omxScreensaver.updateScreenSaverState();
	sysSettings.screenSaverMode = omxScreensaver.shouldShowScreenSaver();

	// ############### POTS ###############
	//
	readPotentimeters();

	bool omxModeChangedThisFrame = false;

	// ############### EXTERNAL MODE CHANGE / SYSEX ###############
	if ((!encoderConfig.enc_edit && (sysSettings.omxMode != sysSettings.newmode)) || sysSettings.refresh)
	{
		sysSettings.newmode = sysSettings.omxMode;
		changeOmxMode(sysSettings.omxMode);
		omxModeChangedThisFrame = true;

		sequencer.playingPattern = sysSettings.playingPattern;
		omxDisp.setDirty();
		omxLeds.setAllLEDS(0, 0, 0);
		omxLeds.setDirty();
		sysSettings.refresh = false;
	}

	// ############### ENCODER ###############
	//
	auto u = myEncoder.update();
// 	Serial.println("Encoder update");
	if (u.active())
	{
		auto amt = u.accel(1);		   // where 5 is the acceleration factor if you want it, 0 if you don't)
		omxScreensaver.resetCounter(); // screenSaverCounter = 0;
									   //    	Serial.println(u.dir() < 0 ? "ccw " : "cw ");
									   //    	Serial.println(amt);

		// Change Mode
		if (encoderConfig.enc_edit)
		{
			// set mode
			//			int modesize = NUM_OMX_MODES;
			sysSettings.newmode = (OMXMode)constrain(sysSettings.newmode + amt, 0, NUM_OMX_MODES - 1);
			// omxDisp.dispMode();
			// omxDisp.bumpDisplayTimer();
			omxDisp.setDirty();
			omxLeds.setDirty();
		}
		else
		{
			activeOmxMode->onEncoderChanged(u);
		}
	}
	// END ENCODER

	// ############### ENCODER BUTTON ###############
	//
	auto s = encButton.update();
	switch (s)
	{
	// SHORT PRESS
	case Button::Down:				   // Serial.println("Button down");
		omxScreensaver.resetCounter(); // screenSaverCounter = 0;

		// what page are we on?
		if (sysSettings.newmode != sysSettings.omxMode && encoderConfig.enc_edit)
		{
			changeOmxMode(sysSettings.newmode);
			omxModeChangedThisFrame = true;
			seqStop();
			omxLeds.setAllLEDS(0, 0, 0);
			encoderConfig.enc_edit = false;
			// omxDisp.dispMode();
			omxDisp.setDirty();
		}
		else if (encoderConfig.enc_edit)
		{
			encoderConfig.enc_edit = false;
		}

		// Prevents toggling encoder select when entering mode
		if (!omxModeChangedThisFrame)
		{
			activeOmxMode->onEncoderButtonDown();
		}

		omxDisp.setDirty();
		break;

	// LONG PRESS
	case Button::DownLong: // Serial.println("Button downlong");
		if (activeOmxMode->shouldBlockEncEdit())
		{
			activeOmxMode->onEncoderButtonDown();
		}
		else
		{
			// Enter mode change
			encoderConfig.enc_edit = true;
			sysSettings.newmode = sysSettings.omxMode;
			omxLeds.setAllLEDS(0, 0, 0);
			omxDisp.setDirty();
			// omxDisp.dispMode();
		}

		omxDisp.setDirty();
		break;
	case Button::Up: // Serial.println("Button up");
		activeOmxMode->onEncoderButtonUp();
		break;
	case Button::UpLong: // Serial.println("Button uplong");
		activeOmxMode->onEncoderButtonUpLong();
		break;
	default:
		break;
	}
	// END ENCODER BUTTON

	// ############### KEY HANDLING ###############
	//
	while (keypad.available())
	{
// 		Serial.println("keypad");
		auto e = keypad.next();
		int thisKey = e.key();
		bool keyConsumed = false;
		// int keyPos = thisKey - 11;
		// int seqKey = keyPos + (sequencer.patternPage[sequencer.playingPattern] * NUM_STEPKEYS);

		if (e.down())
		{
			omxScreensaver.resetCounter(); // screenSaverCounter = 0;
			midiSettings.keyState[thisKey] = true;
		}

		if (e.down() && thisKey == 0 && encoderConfig.enc_edit)
		{
			// temp - save whenever the 0 key is pressed in encoder edit mode
			omxDisp.displayMessage("Saving...");
			omxDisp.isDirty();
			omxDisp.showDisplay();
			saveToStorage();
			//	Serial.println("EEPROM saved");
			omxDisp.displayMessage("Saved State");
			encoderConfig.enc_edit = false;
			omxLeds.setAllLEDS(0, 0, 0);
			activeOmxMode->onModeActivated();
			omxDisp.isDirty();
			omxLeds.isDirty();
			keyConsumed = true;
		}

		if (!keyConsumed)
		{
			activeOmxMode->onKeyUpdate(e);
		}

		// END MODE SWITCH

		if (!e.down())
		{
			midiSettings.keyState[thisKey] = false;
		}

		// ### LONG KEY SWITCH PRESS
		if (e.held() && !keyConsumed)
		{
			// DO LONG PRESS THINGS
			activeOmxMode->onKeyHeldUpdate(e); // Only the sequencer uses this, could probably be handled in onKeyUpdate() but keyStates are modified before this stuff happens.
		}									   // END IF HELD

	} // END KEYS WHILE

	if (!sysSettings.screenSaverMode)
	{
		omxLeds.updateBlinkStates();
		omxDisp.UpdateMessageTextTimer();

		if (encoderConfig.enc_edit)
		{
			omxDisp.dispMode();
		}
		else
		{
			activeOmxMode->onDisplayUpdate();
		}
	}
	else
	{ // if screenSaverMode
		omxScreensaver.onDisplayUpdate();
	}

	// DISPLAY at end of loop
	omxDisp.showDisplay();
	omxLeds.showLeds();

	while (MM::usbMidiRead())
	{
		// incoming messages - see handlers
	}
	while (MM::midiRead())
	{
		// incoming messages - see handlers
	}

	// Serial.println(clockstats.getBPM());

	// Micros elapsed = micros() - timeStart;
	// if ((timeStart - reporttime) > 2000)
	// {
	// 	report_profile_time("Elapsed", elapsed);
	// 	reporttime = timeStart;
	// 	// report_ram();
	// };

#ifdef RAM_MONITOR
	uint32_t time = millis();

	if ((time - reporttime) > 2000)
	{
		reporttime = time;
		report_ram();
	};

	ram.run();
#endif

} // ######## END MAIN LOOP ########



// ####### SETUP #######

void setup()
{

#if BOARDTYPE == TEENSY4
// 	Serial.println("Teensy 4.0");
// 	Serial.println("DAC Start!");
	dac.begin(DAC_ADDR);

#elif BOARDTYPE == OMX2040
// 	Serial.println("RP2040");
	TinyUSBDevice.setManufacturerDescriptor(mfgstr);
	TinyUSBDevice.setProductDescriptor(prodstr);

	pinMode(REDLED, OUTPUT);	// RED LED
	pinMode(BLUELED, OUTPUT);	// BLUE LED
	digitalWrite(REDLED, LOW); 	// digitalWrite(REDLED, LOW);
	digitalWrite(BLUELED, HIGH);

	pinMode(FIVEVEN, OUTPUT); 		// 5v enable Pin
	digitalWrite(FIVEVEN, HIGH);	// Turn 5v enable ON

	pinMode(TXLED, OUTPUT); 	// TX
	pinMode(RXLED, INPUT); 	// RX

	digitalWrite(TXLED, LOW);
	digitalWrite(RXLED, LOW);
	Wire1.setSDA(I2C_SDA);		// i2c1 SDA
	Wire1.setSCL(I2C_SCL);		// i2c1 SCL

// 	Serial1.setRX(RXLED);
// 	Serial1.setTX(TXLED);

	dac.begin(DAC_ADDR, &Wire1);

	// Initialize WebUSB for connection notification, etc
 	usb_web.setLandingPage(&landingPage);
	usb_web.begin();

#else
// 	Serial.println("Teensy 3.2");
#endif

	// HW MIDI
	MM::begin();

	// CV GATE pin
	pinMode(CVGATE_PIN, OUTPUT);
	// ENCODER BUTTON pin
	pinMode(buttonPin, INPUT_PULLUP);

	// Storage - FIX?
	storage = Storage::initStorage();
	sysEx = new SysEx(storage, &sysSettings);
	// Serial.println( "initStorage" );

#ifdef RAM_MONITOR
	ram.initialize();
#endif

	// clksTimer = 0; // TODO - didn't see this used anywhere
	omxScreensaver.resetCounter();
	// ssstep = 0;

	lastProcessTime = micros();
	omxUtil.restartClocks();
	omxUtil.subModeClearStorage.setStoragePtr(storage);


// #if BOARDTYPE == OMX2040
	// while (!TinyUSBDevice.mounted()){
	// 	delay(100);
	// }
// #endif

	// Serial
	Serial.begin(115200);
	delay(100);


	// SET ANALOG READ resolution to teensy's 13 usable bits
#if BOARDTYPE == TEENSY4
	randomSeed(analogRead(13));
	srand(analogRead(13));
	analogReadResolution(10); // Teensy 4 = 10 bits
#elif BOARDTYPE == OMX2040
// 	randomSeed(analogRead(29));
// 	srand(analogRead(29));
	analogReadResolution(10); // MUX = 10 bits
#else
	randomSeed(analogRead(13));
	srand(analogRead(13));
	analogReadResolution(13); // Teensy 3.x = 13 bits
#endif


	// initialize ANALOG INPUTS and ResponsiveAnalogRead
	for (int i = 0; i < potCount; i++)
	{
// 		potSettings.analog[i] = new ResponsiveAnalogRead(0, true, .001);
// 		potSettings.analog[i]->setAnalogResolution(1 << 13);

#if BOARDTYPE == TEENSY4
		pinMode(analogPins[i], INPUT);
		potSettings.analog[i] = new ResponsiveAnalogRead(analogPins[i], true, .001);
// 		potSettings.analog[i]->setAnalogResolution(10);
//		potSettings.analog[i]->setActivityThreshold(8);
#elif BOARDTYPE == OMX2040
		potSettings.analog[i] = new ResponsiveAnalogRead(mux_common_pin, true, .001);
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

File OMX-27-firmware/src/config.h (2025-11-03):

#pragma once

#ifndef OMX_CONFIG_DONE
#define OMX_CONFIG_DONE // prevent redifinition pragma once should handle though.

#include <Arduino.h>
#include <stdio.h>
#include <stdarg.h>
#include <stdint.h>
#include <ResponsiveAnalogRead.h>
#include <Wire.h>
#include <Adafruit_MCP4725.h>
#include "consts/colors.h"
#include <Mux.h>

// #include <cstdarg>

/* * firmware metadata  */
// OMX_VERSION = 1.14.0
const int MAJOR_VERSION = 1;
const int MINOR_VERSION = 14;
const int POINT_VERSION = 0;

// 1.13.2 - Adds CV Trigger modes for legato and regtrig
// 1.13.3 - Bugfix for CV Trigger modes
// 1.13.8 - option to send midi all the time or not
// 1.14.0 - finish RP2040 port

const int DEVICE_ID = 2;

// DAC
extern Adafruit_MCP4725 dac;

enum OMXMode
{
	MODE_MIDI = 0,
	MODE_DRUM,
	MODE_CHORDS,
	MODE_S1,
	MODE_S2,
	MODE_GRIDS,
	MODE_EUCLID,
	MODE_OM,

	NUM_OMX_MODES
};

enum MIDIFXTYPE
{
	MIDIFX_NONE,
	MIDIFX_CHANCE,
	MIDIFX_TRANSPOSE,
	MIDIFX_RANDOMIZER,
	MIDIFX_SELECTOR,
	MIDIFX_CHORD,
	MIDIFX_HARMONIZER,
	MIDIFX_SCALER,
	MIDIFX_MONOPHONIC,
	MIDIFX_REPEAT,
	MIDIFX_ARP,
	MIDIFX_COUNT
};

extern const OMXMode DEFAULT_MODE;

enum FUNCKEYMODE
{
	FUNCKEYMODE_NONE, // No function keys
	FUNCKEYMODE_F1,	  // F1 held
	FUNCKEYMODE_F2,	  // F2 held
	FUNCKEYMODE_F3	  // F1 + F3 held
};

// Increment this when data layout in EEPROM changes. May need to write version upgrade readers when this changes.
extern const uint8_t EEPROM_VERSION;

#define EEPROM_HEADER_ADDRESS 0
#define EEPROM_HEADER_SIZE 40
#define EEPROM_PATTERN_ADDRESS 64

#define TRACKED_CV_SIZE 16 //

// next address 1104 (was 1096 before clock)

extern const byte DAC_ADDR;

// DEFINE CC NUMBERS FOR POTS // CCS mapped to Organelle Defaults
extern const int CC1;
extern const int CC2;
extern const int CC3;
extern const int CC4;
extern const int CC5; // change to 25 for EYESY Knob 5

extern const int CC_AUX; // Mother mode - AUX key
extern const int CC_OM1; // Mother mode - enc switch
extern const int CC_OM2; // Mother mode - enc turn

extern const int LED_BRIGHTNESS;

// DONT CHANGE ANYTHING BELOW HERE

extern const int LED_PIN;
extern const int LED_COUNT;

// POTS/ANALOG INPUTS - pins for analog inputs
extern const int analogPins[];

#define NUM_CC_BANKS 5
#define NUM_CC_POTS 5
extern int pots[NUM_CC_BANKS][NUM_CC_POTS]; // the MIDI CC (continuous controller) for each analog input

using Micros = unsigned long; // for tracking time per pattern


struct SysSettings
{
	OMXMode omxMode = DEFAULT_MODE;
	OMXMode newmode = DEFAULT_MODE;
	uint8_t midiChannel = 0;
	int playingPattern;
	bool refresh = false;
	bool screenSaverMode = false;
	unsigned long timeElasped;
};



extern const int potCount;

struct PotSettings
{
	ResponsiveAnalogRead *analog[NUM_CC_POTS];

	// ANALOGS
	int potbank = 0;
	int analogValues[NUM_CC_POTS] = {0, 0, 0, 0, 0}; // default values
	int potValues[NUM_CC_POTS] = {0, 0, 0, 0, 0};
	int hiResPotVal[NUM_CC_POTS] = {0, 0, 0, 0, 0};
	int potCC = pots[potbank][0];
	int potVal = analogValues[0];
	int potNum = 0;
};
// Put in global struct to share across classes

extern int potMinVal;
extern int potMaxVal;


struct MidiConfig
{
	uint8_t defaultVelocity = 100;
	int octave = 0; // default C4 is 0 - range is -4 to +5
	// int newoctave = octave;
	int transpose = 0;
	int rotationAmt = 0;

	uint8_t swing = 0;
	const int maxswing = 100;
	// int swing_values[maxswing] = {0, 1, 3, 5, 52, 66, 70, 72, 80, 99 }; // 0 = off, <50 early swing , >50 late swing, 99=drunken swing

	bool keyState[27] = {false};
	int midiKeyState[27] = {-1, -1, -1, -1, -1, -1, -1, -1, -1, -1, -1, -1, -1, -1, -1, -1, -1, -1, -1, -1, -1, -1, -1, -1, -1, -1, -1};
	int midiChannelState[27] = {-1, -1, -1, -1, -1, -1, -1, -1, -1, -1, -1, -1, -1, -1, -1, -1, -1, -1, -1, -1, -1, -1, -1, -1, -1, -1, -1};
	int rrChannel = 0;
	bool midiRoundRobin = false;
	int midiRRChannelOffset = 0;
	int midiRRChannelCount = 1;
	uint8_t midiLastNote = 0;
	uint8_t midiLastVel = 0;
	int currpgm = 0;
	int currbank = 0;
	bool midiInToCV = true;
	bool midiSoftThru = false;
	bool midiAUX = false;
	bool isBankSelect = false;
};

extern MidiConfig midiSettings;

// struct MidiPage {
// 	const int numPages = 4;
// 	const int numParams = numPages * 5;
// 	int miparam = 0; // midi params item counter
//     int mmpage = 0;
// };
// extern MidiPage midiPageParams;

struct MidiMacroConfig
{
	int midiMacro = 0;
	bool m8AUX = false;
	int midiMacroChan = 10;
};


// extern bool m8mutesolo[];

struct EncoderConfig
{
	bool enc_edit = false;
};

extern EncoderConfig encoderConfig;

extern const uint32_t secs2micros;
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

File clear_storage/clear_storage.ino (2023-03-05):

/**
 * clear_storage.ino
 *
 * Quick sketch for zeroing out contents of FRAM or EEEPROM storage
 *
 */

#include <EEPROM.h>
#include <Adafruit_FRAM_I2C.h>
#include <string>

#include <Wire.h>
#include <Adafruit_SSD1306.h>
#include <Adafruit_GFX.h>

#define WHITE SSD1306_WHITE
#define BLACK SSD1306_BLACK
#define DISPLAY_WIDTH 128
#define DISPLAY_HEIGHT 32
#define OLED_RST -1
#define CLKDURING 1000000
#define CLKAFTER 400000

Adafruit_FRAM_I2C fram = Adafruit_FRAM_I2C();

Adafruit_SSD1306 display = Adafruit_SSD1306(DISPLAY_WIDTH, DISPLAY_HEIGHT, &Wire, OLED_RST, CLKDURING, CLKAFTER);

const int framCapacity = 32000;
const int eepromCapacity = 2048;	// 2048; 3.2
// const int eepromCapacity = 1080; 	// 1080; 4.0

bool usingFram = false;

void setup() {
	setupDisplay();
	display.setCursor(8, 8);

	if (fram.begin()) {
		clearFRAM();
	} else {
		clearEEPROM();
	}

	display.clearDisplay();
	display.setCursor(20, 8);
	display.print("Storage cleared");
	display.display();
}

void loop() {
	// ...
}

void clearFRAM() {
	usingFram = true;

	for (int address = 0; address < framCapacity; address++) {
		fram.write(address, 0x0);

		printProgressUpdate(address, framCapacity);
	}
}

void clearEEPROM() {
	for (int address = 0; address < eepromCapacity; address++) {
		EEPROM.update(address, 0x0);

		printProgressUpdate(address, eepromCapacity);
	}
}

void printProgressUpdate(int current, int total) {
	// only update every KB
	if (current % 1000 != 0) {
		return;
	}

	display.clearDisplay();
	display.setCursor(4, 4);
	display.printf("Clearing %s", usingFram ? "FRAM" : "EEPROM");
	display.setCursor(4, 16);
	display.printf("Progress: %dK/%dK", current / 1000, total / 1000);
	display.display();
}

void setupDisplay() {
	display.begin(SSD1306_SWITCHCAPVCC, 0x3C); // Address 0x3C for 128x32
  display.cp437(true);
	display.setTextColor(WHITE);
	display.setRotation(2);
	display.clearDisplay();
	display.display();
}

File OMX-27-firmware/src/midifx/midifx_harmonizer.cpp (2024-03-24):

#include "midifx_harmonizer.h"
#include "../hardware/omx_disp.h"

namespace midifx
{
	enum HarmonizerPage
	{
		HARMPAGE_1,
		HARMPAGE_2,
		HARMPAGE_3
	};

	MidiFXHarmonizer::MidiFXHarmonizer()
	{
		params_.addPage(4);
		params_.addPage(4);
		params_.addPage(1);

		encoderSelect_ = true;

		playOrigin_ = true;

		for (uint8_t i = 0; i < 7; i++)
		{
			notes_[i] = 0;
		}
	}

	int MidiFXHarmonizer::getFXType()
	{
		return MIDIFX_HARMONIZER;
	}

	const char *MidiFXHarmonizer::getName()
	{
		return "Harmonizer";
	}

	const char *MidiFXHarmonizer::getDispName()
	{
		return "HARM";
	}

	MidiFXInterface *MidiFXHarmonizer::getClone()
	{
		auto clone = new MidiFXHarmonizer();

		clone->chancePerc_ = chancePerc_;
		clone->playOrigin_ = playOrigin_;

		for (uint8_t i = 0; i < 7; i++)
		{
			clone->notes_[i] = notes_[i];
		}

		return clone;
	}

	void MidiFXHarmonizer::onEnabled()
	{
	}

	void MidiFXHarmonizer::onDisabled()
	{
	}

	void MidiFXHarmonizer::noteInput(MidiNoteGroup note)
	{
		if (note.noteOff)
		{
			processNoteOff(note);
			return;
		}

		if (chancePerc_ != 100 && (chancePerc_ == 0 || random(100) > chancePerc_))
		{
			sendNoteOut(note);
			return;
		}

		if (playOrigin_)
		{
			sendNoteOut(note);
		}

		int8_t origNote = note.noteNumber;

		int8_t sentNoteNumbers[7] = {0, 0, 0, 0, 0, 0, 0};

		for (uint8_t i = 0; i < 7; i++)
		{
			if (notes_[i] != 0)
			{
				int8_t newNoteNumber = constrain(origNote + notes_[i], 0, 127);

				bool noteAlreadyPlayed = false;

				for (uint8_t j = 0; j < 7; j++)
				{
					if (sentNoteNumbers[j] == newNoteNumber)
					{
						noteAlreadyPlayed = true;
						break;
					}
				}

				if (!noteAlreadyPlayed)
				{
					note.noteNumber = constrain(origNote + notes_[i], 0, 127);
					sendNoteOut(note);
					sentNoteNumbers[i] = newNoteNumber;
				}
			}
		}
	}

	void MidiFXHarmonizer::loopUpdate()
	{
	}

	void MidiFXHarmonizer::onEncoderChangedEditParam(Encoder::Update enc)
	{
		int8_t page = params_.getSelPage();
		int8_t param = params_.getSelParam();

		auto amt = enc.accel(1);

		bool modNote = false;
		int noteIndex = 0;

		if (page == HARMPAGE_1)
		{
			if (param == 0)
			{
				playOrigin_ = constrain(playOrigin_ + amt, 0, 1);
			}
			else
			{
				modNote = true;
				noteIndex = param - 1;
			}
		}
		else if (page == HARMPAGE_2)
		{
			modNote = true;
			noteIndex = param + 3;
		}
		else if (page == HARMPAGE_3)
		{
			amt = enc.accel(5);
			chancePerc_ = constrain(chancePerc_ + amt, 0, 100);
		}

		if (modNote)
		{
			notes_[noteIndex] = constrain(notes_[noteIndex] + amt, -126, 127);
		}

		omxDisp.setDirty();
	}

	void MidiFXHarmonizer::onDisplayUpdate(uint8_t funcKeyMode)
	{
		omxDisp.clearLegends();

		int8_t page = params_.getSelPage();

		uint8_t starti = 0;
		// uint8_t endi = 0;

		switch (page)
		{
		case HARMPAGE_1:
		{
			omxDisp.legends[0] = "ORIG";

			omxDisp.legendVals[0] = -127;
			omxDisp.legendText[0] = playOrigin_ ? "ON" : "OFF";

			starti = 0;
			// endi = 3;
		}
		break;
		case HARMPAGE_2:
		{
			starti = 3;
			// endi = 7;
		}
		break;
		case HARMPAGE_3:
		{
			omxDisp.legends[0] = "CHC%";

			omxDisp.useLegendString[0] = true;
			omxDisp.legendString[0] = String(chancePerc_) + "%";

			// // const char* perc[4 + sizeof(char)];
			// // sprintf(perc, "%d", chancePerc_);

			// tempStringVal_ = String(chancePerc_) + "%";

			// // char perc = static_cast<char>(chancePerc_);
			// omxDisp.legendVals[0] = -127;
			// // omxDisp.legendText[0] = &perc + "%";
			// omxDisp.legendText[0] = tempStringVal_.c_str();
		}
		break;
		default:
			break;
		}

		if (page == HARMPAGE_1 || page == HARMPAGE_2)
		{
			for (uint8_t i = 0; i < 4; i++)
			{
				if (page == HARMPAGE_1 && i == 0)
					continue;

				// char ch = static_cast<char>(starti + 2);

				tempStrings[i] = "NT " + String(starti + 2);
				omxDisp.legends[i] = tempStrings[i].c_str();
				if (notes_[starti] == 0)
				{
					// omxDisp.legendVals[i] = -127;
					// omxDisp.legendText[i] = "--";

					omxDisp.useLegendString[i] = true;
					omxDisp.legendString[i] = "--";
				}
				else if (notes_[starti] > 0)
				{
					omxDisp.useLegendString[i] = true;
					omxDisp.legendString[i] = "+" + String(notes_[starti]);

					// // char nt = static_cast<char>(notes_[starti]);
					// omxDisp.legendVals[i] = -127;

					// tempStringVal_ = "+" + String(notes_[starti]);
					// omxDisp.legendText[i] = tempStringVal_.c_str();
					// // omxDisp.legendText[i] = "+" + nt;
				}
				else
				{
					omxDisp.legendVals[i] = notes_[starti];
				}

				starti++;
			}
		}

		omxDisp.dispGenericMode2(params_.getNumPages(), params_.getSelPage(), params_.getSelParam(), getEncoderSelect());
	}

	int MidiFXHarmonizer::saveToDisk(int startingAddress, Storage *storage)
	{
		// Serial.println((String) "Saving mfx harmonizer: " + startingAddress); // 5969
		storage->write(startingAddress + 0, chancePerc_);
		storage->write(startingAddress + 1, (bool)playOrigin_);
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

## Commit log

2020-12-25 start on bom
2020-12-25 add plates
2020-12-29 work on multi-track seq
2021-01-10 updated build/bom
2021-01-18 add teensy jig pix
2021-01-22 update BOM and readme
2021-01-22 Update BOM/Readme
2021-02-04 display/led-color tweaks
2021-03-02 rework midi
    move midi to MM.cpp, cleanup
    [noteoffs.cpp]
2021-03-22 add plates-layout
2021-03-22 set pins to 1.0 boards
2021-03-24 led pix
2021-03-25 dont change CV pitch on note off
2021-04-05 stepRecord led fix
2021-04-20 bugfix: keep track of last midi note sent
    this allows us to ensure that when we release a key, we send the correct
    noteoff message, even if the octave has changed
2021-04-22 - save pattern length, channel, mute and reverse in a PatternSettings struct - fixed sendPots sending on the previously selected seq midi channel in midi mode - rotatePattern now takes the pattern in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
    [config.h]
2021-05-03 fixed param page switching
2021-05-06 Revert "adding save UI"
    This reverts commit b038058ba2a0610087bc62abc682ff2907e3cdd6.
    [config.h]
2021-05-06 tweak save, add config for dev/midi boards
2021-05-07 fixed step amt bugs enhanced reverse autoreset logic fixed reverse step bug reorder PatternSettings struct for mem efficiency update eeprom param setting size 5 byte for larger struct rebase and fixu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
    [config.h]
2021-05-11 fix for bad note len, add eeprom reset
    [config.h, eeprom_clear.ino]
2021-05-12 added nl, upd comment, missing semi-colons
    [config.h]
2021-05-12 fix for note len bug and missing ';'
    [config.h]
2021-05-16 combine per patt swing and auto-reset
    [config.h]
2021-05-19 fix note spray/disp cleanup
    [config.h]
2021-05-19 pattlen leds and OM tweaks
2021-05-20 per-patt CV on/off and fixes
    [config.h, consts.h, noteoffs.cpp]
2021-05-22 fix nextStepTime and mdiv values
    [config.h]
2021-05-31 rework swing to 96PPQ, lotsa cleanup
    [config.h, consts.h]
2021-06-10 add velocity in step record
2021-06-11 rework step_play to trig_play
    [config.h, consts.h]
2021-08-12 Update Build.md
    add link for flashing teensy
2021-10-12 small fixes to FRAM storage
    [OMX-27-firmware.ino, storage.cpp]
2021-10-12 fix renamed method that was missed
    [OMX-27-firmware.ino]
2021-10-17 seqpage led refine
2021-10-31 fix stuck led in steprecord
    [OMX-27-firmware.ino]
2021-11-13 fix Seq param count for page changes
    [OMX-27-firmware.ino]
2021-11-16 fix capacity for FRAM
2021-11-19 fix LEDs in NoteSelect
    [OMX-27-firmware.ino, config.h]
2021-11-19 fix noteselect leds and playhead position bug
    [OMX-27-firmware.ino, config.h]
2021-11-19 pattparams patternlen led fix, todo update
    [OMX-27-firmware.ino]
2021-11-21 add include guard & include arduino header in sequencer code (to appease VSCode mostly)
2021-11-21 arduino header is case sensitive
2021-11-21 lil more find and replace
    [OMX-27-firmware.ino]
2021-11-21 Fix pattern len, formatting
    [config.h, consts.h]
2021-11-22 bug fixes for long patterns
    [OMX-27-firmware.ino]
2021-11-26 fix fram capacity
2021-11-28 reworked to change MESSAGE macro to function
    [OMX-27-firmware.ino, config.h]
2022-01-27 disable autoreset on S1, docs fix, random seed fix
    [OMX-27-firmware.ino]
2022-01-28 Fix S1 glitches, Step Record fixes
    Step record now properly shows step position for patterns longer than 16
    [OMX-27-firmware.ino]
2022-01-29 fix up pattern start address and bit wirth for pattern state
    [OMX-27-firmware.ino]
2022-01-29 docs update, remove prints, add hex
2022-01-30 fixes for long press
    [OMX-27-firmware.ino]
2022-01-31 fix missing params in initPatterns
    [OMX-27-firmware.ino]
2022-01-31 update hex for initpatterns fix
    [config.h]
2022-02-05 wire sysex into app setup
2022-02-05 fix "new" and add comments
    [OMX-27-firmware.ino, sysex.cpp]
2022-02-05 comment out serial.prints
2022-02-06 fix midi noteoff from bad merge
    [OMX-27-firmware.ino]
2022-02-07 use teensy-cli to upload scripts, and add custom task for clearing storage
2022-02-07 fix note select toggle
    [OMX-27-firmware.ino]
2022-06-08 fix m8channel ccs, snapshots
    [OMX-27-firmware.ino]
2022-06-08 fix AUX in M8AUX
    [OMX-27-firmware.ino]
2022-06-10 m8AUX led fix
2022-06-10 mute/solo leds disable on snap load
    [OMX-27-firmware.ino]
2022-07-13 Save and load debuging. Serial prints disabled.
2022-07-13 Small fix to prevent Sequencer LEDs from rendering if screensaver is on.
    [OMX-27-firmware.ino]
2022-07-13 Removing sequencer cross-class dependancy
    Removes the extern function show_current_step from sequencer. The function always is called for the playingPattern which won't change in the sequencer functions so no need to have sequencer update the drawing for this.
    The sequencer_mode will now call this function after calling doStep functions.
    Renamed omxLeds.updateLeds to updateBlinkStates which describes the function better.
    [OMX-27-firmware.ino, omx_leds.cpp]
2022-07-14 Sets LED colors for scale.
2022-07-14 Made holding aux turn encoder change selected param for midi mode.
2022-07-15 Fixes XY values not updating when switching patterns.
2022-07-15 Fix for knob params randomly thinking they have changed.
    [OMX-27-firmware.ino, omx_mode_midi_keyboard.cpp]
2022-07-15 Setup to use analog delta for pot param switching
2022-07-15 Updates channel lock mode to show current playing step.
2022-07-15 Increased delta for display switching
2022-07-15 Changes "Channel" to "Inst", auto changes page in inst lock mode to reflect current playing page.
2022-07-15 Adds shortcuts for Xaos and Accent, main page lights up LEDs for each instrument.
2022-07-16 Midiception led and stuck aux fix.
    [omx_mode_midi_keyboard.cpp]
2022-07-16 Removed prints
2022-07-19 Fixes page switching in S1 & S2
    Exits page switch after releasing F1 && F2
    [OMX-27-firmware.ino, consts.h]
2022-07-19 Fixes LED rendering of seqPos
2022-07-19 Fix step record led position.
2022-07-20 Step Record LEDs were turning off bottom row.
2022-07-20 Implements param manager to enable clicking encoder to toggle between selecting and modifying params.
2022-07-20 Updated generic display rendering to display if in encoder select mode or not and to only display number of available pages.
2022-07-21 Makes grids and sequencer switch encoder into edit mode when quickselecting params or when entering step record mode.
2022-07-21 Sequencer code cleanup and bugfix.
    [config.h]
2022-07-21 Fixes display not updating when switching the main sequencer mode.
2022-07-21 Makes modes have default param and page when entering mode. Fixes additional LEDs being stuck on in GR Instrument select.
    [OMX-27-firmware.ino, config.h, omx_mode_midi_keyboard.cpp]
2022-07-21 fix note-on on key 26 from midimodeception
    [omx_mode_midi_keyboard.cpp]
2022-07-22 Architecting framework for MidiFX and submodes.
2022-07-23 This fixes entering midi M8 Macro mode.
    [omx_mode_midi_keyboard.cpp]
2022-07-23 Cleaner fix for entering / exiting M8 mode.
    [omx_mode_midi_keyboard.cpp]
2022-07-23 Removing prints, making randomizer variables display correctly.
    [midifx_chance.cpp, midifx_randomizer.cpp]
2022-07-23 Defaults randomizer chance to 100, fix for random happening when chance is 0
    [midifx_randomizer.cpp]
2022-07-23 Scale MidiFX work, expect rootNote not correct.
    [config.h, midifx_scaler.cpp]
2022-07-23 Version bump, removed prints.
2022-07-24 Added RamMonitor to make sure memory isn't leaking.
    [OMX-27-firmware.ino]
2022-07-24 Fixes. memory leak from trigger vectors when changing fx
    [OMX-27-firmware.ino, midifx_interface.cpp, midifx_interface.h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]
2022-07-24 fix version number for release
    [OMX-27-firmware.ino, config.h]
2022-07-28 5 MidiFX Slots for fun and profit!
2022-07-28 Forgot to update leds
2022-07-28 LED Fix
2022-08-10 Moved code out of folders to compile with teensyduino.
2022-08-10 null checks to avoid crashing
    [omx_leds.cpp, omx_mode_midi_keyboard.cpp]
2022-08-10 Fixed scale_ null pointer crash.
    [omx_mode_midi_keyboard.cpp]
2022-08-13 MidiFXGroups now shared across modes. Midi Keyboard has 5 midiFX slots to switch between.
2022-08-13 Groups can have 8 mfx slots
2022-08-13 Couple bugfixes.
2022-08-14 Making LEDs give more feedback on config.
2022-08-14 add LED testing details
2022-08-15 Minor fixes, changelog notes.
    [OMX-27-firmware.ino, config.h]
2022-08-16 1.11.2 alpha New features/bug fixes
    [OMX-27-firmware.ino, config.h, omx_disp.cpp]
2022-08-16 add wstring.h for compile error fix
    [storage.cpp]
2022-08-16 Changed header bytes to not interfer with sysex config.
    [OMX-27-firmware.ino]
2022-08-16 WString causing pots to not work.
    [storage.cpp]
2022-08-17 Switched order of note, chan, length params.
2022-08-17 Sequencer cut paste
2022-08-17 Adds note lengths below 1 to the sequencer. noteoffs improvement to avoid stuck notes at fast bpms and small note lengths. Reduced struct size of grids saves and euclid saves
    [config.h, noteoffs.cpp]
2022-08-17 Fixes notes being offset.
    [noteoffs.cpp]
2022-08-19 Couple UI tweaks.
2022-08-21 Keys and LEDs for arp.
2022-08-22 Added Arduino include to storage
2022-08-23 Slot rendering for showing MFX position
2022-08-25 Chord Edit LED UI
2022-08-27 Attempt to fix arps
    [midifx_arpeggiator.cpp]
2022-08-31 Set bool defaults to false to fix corrupt screen rendering.
    [midifx_interface.h]
2023-02-19 Fix platformio add clear storage hexes
    [clear_storage.ino]
2023-03-04 fix for analogDelta too small
    [OMX-27-firmware.ino]
2023-06-26 add T4.0 to Teensy compile info
2023-07-05 Update led count
2023-08-30 tweak for auto config of board type
2023-10-01 various tweaks
    add shift to m8 mod
    reorg hexes
    set board type automatically based on arduino settings
    update device name
2024-01-30 screensaver update to use current pot value to set color
2024-01-30 Update README.md - add Adafruit_MCP4725 to Library list and a screenie of the Arduino IDE settings
2024-01-31 remove extraneous lines, add ArduinoIDE build folder to `.gitignore`
2024-02-11 Fixes arp getting having stuck notes if chance is lower than 100
    Problem was that if chance kicked in and the notes did not get sent to the arp on a noteon event, then when the noteoff event happend, if it got sent to arp instead of passing through, a note off would not be sent for the note and a single note will get stuck on. The arp could also get stuck, acting like it is in hold mode.
    To fix this, I tracked notes getting passed through using trackingNoteGroupsPassthrough for up to 8 notes. notes with fixed lengths ignored since they will turn off automatically.
    By tracking these notes, I pass them through for noteoffs in the case they were previously passed through noteons.
    [midifx_arpeggiator.cpp]
2024-02-14 Added LEDs
2024-02-14 AUX Locking, put octave led render in omxLED function. Change params with encoders
2024-02-15 Adds ability to change default velocity in midi keyboard mode.
2024-02-20 Fixes arp from always being on chan 1
    [midifx_arpeggiator.cpp]
2024-02-21 Fixes glitchy mode display
    [OMX-27-firmware.ino, omx_disp.cpp]
2024-02-21 Copy Paste Drum Keys. Holding Drum Key toggles encoder select.
2024-02-23 Saving/loadign mfx chords to storage. Fixed other save problems with other mfx, missing variables or rolling over.
    [midifx_arpeggiator.cpp, midifx_chord.cpp, midifx_scaler.cpp]
2024-02-24 Fixing some midifx selector bugs for note offs and length 0
    [midifx_selector.cpp]
2024-02-24 Fixes selector length of 0 notes from getting stuck.
    [midifx_selector.cpp]
2024-02-25 Each note now has it's own trigger time so they won't all be synced together.
    [midifx_repeat.cpp]
2024-02-26 Repeat now handling fixed length notes and note tracking.
    [midifx_arpeggiator.cpp, midifx_repeat.cpp]
2024-02-27 Adds fading of rates and velocity
2024-03-01 Adds notemaster utility to avoid code duplication.
    [midifx_repeat.cpp]
2024-03-01 rand midi chan gives stuck notes, disabling for now.
    [midifx_randomizer.cpp]
2024-03-02 Lots of UI bugfixes, MidiFX QuickEdit mode
    [config.h, midifx_arpeggiator.cpp, midifx_chance.cpp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]
2024-03-03 Fixes CV Gate going off and adds CV trigger modes for legato and retrig
    [OMX-27-firmware.ino, config.h, consts.h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]
2024-03-16 Fix Scale Corruption; disallow Lock and Group changes when scale is off
    [config.h, omx_mode_midi_keyboard.cpp]
2024-03-25 Might fix T4 pots in Grids
    [OMX-27-firmware.ino, config.h]
2024-09-01 Update config.h
    fix version and added notes
    [config.h]
2024-09-01 Update OMX-27-firmware.ino
    version fix
    [OMX-27-firmware.ino]
2024-10-11 Update omx_screensaver.cpp
    darken leds if knob 5 is turned all the way right
2025-11-01 rework structure for version3
    new RP2040 code and reorganization
    [ClearUI_Input.cpp]
2025-11-03 Picture updates and battery page
    [omx-27_battery_box_1a.stl, omx-27_battery_box_1b.stl]
2025-11-03 rename battery readme
2025-11-03 Change firmware environment from teensy31 to pico
2025-12-05 update mouser link for battery
2026-11-08 Fix links for recommended battery sources
    Updated links to Mouser and Digikey for battery recommendation.
